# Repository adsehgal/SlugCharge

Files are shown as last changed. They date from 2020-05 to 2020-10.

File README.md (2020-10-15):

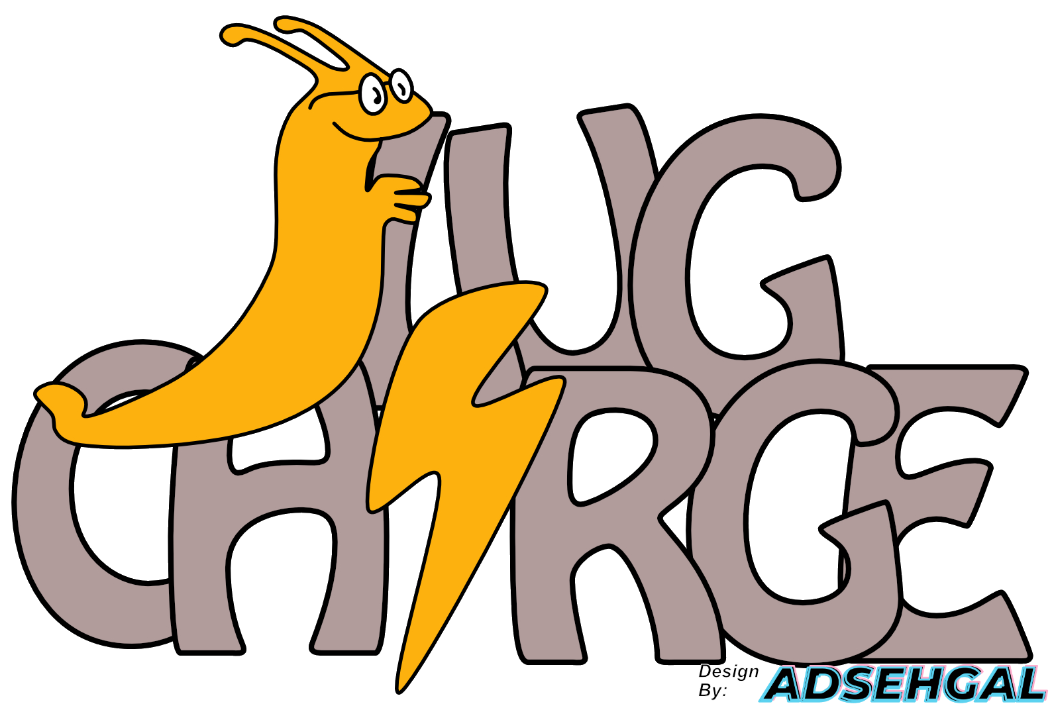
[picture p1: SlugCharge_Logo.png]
SlugCharge Logo

# *SlugCharge*

SlugCharge was a student run project geared towards helping the homeless communit of Santa Cruz, CA. The project was led by four Electrical Engineering students at the University of California, Santa Cruz. The team aimed towards providing solar powered charging stations to the community so they can stay conencted with family and potential employers that may turn their life around! 

### My Roles

* PCB Design
* Mechnical Design
* Graphic Design
* Video Creation

<!-- START OF PCB SECTION -->
### PCB Design

#### PCB #1 - Testbench V1.0
[Project Files](https://github.com/adsehgal/SlugCharge/tree/master/SlugCharge_Testbench_V1.0) - KiCad
* We first started with making a testbench that was able to run our code and interact with the required I/O </br>
    Requirements:</br>
    * Utilize the **ATmega2560** as the main processor
    * Be **easliy programmable** for future code updates
    * Contain **visual annunciators** for easy state tracking 
    * Utilize **breakout pins** for off-board I/O control
    * Should **not require off-board voltage regulation**
    * Should be easily **hand assembled**
    * Restricted to a **2-layer PCB**
* The design was started off with referring to the Arduino Mega Development board and adapted to fit the required I/O:
<p align="center">
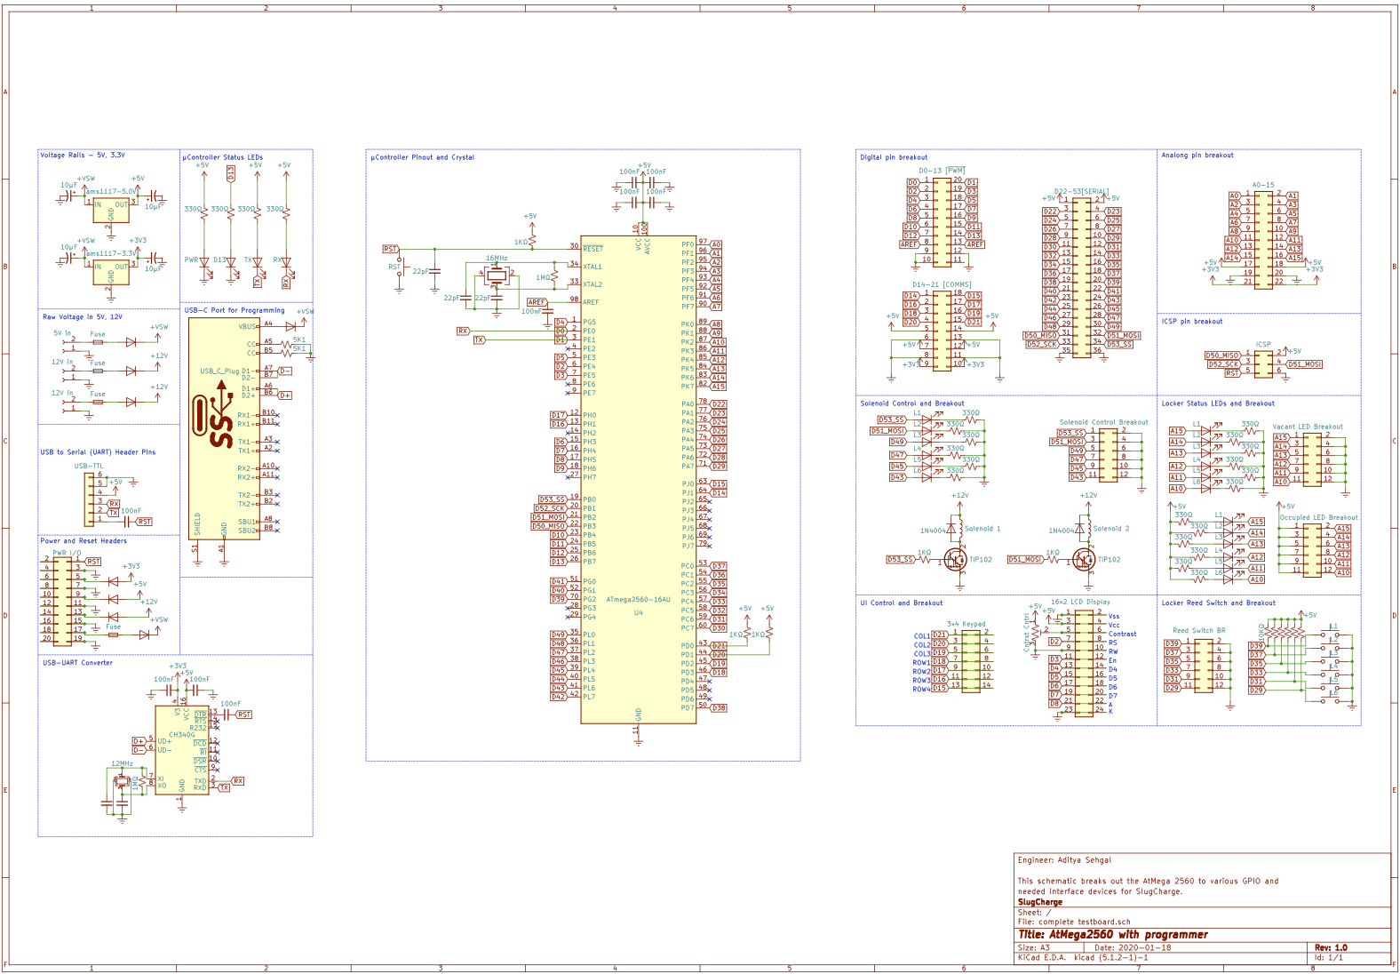
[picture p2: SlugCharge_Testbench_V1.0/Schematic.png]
  
</p>

* Next I moved onto laying out the PCB as per the requirements to get the following design:

</p>
<p align="center">
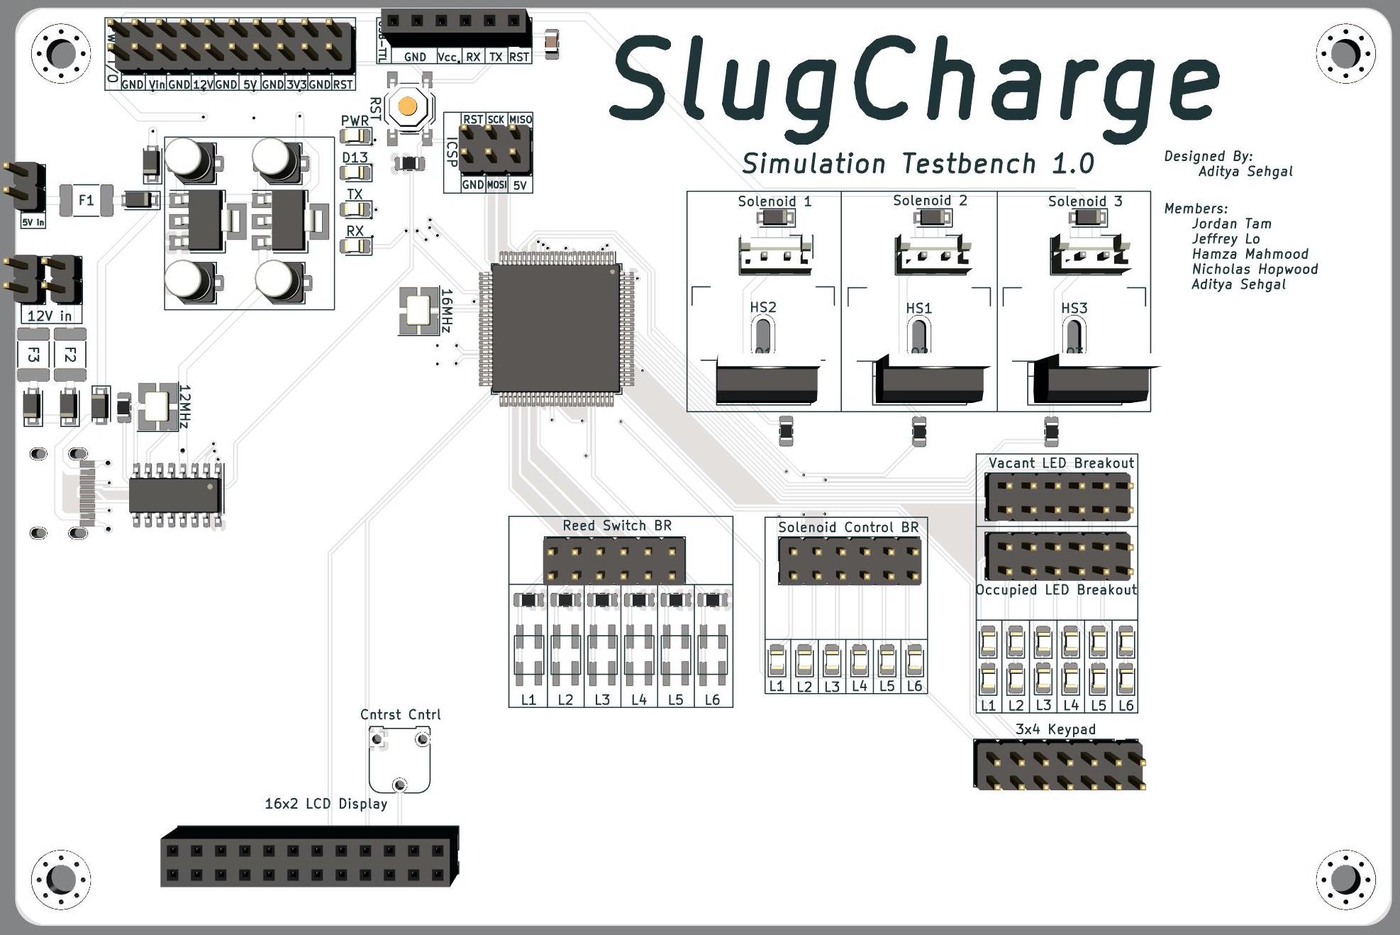
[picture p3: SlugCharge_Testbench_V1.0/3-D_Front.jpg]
  
</p>

#### PCB #2 - Motherboard V2.4
[Project Files](https://github.com/adsehgal/SlugCharge/tree/master/SlugCharge_Motherboard) - KiCad
* We followed the success of the testbench with a custom motherboard </br>
    Requirements:</br>
    * Utilize the **ATmega2560** as the main processor
    * Be **easliy programmable** for future code updates
    * Should **not require off-board voltage regulation**
    * Should **not be directly connected** to the individual lockers
    * Restricted to a **2-layer PCB**

To keep the motherboard physically isolated from the individual lockers, we decided to design a daughterboard for each locker that would connect to the motherboard via IDC cables

<p align="center">
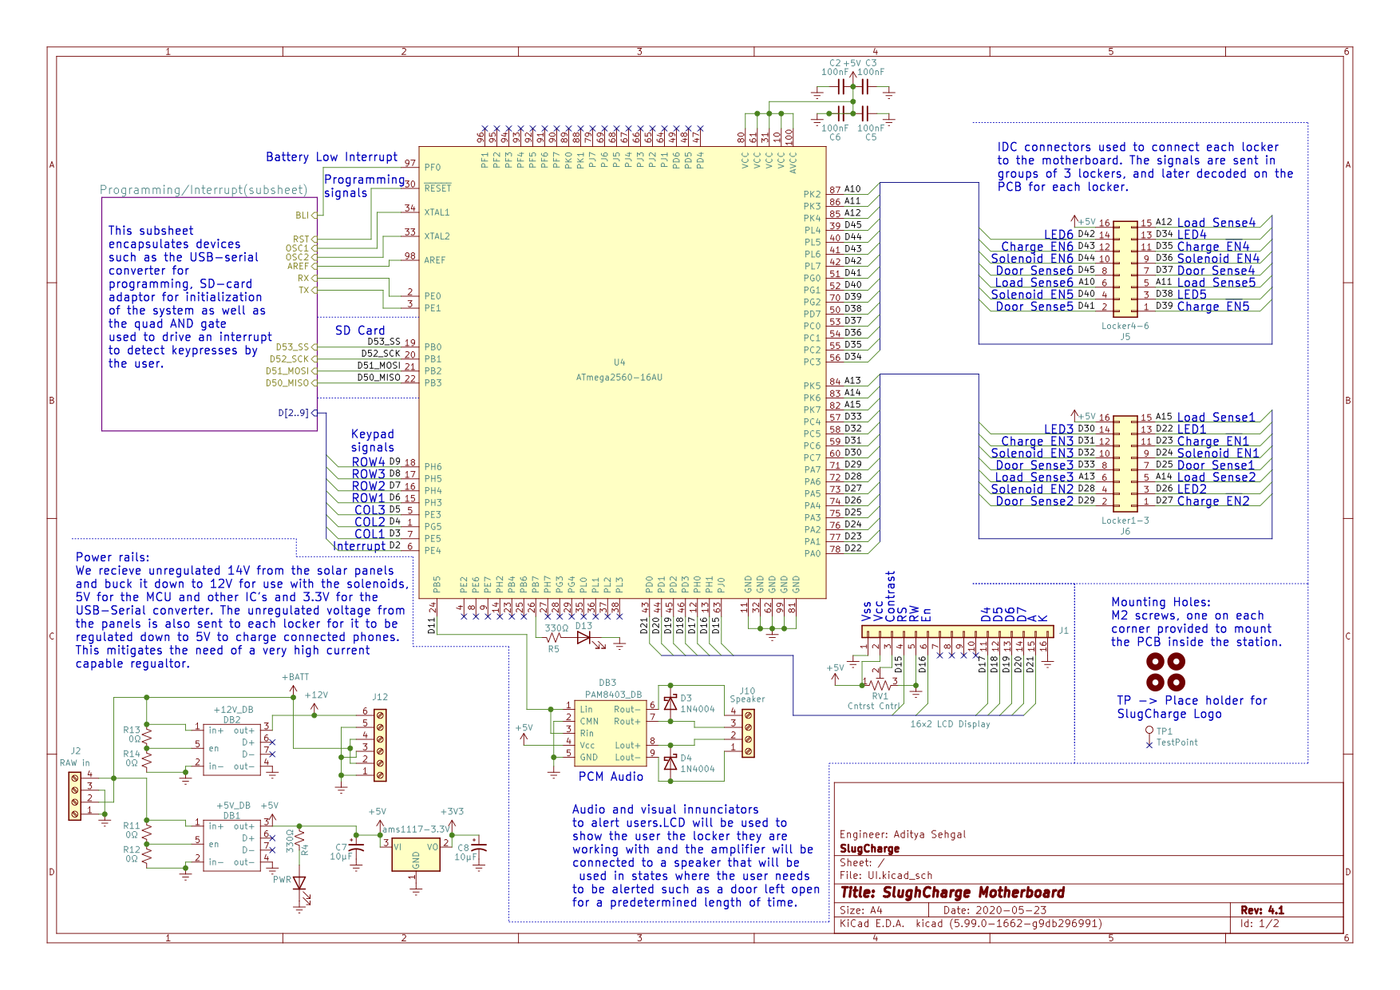
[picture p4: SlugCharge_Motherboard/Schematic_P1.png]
  
</p>
<p align="center">
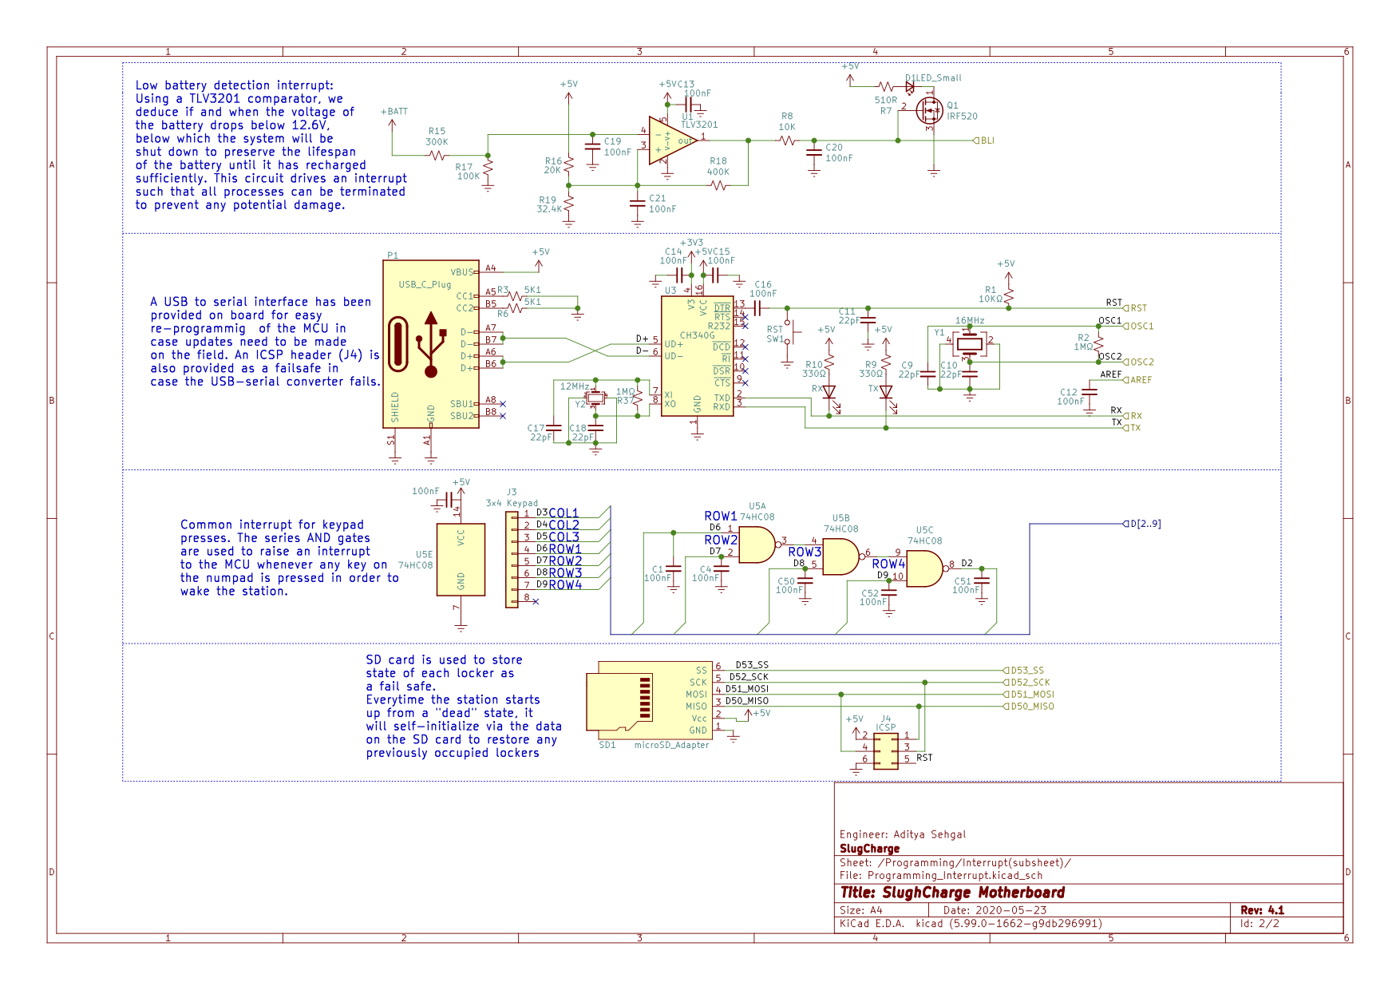
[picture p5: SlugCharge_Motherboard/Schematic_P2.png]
  
</p>

* Next I moved onto laying out the PCB as per the requirements to get the following design:
<p align="center">
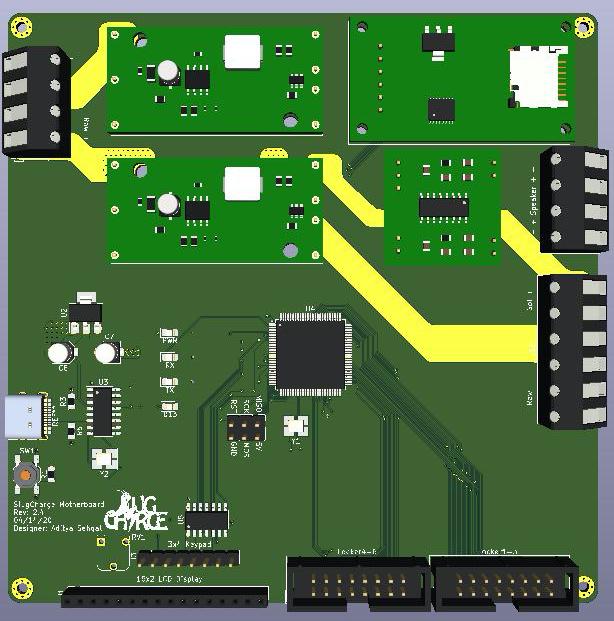
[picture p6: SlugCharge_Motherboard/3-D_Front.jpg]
  
</p>

#### PCB #3 - Daughterboard V4.0
[Project Files](https://github.com/adsehgal/SlugCharge/tree/master/SlugCharge_Daughterboard) - KiCad
* We followed the success of the testbench with a custom daughterboard </br>
    Requirements:</br>
    * Connect with the motherboard **using IDC cables**
    * Provide a **voltage regulator per locker** to charge devices
    * Should be **easily replacable**
    * Should **not contain any complex devices**
    * Restricted to a **2-layer PCB**

To charge the devices in each locker, we decided to give each of these PCBs a second voltage regulator PCB for easy servicability. This regulator was chose to be the [TPS62133](https://github.com/adsehgal/SlugCharge/tree/master/TPS62133)

<p align="center">
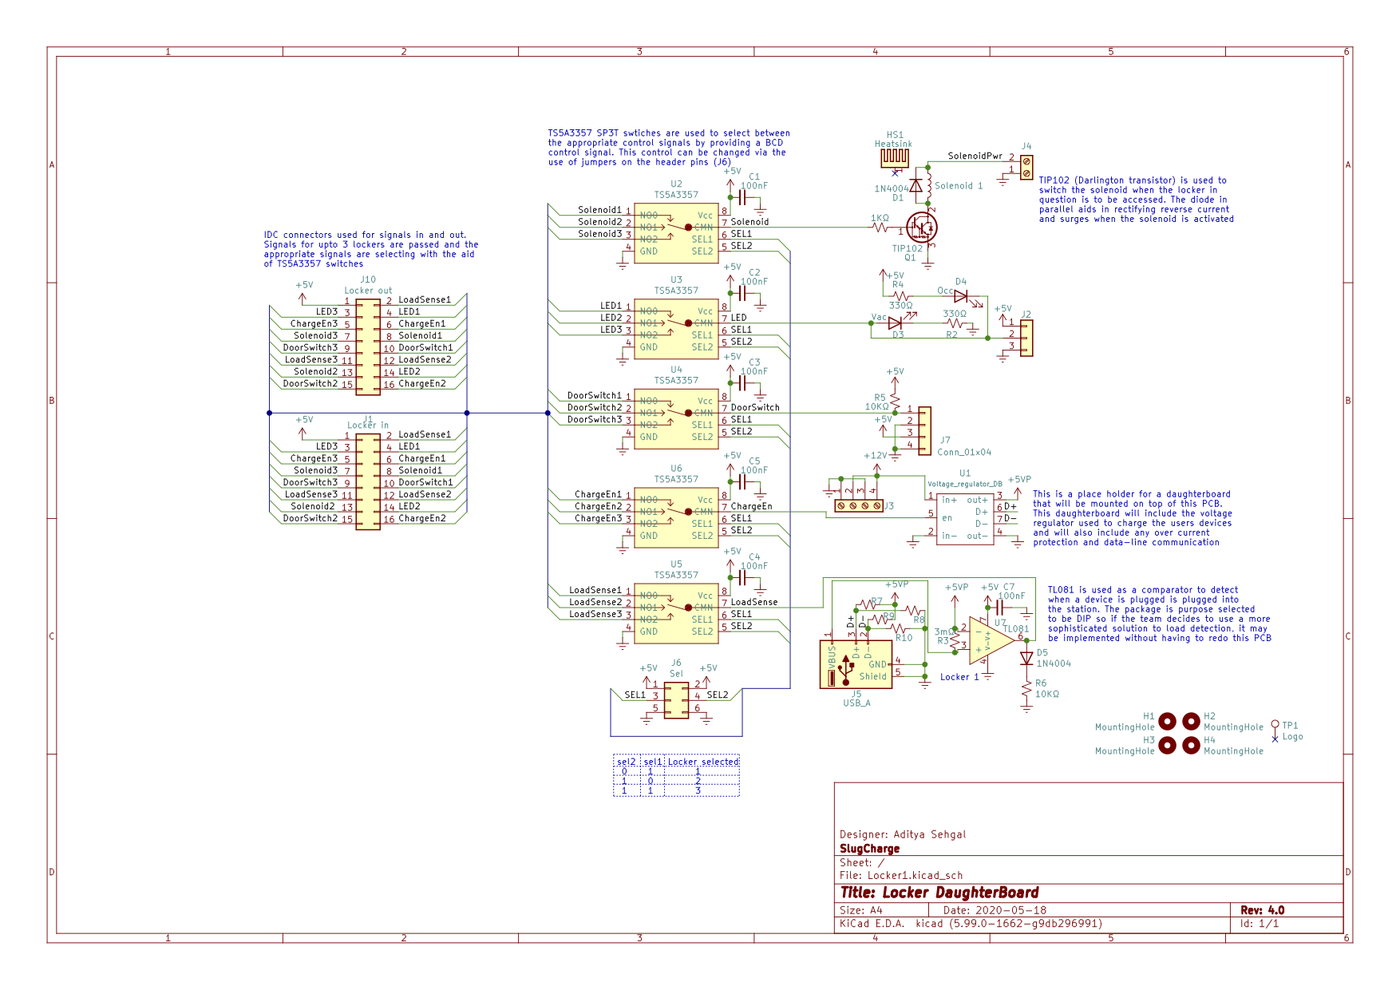
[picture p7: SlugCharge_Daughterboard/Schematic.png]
  
</p>

* Next I moved onto laying out the PCB as per the requirements to get the following design:
<p align="center">
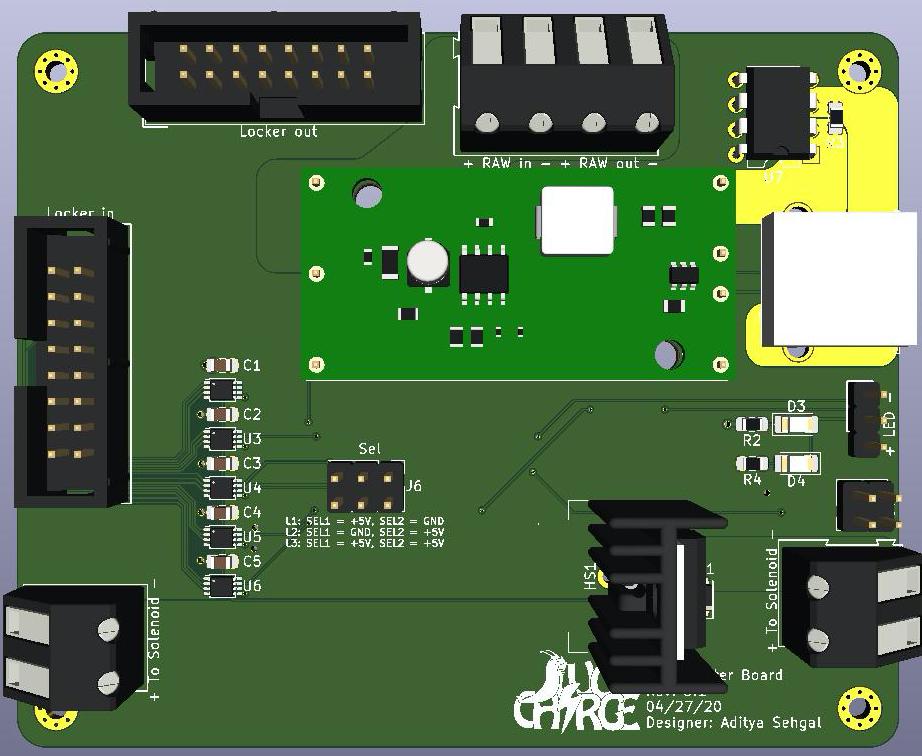
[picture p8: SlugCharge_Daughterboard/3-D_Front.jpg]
  
</p>
<!-- END OF PCB SECTION -->

<!--START OF  VOLTAGE REGULATOR -->
### Voltage Regulator selection

<!-- END OF VOLTAGE REGULATOR -->
[Regulator Comparison Sheet](https://github.com/adsehgal/SlugCharge/blob/master/Regulator_selection.pdf) - PDF</br>
[Regulator Design Files](https://github.com/adsehgal/SlugCharge/tree/master/TPS62133) - KiCad
* I decided to use the TPS62133 constant 5.0V switching regulator to charge connected devices. This regulator was selected for the following reasons:  </br>
  * Relatively low cost
  * Extremely high efficiency
  * Very low output ripple
  * On chip enable pin
  * High current capability
  
<!-- START OF MECH SECTION -->
### Mechanical Design
[Mechanical Drafts](https://github.com/adsehgal/SlugCharge/tree/master/Mechanical) - Fusion360
* Given the restrictions due to COVID-19, the team was unable to build the station, however we rendered a 3-D model for any future teams that may be intereste in taking up this project</br>
    Requirements:</br>
    * Be designed to accomodate the **average person height**
    * Hold at least **6 devices simultaneously**
    * Be resistant to **tampering**
    * **Solar Powered**

We drafted the 3-D model and orthographic drawings using Fusion360. This was done to aid future teams who may be interested in continuing this project

<p align="center">
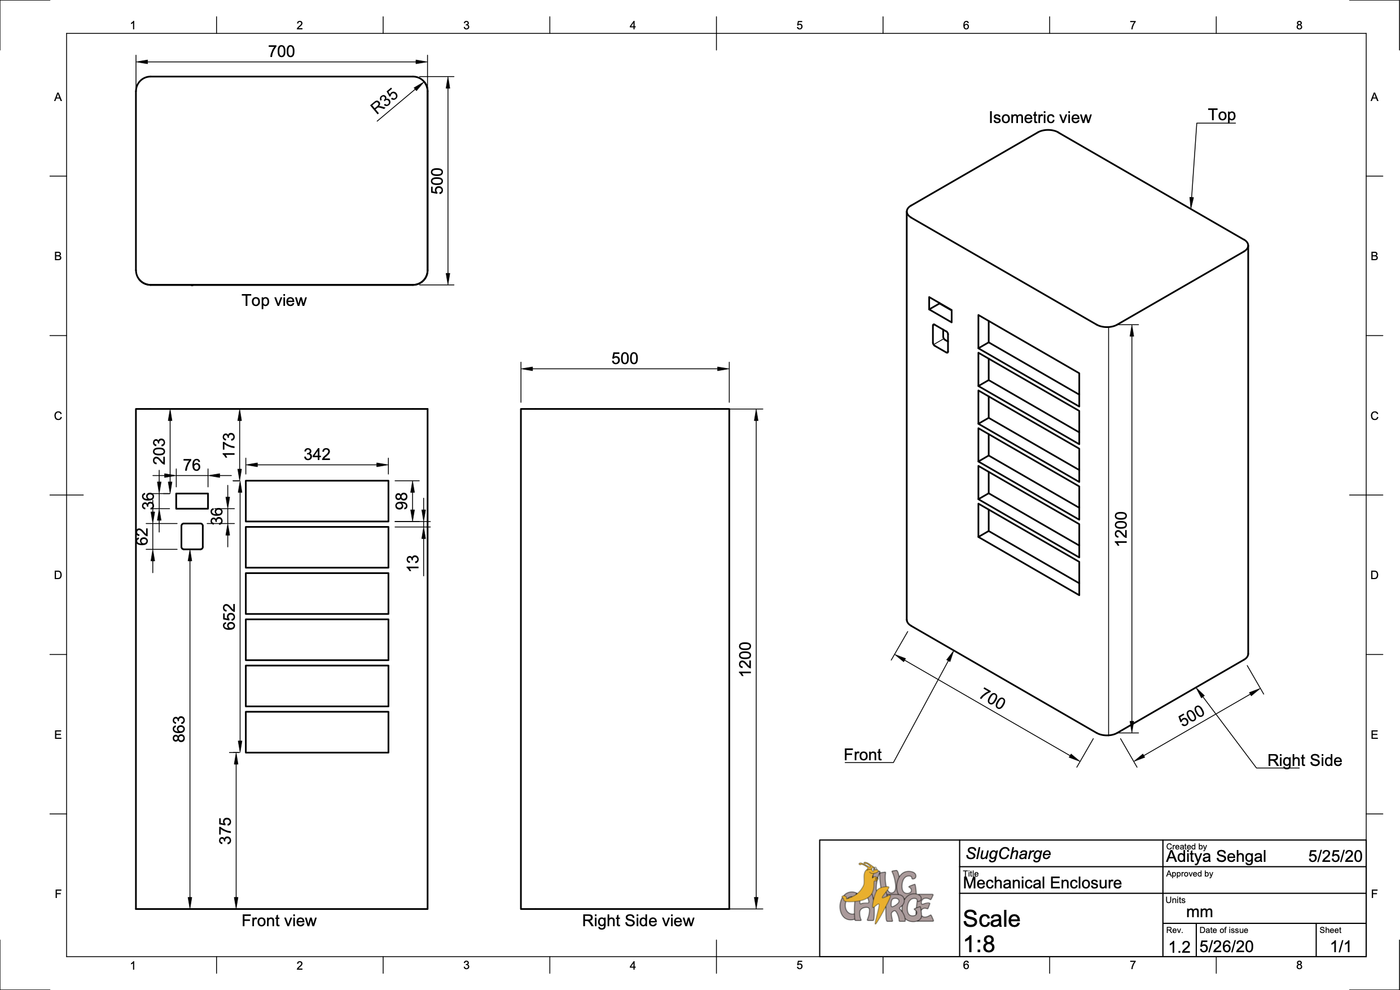
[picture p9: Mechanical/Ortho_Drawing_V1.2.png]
  
</p>
<p align="center">
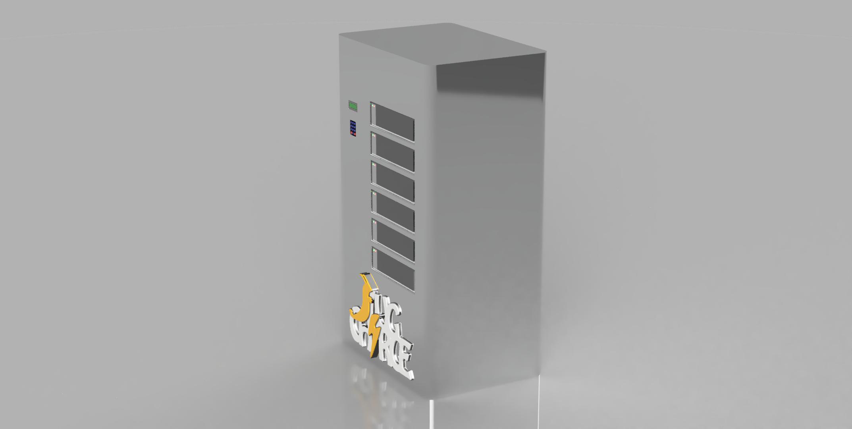
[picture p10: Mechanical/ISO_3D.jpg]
  
</p>

To educate the community how to use the station we developed two short instructional videos showing so. These can be downloaded via the following hyperlinks

* [Selecting a locker](https://github.com/adsehgal/SlugCharge/blob/master/Mechanical/Get_Device_Final.avi)
* [Retrieving your device](https://github.com/adsehgal/SlugCharge/blob/master/Mechanical/Select_Locker_FInal.avi)
<!-- END OF MECH SECTION -->

### Final Report
[The final team report can be found here](https://github.com/adsehgal/SlugCharge/blob/master/Final_report.pdf)

## Built With

* [KiCad](https://kicad-pcb.org/) - Used to design schematics and PCB layouts
* [Fusion 360](https://www.autodesk.com/products/fusion-360/overview) - Used to design mechanical drafts
* [Arduino IDE](https://www.arduino.cc/) - Used to code the charging station functionaility
* [Affinity Designer](http://affinity.serif.com/) - Used to design logos and other 2-D graphics
* [VSDC Video Editor](http://www.videosoftdev.com/) - Used to design education videos of the charging station

## Authors

* **Aditya Sehgal** - *Systems Integration lead, PCB Designer, Mechanical Drafter and Graphic Designer* - [AdSehgal](https://github.com/AdSehgal)

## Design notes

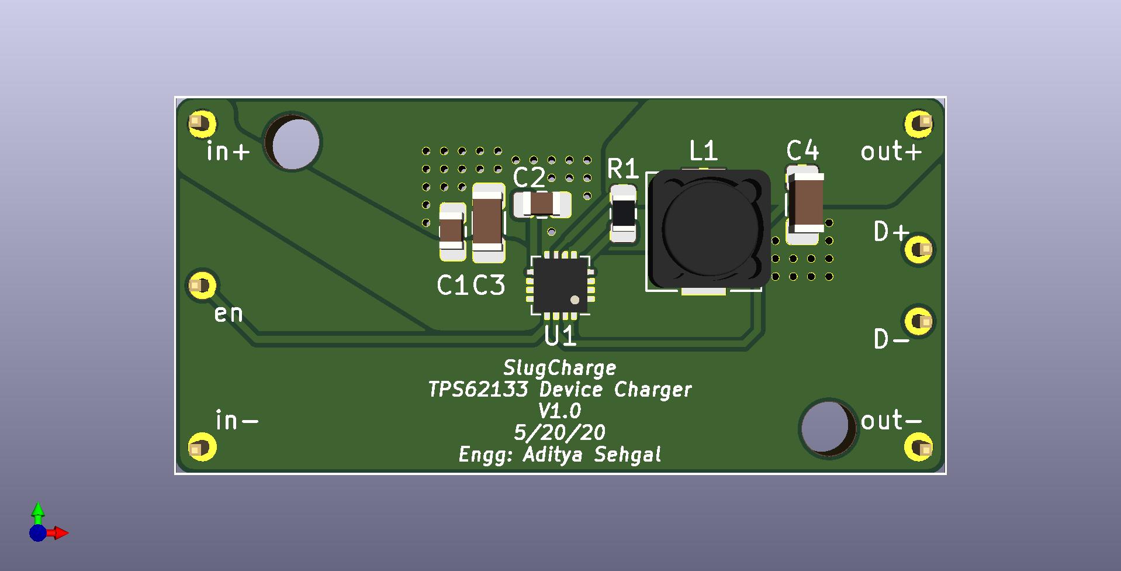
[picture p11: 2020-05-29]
TPS62133/Schematic & Layout PDFs/VReg_3D_Image.jpg

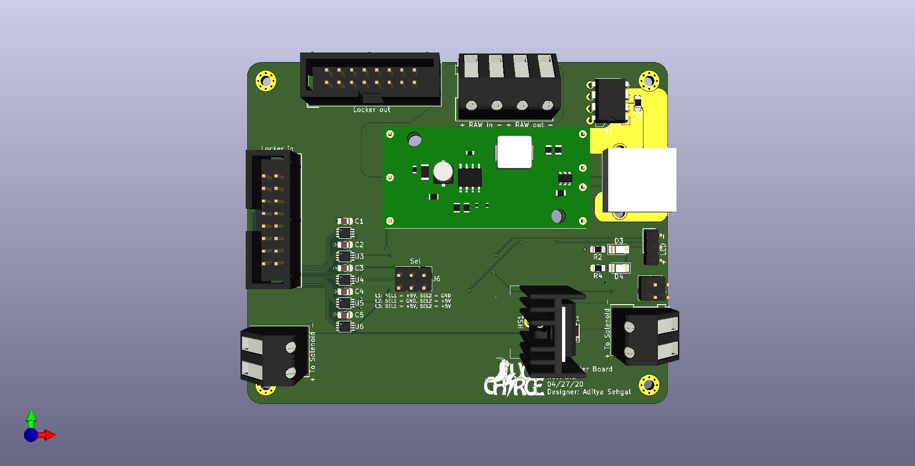
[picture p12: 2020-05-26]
SlugCharge_Daughterboard/Schematic&Layout PDFs/DB_3D_Image.jpg

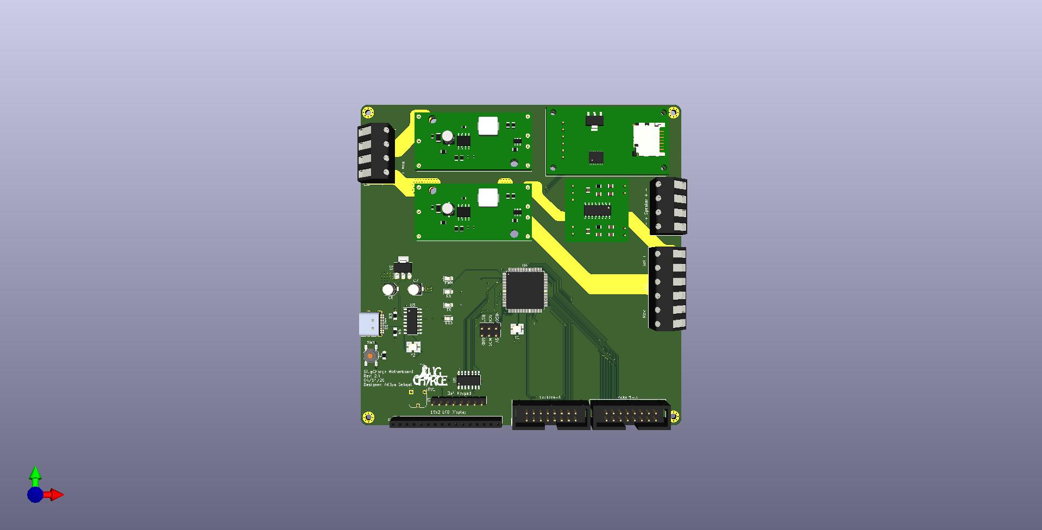
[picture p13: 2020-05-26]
SlugCharge_Motherboard/Schematic&Layout PDFs/MB_3D_Image.jpg

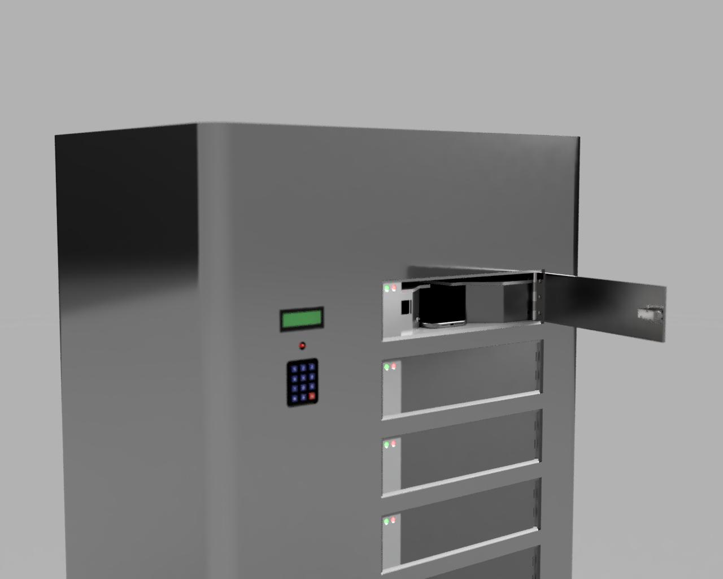
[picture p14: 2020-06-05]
3D Housing Model/3D_Open_W_Phone.jpg

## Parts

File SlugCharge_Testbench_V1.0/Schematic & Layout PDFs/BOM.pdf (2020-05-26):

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
A | B | C | D | E | F | G
Reference | Quantity | Value | KiCad Footprint | Standard Footprint | Datasheet | Purpose
C1 C4 C8 C7 | 4 | 10µF | Capacitor_SMD:C_Elec_4x5.4 | 4x5.4 SMD Cap | https://datasheet.lcsc.com/szlcsc/1810171406_ST-Semtech-CS1A470M-CRC54_C114447.pdf Voltage Regulation
C10 C9 C11 C18 C17 | 5 | 22pF | Capacitor_SMD:C_0805_2012Metric_Pad1.15x1.40mm_HandSolder 0805 | | https://datasheet.lcsc.com/szlcsc/1912111437_CCTC-TCC0805COG220J500BT_C376875.pdf Crystal
C5 C3 C2 C6 C12 C13 C14 C15 C16 9 | | 100nF | Capacitor_SMD:C_0805_2012Metric_Pad1.15x1.40mm_HandSolder 0805 | | https://datasheet.lcsc.com/szlcsc/1811061718_FH-Guangdong-Fenghua-Advanced-Tech-0805B104J500NT_C29926.pdf Voltage Regulation
D12 D22 D10 | 3 | L4 | LED_SMD:LED_0805_2012Metric_Pad1.15x1.40mm_HandSolder 0805 | | https://datasheet.lcsc.com/szlcsc/1811061716_Lite-On-LTST-C170GKT_C125090.pdf Locker Status
D13 | 1 | D13 | LED_SMD:LED_0805_2012Metric_Pad1.15x1.40mm_HandSolder 0805 | | https://datasheet.lcsc.com/szlcsc/1811061716_Lite-On-LTST-C170GKT_C125090.pdf System Status
D15 D23 D11 | 3 | L5 | LED_SMD:LED_0805_2012Metric_Pad1.15x1.40mm_HandSolder 0805 | | https://datasheet.lcsc.com/szlcsc/1811061716_Lite-On-LTST-C170GKT_C125090.pdf Locker Status
D16 D24 D14 | 3 | L6 | LED_SMD:LED_0805_2012Metric_Pad1.15x1.40mm_HandSolder 0805 | | https://datasheet.lcsc.com/szlcsc/1811061716_Lite-On-LTST-C170GKT_C125090.pdf Locker Status
D19 D18 D30 | 3 | 1N4004 | Diode_SMD:D_SOD-123F | SOD-123F | https://datasheet.lcsc.com/szlcsc/1810241423_Shandong-Jingdao-Microelectronics-1N4004W_C162734.pdf Flyback Diode
D2 D1 D26 D25 D28 D27 D3 D29 8 | | D | Diode_SMD:D_SOD-123F | SOD-123F | https://datasheet.lcsc.com/szlcsc/1810241423_Shandong-Jingdao-Microelectronics-1N4004W_C162734.pdf Reverse Voltage Protection
D6 D17 D4 | 3 | L1 | LED_SMD:LED_0805_2012Metric_Pad1.15x1.40mm_HandSolder 0805 | | https://datasheet.lcsc.com/szlcsc/1811061716_Lite-On-LTST-C170GKT_C125090.pdf Locker Status
D8 D20 D5 | 3 | L2 | LED_SMD:LED_0805_2012Metric_Pad1.15x1.40mm_HandSolder 0805 | | https://datasheet.lcsc.com/szlcsc/1811061716_Lite-On-LTST-C170GKT_C125090.pdf Locker Status
D9 D21 D7 | 3 | L3 | LED_SMD:LED_0805_2012Metric_Pad1.15x1.40mm_HandSolder 0805 | | https://datasheet.lcsc.com/szlcsc/1811061716_Lite-On-LTST-C170GKT_C125090.pdf Locker Status
F2 F1 F4 F3 | 4 | Fuse | Fuse:Fuse_1812_4532Metric_Pad1.30x3.40mm_HandSolder 1812 | | https://datasheet.lcsc.com/szlcsc/1912111437_Jinrui-Electronic-Materials-Co-JK-MSMD050_C369167.pdf Over Voltage Protection
H1 H2 H3 H4 | 4 | MountingHoleMountingHole:MountingHole_3.2mm_M3_Pad_Via M3 | | | N/A | Mounting
HS2 HS1 HS3 | 3 | Heatsink | Heatsink:TO-220 Vertical XSD C116600T0-220 HS | | https://datasheet.lcsc.com/szlcsc/1810010332_XSD-C116600_C116600.pdf Thermal Protection
J10 | 1 | USB-TTL | Connector_PinSocket_2.54mm:PinSocket_1x06_P2.54mm_Vertical 1x6 2.54mm | | N/A | Programming
J11 | 1 | Occupied LED Breakout Connector_PinHeader_2.54mm:PinHeader_2x06_P2.54mm_Vertical 2x6 2.54mm | | | N/A | Locker Status
J12 | 1 | PWR I/O | Connector_PinHeader_2.54mm:PinHeader_2x10_P2.54mm_Vertical 2x10 2.54mm | | N/A | Power
J13 | 1 | 16x2 LCD Display Connector_PinSocket_2.54mm:PinSocket_2x12_P2.54mm_Vertical 2x12 2.54mm | | | N/A | LCD
J14 | 1 | 3x4 Keypad | Connector_PinHeader_2.54mm:PinHeader_2x07_P2.54mm_Vertical 2x7 2.54mm | | N/A | Keypad
J15 | 1 | Reed Switch BRConnector_PinHeader_2.54mm:PinHeader_2x06_P2.54mm_Vertical 2x6 2.54mm | | | N/A | Reed Switch
J16 | 1 | ICSP | Connector_PinHeader_2.54mm:PinHeader_2x03_P2.54mm_Vertical 2x3 2.54mm | | N/A | Programming
J4 | 1 | 5V in | Connector_PinHeader_2.54mm:PinHeader_1x02_P2.54mm_Vertical 1x2 2.54mm | | N/A | Power
J6 J7 | 2 | 12V in | Connector_PinHeader_2.54mm:PinHeader_1x02_P2.54mm_Vertical 1x2 2.54mm | | N/A | Power
J8 | 1 | Solenoid Control Breakout Connector_PinHeader_2.54mm:PinHeader_2x06_P2.54mm_Vertical 2x6 2.54mm | | | N/A | Solenoid
J9 | 1 | Vacant LED Breakout Connector_PinHeader_2.54mm:PinHeader_2x06_P2.54mm_Vertical 2x6 2.54mm | | | N/A | Locker Status
L1 | 1 | Solenoid 1 | Connector_JST:JST_EH_B2B-EH-A_1x02_P2.50mm_Vertical 2.5mm JST | | https://datasheet.lcsc.com/szlcsc/1810291311_JST-Sales-America-B2B-XH-AM-LF-SN_C161869.pdf Solenoid
L2 | 1 | Solenoid 2 | Connector_JST:JST_EH_B2B-EH-A_1x02_P2.50mm_Vertical 2.5mm JST | | https://datasheet.lcsc.com/szlcsc/1810291311_JST-Sales-America-B2B-XH-AM-LF-SN_C161869.pdf Solenoid
L3 | 1 | Solenoid 3 | Connector_JST:JST_EH_B2B-EH-A_1x02_P2.50mm_Vertical 2.5mm JST | | https://datasheet.lcsc.com/szlcsc/1810291311_JST-Sales-America-B2B-XH-AM-LF-SN_C161869.pdf Solenoid
P1 | 1 | USB_C_Plug | Connector_USB:USB C C167321 | USB C C167321 | https://datasheet.lcsc.com/szlcsc/1811101520_Jing-Extension-of-the-Electronic-Co-C167321_C167321.pdf Programming

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
A | B | C | D | E | F | G
PWR1 | 1 | PWR | LED_SMD:LED_0805_2012Metric_Pad1.15x1.40mm_HandSolder 0805 | https://datasheet.lcsc.com/szlcsc/1811061716_Lite-On-LTST-C170GKT_C125090.pdf System Status
Q2 Q1 Q3 | 3 | TIP102 | Package_TO_SOT_THT:TO-220-3_Vertical T0-220 | www.irf.com/product-info/datasheets/data/irf540n.pdf Solenoid Control
R2 R37 | 2 | 1MΩ | Resistor_SMD:R_0805_2012Metric_Pad1.15x1.40mm_HandSolder 0805 | https://datasheet.lcsc.com/szlcsc/1811061718_FH-Guangdong-Fenghua-Advanced-Tech-RS-05K512JT_C115337.pdf Crystal Isolator
R3 R6 | 2 | 5.1KΩ | Resistor_SMD:R_0805_2012Metric_Pad1.15x1.40mm_HandSolder 0805 | https://datasheet.lcsc.com/szlcsc/1811061718_FH-Guangdong-Fenghua-Advanced-Tech-RS-05K512JT_C115337.pdf USB CC
R31 R32 R33 R34 R35 R36 6 | | 10KΩ | Resistor_SMD:R_0805_2012Metric_Pad1.15x1.40mm_HandSolder 0805 | https://datasheet.lcsc.com/szlcsc/1811061718_FH-Guangdong-Fenghua-Advanced-Tech-RS-05K512JT_C115337.pdf Current Limiting
R4 R5 R9 R10 R13 R15 R16 R19 R21 R22 R23 R24 R25 R26 R29 R30 R11 R12 R14 R17 R18 R20 22 | | 330Ω | Resistor_SMD:R_0805_2012Metric_Pad1.15x1.40mm_HandSolder 0805 | https://datasheet.lcsc.com/szlcsc/1811061718_FH-Guangdong-Fenghua-Advanced-Tech-RS-05K512JT_C115337.pdf Current Limiting
R8 R7 R1 R28 R27 R38 | 6 | 1KΩ | Resistor_SMD:R_0805_2012Metric_Pad1.15x1.40mm_HandSolder 0805 | https://datasheet.lcsc.com/szlcsc/1811061718_FH-Guangdong-Fenghua-Advanced-Tech-RS-05K512JT_C115337.pdf Current Limiting
RV1 | 1 | 10KΩ | Potentiometer_THT:Potentiometer_Runtron_RM-065_Vertical RM65 | https://www.amazon.com/gp/product/B00SWK15KE/ref=ppx_yo_dt_b_asin_title_o00_s00?ie=UTF8&psc=1 Contrast
RX1 | 1 | RX | LED_SMD:LED_0805_2012Metric_Pad1.15x1.40mm_HandSolder 0805 | https://datasheet.lcsc.com/szlcsc/1811061718_FH-Guangdong-Fenghua-Advanced-Tech-RS-05K512JT_C115337.pdf System Status
SW1 | 1 | RST | Button_Switch_SMD:SW_SPST_TL3342 TL3342 | https://datasheet.lcsc.com/szlcsc/1811082127_Korean-Hroparts-Elec-K2-1187SQ-A4SW-06_C92584.pdf System Reset
SW2 | 1 | L1 | Button_Switch_SMD:PTS810_4.2x3.2PTS810 | https://datasheet.lcsc.com/szlcsc/1811092141_C-K-PTS810SJM250SMTRLFS_C116501.pdf Door Simulation
SW3 | 1 | L2 | Button_Switch_SMD:PTS810_4.2x3.2PTS810 | https://datasheet.lcsc.com/szlcsc/1811092141_C-K-PTS810SJM250SMTRLFS_C116501.pdf Door Simulation
SW4 | 1 | L3 | Button_Switch_SMD:PTS810_4.2x3.2PTS810 | https://datasheet.lcsc.com/szlcsc/1811092141_C-K-PTS810SJM250SMTRLFS_C116501.pdf Door Simulation
SW5 | 1 | L4 | Button_Switch_SMD:PTS810_4.2x3.2PTS810 | https://datasheet.lcsc.com/szlcsc/1811092141_C-K-PTS810SJM250SMTRLFS_C116501.pdf Door Simulation
SW6 | 1 | L5 | Button_Switch_SMD:PTS810_4.2x3.2PTS810 | https://datasheet.lcsc.com/szlcsc/1811092141_C-K-PTS810SJM250SMTRLFS_C116501.pdf Door Simulation
SW7 | 1 | L6 | Button_Switch_SMD:PTS810_4.2x3.2PTS810 | https://datasheet.lcsc.com/szlcsc/1811092141_C-K-PTS810SJM250SMTRLFS_C116501.pdf Door Simulation
TX1 | 1 | TX | LED_SMD:LED_0805_2012Metric_Pad1.15x1.40mm_HandSolder 0805 | https://datasheet.lcsc.com/szlcsc/1811061718_FH-Guangdong-Fenghua-Advanced-Tech-RS-05K512JT_C115337.pdf System Status
U1 | 1 | ams1117-5.0VPackage_TO_SOT_SMD:SOT-223-3_TabPin2 SOT-223 | | https://datasheet.lcsc.com/szlcsc/1912111437_UMW-Youtai-Semiconductor-Co-Ltd-AMS1117-5-0_C347223.pdf Voltage Regulation
U2 | 1 | ams1117-3.3VPackage_TO_SOT_SMD:SOT-223-3_TabPin2 SOT-223 | | https://datasheet.lcsc.com/szlcsc/1912111437_UMW-Youtai-Semiconductor-Co-Ltd-AMS1117-5-0_C347223.pdf Voltage Regulation
U3 | 1 | CH340G | Package_SO:SOIC-16_3.9x9.9mm_P1.27mm SOIC-16 | https://datasheet.lcsc.com/szlcsc/1811130504_WCH-Jiangsu-Qin-Heng-CH340G_C14267.pdf UART
U4 | 1 | ATmega2560-16AU Package_QFP:TQFP-100_14x14mm_P0.5mm TQFP-100 | | www.microchip.com/downloads/en/DeviceDoc/Atmel-2549-8-bit-AVR-Microcontroller-ATmega640-1280-1281-2560-2561_datasheet.pdf µcontroller
Y1 | 1 | 16MHz | Crystal:Crystal_SMD_3225-4Pin_3.2x2.5mm_HandSoldering 3225-4pin | https://datasheet.lcsc.com/szlcsc/1912111437_JGHC-S3216000201060_C426974.pdf Clock
Y2 | 1 | 12MHz | Crystal:Crystal_SMD_3225-4Pin_3.2x2.5mm_HandSoldering 3225-4pin | https://datasheet.lcsc.com/szlcsc/1912111437_JGHC-S3216000201060_C426974.pdf Clock

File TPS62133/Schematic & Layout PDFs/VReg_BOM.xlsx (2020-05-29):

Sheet: Sheet1
Id | Designator | Part | Package | Quantity | Designation
1 | C4 | 22uF 1206 Capacitor | C_1206_3216Metric_Pad1.42x1.75mm_HandSolder | 1 | 22µF
2 | L1 | 2.2uh Inductor | L_6.3x6.3_H3 | 1 | 2.2µH
3 | U1 | TPS62133 | VQFN-16-1EP_3x3mm_P0.5mm_EP1.68x1.68mm_ThermalVias | 1 | TPS62133
4 | R1 | 100K 0805 Resistor | R_0805_2012Metric_Pad1.15x1.40mm_HandSolder | 1 | 100K
5 | C3 | 10uF 1206 Cap | C_1206_3216Metric_Pad1.42x1.75mm_HandSolder | 1 | 10µF
6 | C2 | 620pF 0805 Capacitor | C_0805_2012Metric_Pad1.15x1.40mm_HandSolder | 1 | 620pF
7 | C1 | 100nF 0805 Capacitor | C_0805_2012Metric_Pad1.15x1.40mm_HandSolder | 1 | 100nF

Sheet: VReg_BOM
Id;"Designator";"Package";"Quantity";"Designation";"Supplier and ref";
1;"DB1";"DB_43x21";1;"DB_42x21";;;
2;"C4";"C_1206_3216Metric_Pad1.42x1.75mm_HandSolder";1;"22ÂµF";;;
3;"L1";"L_6.3x6.3_H3";1;"2.2ÂµH";;;
4;"U1";"VQFN-16-1EP_3x3mm_P0.5mm_EP1.68x1.68mm_ThermalVias";1;"TPS62133";;;
5;"R1";"R_0805_2012Metric_Pad1.15x1.40mm_HandSolder";1;"100K";;;
6;"C3";"C_1206_3216Metric_Pad1.42x1.75mm_HandSolder";1;"10ÂµF";;;
7;"C2";"C_0805_2012Metric_Pad1.15x1.40mm_HandSolder";1;"620pF";;;
8;"C1";"C_0805_2012Metric_Pad1.15x1.40mm_HandSolder";1;"100nF";;;

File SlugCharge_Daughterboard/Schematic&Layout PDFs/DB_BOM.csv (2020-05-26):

Id | Designator | Package | Quantity | Designation | Supplier and ref
1 | J6 | PinHeader_2x03_P2.54mm_Vertical | 1 | Sel
2 | U7 | DIP-8_W7.62mm | 1 | TL081
3 | U1 | LM2576_DB | 1 | LM2576_DB
4 | U2,U6,U5,U4,U3 | VSSOP-8_2.4x2.1mm_P0.5mm | 5 | TS5A3357
5 | C5,C4,C3,C2,C1,C7 | C_0805_2012Metric_Pad1.15x1.40mm_HandSolder | 6 | 100nF
6 | HS1 | TO-220_Heatsink | 1 | Heatsink
7 | J5 | USB_A_Stewart_SS-52100-001_Horizontal | 1 | USB_A
8 | J3 | TerminalBlock_Altech_AK300-4_P5.00mm | 1 | Unreg 12V - charge
9 | J1 | IDC-Header_2x08_P2.54mm_Vertical | 1 | Locker in
10 | J2 | PinHeader_1x03_P2.54mm_Vertical | 1 | Conn_01x04
11 | J10 | IDC-Header_2x08_P2.54mm_Vertical | 1 | Locker out
12 | L1 | TerminalBlock_Altech_AK300-2_P5.00mm | 1 | Solenoid 1
13 | J4 | TerminalBlock_Altech_AK300-2_P5.00mm | 1 | Solenoid Power
14 | R1 | R_0805_2012Metric_Pad1.15x1.40mm_HandSolder | 1 | 1KΩ
15 | R10,R9,R8,R7,R6,R5 | R_0805_2012Metric_Pad1.15x1.40mm_HandSolder | 6 | 10KΩ
16 | TP1 | logoinv | 1 | TestPoint
17 | J7 | PinHeader_2x02_P2.54mm_Vertical | 1 | Conn_01x04
18 | D5,D1 | D_SOD-123F | 2 | 1N4004
19 | H4,H3,H2,H1 | MountingHole_2.2mm_M2_Pad_Via | 4 | MountingHole
20 | R4,R2 | R_0805_2012Metric_Pad1.15x1.40mm_HandSolder | 2 | 330Ω
21 | R3 | R_0805_2012Metric_Pad1.15x1.40mm_HandSolder | 1 | 3mΩ
22 | Q1 | TO-220-3_Vertical | 1 | TIP102
23 | D4 | LED_1206_3216Metric_Pad1.42x1.75mm_HandSolder | 1 | Occ
24 | D3 | LED_1206_3216Metric_Pad1.42x1.75mm_HandSolder | 1 | Vac

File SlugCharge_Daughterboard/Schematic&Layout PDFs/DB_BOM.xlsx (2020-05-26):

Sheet: Sheet1
Id | Designator | Part | Package | Quantity | Designation
1 | J6 | 2x3 2.54mm Header - Locker Select | PinHeader_2x03_P2.54mm_Vertical | 1 | Sel
2 | U7 | TL081 | DIP-8_W7.62mm | 1 | TL081
3 | U1 | Voltage Regulator Board | Voltage Regulator Board (Custom) | 1 | LM2576_DB
4 | U2,U6,U5,U4,U3 | TS5A3357 | VSSOP-8_2.4x2.1mm_P0.5mm | 5 | TS5A3357
5 | C5,C4,C3,C2,C1,C7 | 100nF 0805 Capacitor | C_0805_2012Metric_Pad1.15x1.40mm_HandSolder | 6 | 100nF
6 | HS1 | TO-220 Heatsink | TO-220_Heatsink | 1 | Heatsink
7 | J5 | USB A Port | USB_A_Stewart_SS-52100-001_Horizontal | 1 | USB_A
8 | J3 | 1x4 Terminal Block P=5.0mm | TerminalBlock_Altech_AK300-4_P5.00mm | 1 | Unreg 12V - charge
9 | J1 | 2x8 IDC Connector P=2.54mm | IDC-Header_2x08_P2.54mm_Vertical | 1 | Locker in
10 | J2 | 1x3 2.54mm Header | PinHeader_1x03_P2.54mm_Vertical | 1 | Conn_01x04
11 | J10 | 2x8 IDC Connector P=2.54mm | IDC-Header_2x08_P2.54mm_Vertical | 1 | Locker out
12 | L1 | 1x2 Terminal Block P=2.54mm | TerminalBlock_Altech_AK300-2_P5.00mm | 1 | Solenoid 1
13 | J4 | 1x2 Terminal Block P=2.54mm | TerminalBlock_Altech_AK300-2_P5.00mm | 1 | Solenoid Power
14 | R1 | 1K 0805 Resistor | R_0805_2012Metric_Pad1.15x1.40mm_HandSolder | 1 | 1K
15 | R10,R9,R8,R7,R6,R5 | 10K 0805 Resistor | R_0805_2012Metric_Pad1.15x1.40mm_HandSolder | 6 | 10K
17 | J7 | 1x4 2.54mm Header | PinHeader_2x02_P2.54mm_Vertical | 1 | Conn_01x04
18 | D5,D1 | 1N4004 | D_SOD-123F | 2 | 1N4004
19 | H4,H3,H2,H1 | Mounting Hole | MountingHole_2.2mm_M2_Pad_Via | 4 | MountingHole
20 | R4,R2 | 330R 0805 Resistor | R_0805_2012Metric_Pad1.15x1.40mm_HandSolder | 2 | 330R
21 | R3 | 3mR 0805 Resistor | R_0805_2012Metric_Pad1.15x1.40mm_HandSolder | 1 | 3mR
22 | Q1 | TIP102 | TO-220-3_Vertical | 1 | TIP102
23 | D4 | 1206 LED | LED_1206_3216Metric_Pad1.42x1.75mm_HandSolder | 1 | Occ
24 | D3 | 1206 LED | LED_1206_3216Metric_Pad1.42x1.75mm_HandSolder | 1 | Vac

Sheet: DB_BOM
Id;"Designator";"Package";"Quantity";"Designation";"Supplier and ref";
1;"J6";"PinHeader_2x03_P2.54mm_Vertical";1;"Sel";;;
2;"U7";"DIP-8_W7.62mm";1;"TL081";;;
3;"U1";"LM2576_DB";1;"LM2576_DB";;;
4;"U2 | U6 | U5 | U4 | U3";"VSSOP-8_2.4x2.1mm_P0.5mm";5;"TS5A3357";;;
5;"C5 | C4 | C3 | C2 | C1 | C7";"C_0805_2012Metric_Pad1.15x1.40mm_HandSolder";6;"100nF";;;
6;"HS1";"TO-220_Heatsink";1;"Heatsink";;;
7;"J5";"USB_A_Stewart_SS-52100-001_Horizontal";1;"USB_A";;;
8;"J3";"TerminalBlock_Altech_AK300-4_P5.00mm";1;"Unreg 12V - charge";;;
9;"J1";"IDC-Header_2x08_P2.54mm_Vertical";1;"Locker in";;;
10;"J2";"PinHeader_1x03_P2.54mm_Vertical";1;"Conn_01x04";;;
11;"J10";"IDC-Header_2x08_P2.54mm_Vertical";1;"Locker out";;;
12;"L1";"TerminalBlock_Altech_AK300-2_P5.00mm";1;"Solenoid 1";;;
13;"J4";"TerminalBlock_Altech_AK300-2_P5.00mm";1;"Solenoid Power";;;
14;"R1";"R_0805_2012Metric_Pad1.15x1.40mm_HandSolder";1;"1KÎ©";;;
15;"R10 | R9 | R8 | R7 | R6 | R5";"R_0805_2012Metric_Pad1.15x1.40mm_HandSolder";6;"10KÎ©";;;
16;"TP1";"logoinv";1;"TestPoint";;;
17;"J7";"PinHeader_2x02_P2.54mm_Vertical";1;"Conn_01x04";;;
18;"D5 | D1";"D_SOD-123F";2;"1N4004";;;
19;"H4 | H3 | H2 | H1";"MountingHole_2.2mm_M2_Pad_Via";4;"MountingHole";;;
20;"R4 | R2";"R_0805_2012Metric_Pad1.15x1.40mm_HandSolder";2;"330Î©";;;
21;"R3";"R_0805_2012Metric_Pad1.15x1.40mm_HandSolder";1;"3mÎ©";;;
22;"Q1";"TO-220-3_Vertical";1;"TIP102";;;
23;"D4";"LED_1206_3216Metric_Pad1.42x1.75mm_HandSolder";1;"Occ";;;
24;"D3";"LED_1206_3216Metric_Pad1.42x1.75mm_HandSolder";1;"Vac";;;

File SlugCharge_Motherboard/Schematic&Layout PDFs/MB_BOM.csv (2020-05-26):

Id | Designator | Package | Quantity | Designation | Supplier and ref
1 | RV1 | Potentiometer_Runtron_RM-065_Vertical | 1 | Cntrst Cntrl
2 | U5 | SOIC-14_3.9x8.7mm_P1.27mm | 1 | 74HC08
3 | J5 | IDC-Header_2x08_P2.54mm_Vertical | 1 | Locker4-6
4 | J6 | IDC-Header_2x08_P2.54mm_Vertical | 1 | Locker1-3
5 | J12 | TerminalBlock_RND_205-00060_1x06_P5.00mm_45Degree | 1
6 | J10 | TerminalBlock_Altech_AK300-4_P5.00mm | 1 | Speaker
7 | J2 | TerminalBlock_Altech_AK300-4_P5.00mm | 1 | RAW in
8 | P1 | USB_C_SMD | 1 | USB_C_Plug
9 | DB3 | PAM8403_DB | 1 | PAM8403_DB
10 | SD1 | Micro_SD_Module | 1 | microSD_Adapter
11 | DB2 | LM2576_DB | 1 | +12V_DB
12 | DB1 | LM2576_DB | 1 | +5V_DB
13 | U4 | TQFP-100_14x14mm_P0.5mm | 1 | ATmega2560-16AU
14 | R14,R13,R12,R11 | R_0805_2012Metric_Pad1.15x1.40mm_HandSolder | 4 | 0Ω
15 | U2 | SOT-223 | 1 | ams1117-3.3V
16 | Y2 | Crystal_SMD_3225-4Pin_3.2x2.5mm_HandSoldering | 1 | 12MHz
17 | Y1 | Crystal_SMD_3225-4Pin_3.2x2.5mm_HandSoldering | 1 | 16MHz
18 | U3 | SOIC-16_3.9x9.9mm_P1.27mm | 1 | CH340G
19 | TX1 | LED_0805_2012Metric_Pad1.15x1.40mm_HandSolder | 1 | TX
20 | SW1 | SW_SPST_TL3342 | 1 | RST
21 | RX1 | LED_0805_2012Metric_Pad1.15x1.40mm_HandSolder | 1 | RX
22 | R37,R2 | R_0805_2012Metric_Pad1.15x1.40mm_HandSolder | 2 | 1MΩ
23 | R10,R9,R5,R4 | R_0805_2012Metric_Pad1.15x1.40mm_HandSolder | 4 | 330Ω
24 | R6,R3 | R_0805_2012Metric_Pad1.15x1.40mm_HandSolder | 2 | 5K1
25 | R1 | R_0805_2012Metric_Pad1.15x1.40mm_HandSolder | 1 | 1KΩ
26 | PWR1 | LED_0805_2012Metric_Pad1.15x1.40mm_HandSolder | 1 | PWR
27 | J4 | PinHeader_2x03_P2.54mm_Vertical | 1 | Conn_02x03_Odd_Even
28 | J3 | PinHeader_1x08_P2.54mm_Vertical | 1 | 3x4 Keypad
29 | J1 | PinSocket_1x16_P2.54mm_Vertical | 1 | 16x2 LCD Display
30 | H4,H3,H2,H1 | MountingHole_2.2mm_M2_Pad_Via | 4 | MountingHole
31 | D13 | LED_0805_2012Metric_Pad1.15x1.40mm_HandSolder | 1 | D13
32 | D4,D3 | D_SOD-123F | 2 | D_Schottky
33 | C52,C51,C50,C37,C16,C15,C14,C12,C6,C5,C4,C3,C2,C1 | C_0805_2012Metric_Pad1.15x1.40mm_HandSolder | 14 | 100nF
34 | C18,C17,C11,C10,C9 | C_0805_2012Metric_Pad1.15x1.40mm_HandSolder | 5 | 22pF
35 | C8,C7 | C_Elec_4x5.4 | 2 | 10µF
36 | TP1 | logoinv | 1 | TestPoint

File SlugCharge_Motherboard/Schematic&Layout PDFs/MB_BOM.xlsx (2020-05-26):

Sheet: Sheet2
Id | Designator | Package | Quantity | Designation | Supplier and ref | Column1 | _1
1 | RV1 | Potentiometer_Runtron_RM-065_Vertical | 1 | Cntrst Cntrl
2 | U5 | SOIC-14_3.9x8.7mm_P1.27mm | 1 | 74HC08
3 | J5 | IDC-Header_2x08_P2.54mm_Vertical | 1 | Locker4-6
4 | J6 | IDC-Header_2x08_P2.54mm_Vertical | 1 | Locker1-3
5 | J12 | TerminalBlock_RND_205-00060_1x06_P5.00mm_45Degree | 1
6 | J10 | TerminalBlock_Altech_AK300-4_P5.00mm | 1 | Speaker
7 | J2 | TerminalBlock_Altech_AK300-4_P5.00mm | 1 | RAW in
8 | P1 | USB_C_SMD | 1 | USB_C_Plug
9 | DB3 | PAM8403_DB | 1 | PAM8403_DB
10 | SD1 | Micro_SD_Module | 1 | microSD_Adapter
11 | DB2 | LM2576_DB | 1 | +12V_DB
12 | DB1 | LM2576_DB | 1 | +5V_DB
13 | U4 | TQFP-100_14x14mm_P0.5mm | 1 | ATmega2560-16AU
14 | R14,R13,R12,R11 | R_0805_2012Metric_Pad1.15x1.40mm_HandSolder | 4 | 0Î©
15 | U2 | SOT-223 | 1 | ams1117-3.3V
16 | Y2 | Crystal_SMD_3225-4Pin_3.2x2.5mm_HandSoldering | 1 | 12MHz
17 | Y1 | Crystal_SMD_3225-4Pin_3.2x2.5mm_HandSoldering | 1 | 16MHz
18 | U3 | SOIC-16_3.9x9.9mm_P1.27mm | 1 | CH340G
19 | TX1 | LED_0805_2012Metric_Pad1.15x1.40mm_HandSolder | 1 | TX
20 | SW1 | SW_SPST_TL3342 | 1 | RST
21 | RX1 | LED_0805_2012Metric_Pad1.15x1.40mm_HandSolder | 1 | RX
22 | R37,R2 | R_0805_2012Metric_Pad1.15x1.40mm_HandSolder | 2 | 1MÎ©
23 | R10,R9,R5,R4 | R_0805_2012Metric_Pad1.15x1.40mm_HandSolder | 4 | 330Î©
24 | R6,R3 | R_0805_2012Metric_Pad1.15x1.40mm_HandSolder | 2 | 5K1
25 | R1 | R_0805_2012Metric_Pad1.15x1.40mm_HandSolder | 1 | 1KÎ©
26 | PWR1 | LED_0805_2012Metric_Pad1.15x1.40mm_HandSolder | 1 | PWR
27 | J4 | PinHeader_2x03_P2.54mm_Vertical | 1 | Conn_02x03_Odd_Even
28 | J3 | PinHeader_1x08_P2.54mm_Vertical | 1 | 3x4 Keypad
29 | J1 | PinSocket_1x16_P2.54mm_Vertical | 1 | 16x2 LCD Display
30 | H4,H3,H2,H1 | MountingHole_2.2mm_M2_Pad_Via | 4 | MountingHole
31 | D13 | LED_0805_2012Metric_Pad1.15x1.40mm_HandSolder | 1 | D13
32 | D4,D3 | D_SOD-123F | 2 | D_Schottky
33 | C52,C51,C50,C37,C16,C15,C14,C12,C6,C5,C4,C3,C2,C1 | C_0805_2012Metric_Pad1.15x1.40mm_HandSolder | 14 | 100nF
34 | C18,C17,C11,C10,C9 | C_0805_2012Metric_Pad1.15x1.40mm_HandSolder | 5 | 22pF
35 | C8,C7 | C_Elec_4x5.4 | 2 | 10ÂµF
36 | TP1 | logoinv | 1 | TestPoint

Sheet: Sheet1
Id | Designator | Part | Package | Quantity | Designation
1 | RV1 | 10K Pot | Potentiometer_Runtron_RM-065_Vertical | 1 | Cntrst Cntrl
2 | U5 | 74HC08-Quad NAND Gate | SOIC-14_3.9x8.7mm_P1.27mm | 1 | 74HC08
3 | J5 | 2x8 IDC Connect P=2.54mm | IDC-Header_2x08_P2.54mm_Vertical | 1 | Locker4-6
4 | J6 | 2x8 IDC Connect P=2.54mm | IDC-Header_2x08_P2.54mm_Vertical | 1 | Locker1-3
5 | J12 | 1x6 Terminal Block P=5.0mm | TerminalBlock_RND_205-00060_1x06_P5.00mm_45Degree | 1 | Power
6 | J10 | 1x4 Terminal Block P=5.0mm | TerminalBlock_Altech_AK300-4_P5.00mm | 1 | Speaker
7 | J2 | 1x4 Terminal Block P=5.0mm | TerminalBlock_Altech_AK300-4_P5.00mm | 1 | RAW in
8 | P1 | SMD USB C Port | USB_C_SMD | 1 | USB_C_Plug
9 | DB3 | PAM8403 Audio Amplifier Module | PAM8403_DB | 1 | PAM8403_DB
10 | SD1 | SPI Micro-SD Card Module | Micro_SD_Module | 1 | microSD_Adapter
11 | DB2 | 12V Voltage Regulator Board | Votlage_Regulator_DB (Custom) | 1 | +12V_DB
12 | DB1 | 5V Voltage Regulator Board | Votlage_Regulator_DB (Custom) | 1 | +5V_DB
13 | U4 | AtMega2560 | TQFP-100_14x14mm_P0.5mm | 1 | ATmega2560-16AU
14 | R14,R13,R12,R11 | 0R 0805 Resistor | R_0805_2012Metric_Pad1.15x1.40mm_HandSolder | 4 | 0R
15 | U2 | ams1117-3.3V | SOT-223 | 1 | ams1117-3.3V
16 | Y2 | 12MHz 3225 SMD Crystal | Crystal_SMD_3225-4Pin_3.2x2.5mm_HandSoldering | 1 | 12MHz
17 | Y1 | 16MHz 3225 SMD Crystal | Crystal_SMD_3225-4Pin_3.2x2.5mm_HandSoldering | 1 | 16MHz
18 | U3 | CH340G | SOIC-16_3.9x9.9mm_P1.27mm | 1 | CH340G
19 | TX1 | TX 0805 LED | LED_0805_2012Metric_Pad1.15x1.40mm_HandSolder | 1 | TX
20 | SW1 | SMD SPST Button | SW_SPST_TL3342 | 1 | RST
21 | RX1 | RX 0805 LED | LED_0805_2012Metric_Pad1.15x1.40mm_HandSolder | 1 | RX
22 | R37,R2 | 1M 0805 Resistor | R_0805_2012Metric_Pad1.15x1.40mm_HandSolder | 2 | 1M
23 | R10,R9,R5,R4 | 330R 0805 Resistor | R_0805_2012Metric_Pad1.15x1.40mm_HandSolder | 4 | 330R
24 | R6,R3 | 5K1 0805 R | R_0805_2012Metric_Pad1.15x1.40mm_HandSolder | 2 | 5K1
25 | R1 | 1K 0805 Resistor | R_0805_2012Metric_Pad1.15x1.40mm_HandSolder | 1 | 1K
26 | PWR1 | PWR 0805 LED | LED_0805_2012Metric_Pad1.15x1.40mm_HandSolder | 1 | PWR
27 | J4 | 2x3 2.54mm Header - ICSP | PinHeader_2x03_P2.54mm_Vertical | 1 | Conn_02x03_Odd_Even
28 | J3 | 1x8 2.54mm Header - Keypad | PinHeader_1x08_P2.54mm_Vertical | 1 | 3x4 Keypad
29 | J1 | 1x16 2.54mm Header - LCD | PinSocket_1x16_P2.54mm_Vertical | 1 | 16x2 LCD Display
30 | H4,H3,H2,H1 | Mounting Hole | MountingHole_2.2mm_M2_Pad_Via | 4 | MountingHole
31 | D13 | D13 0805 LED | LED_0805_2012Metric_Pad1.15x1.40mm_HandSolder | 1 | D13
32 | D4,D3 | 1N4004 Flyback Diode | D_SOD-123F | 2 | D_Schottky
33 | C52,C51,C50,C37,C16,C15,C14,C12,C6,C5,C4,C3,C2,C1 | 100nF 0805 Capacitor | C_0805_2012Metric_Pad1.15x1.40mm_HandSolder | 14 | 100nF
34 | C18,C17,C11,C10,C9 | 22pF 0805 Capacitor | C_0805_2012Metric_Pad1.15x1.40mm_HandSolder | 5 | 22pF
35 | C8,C7 | 10µF 4x5.4mm Capacitor | C_Elec_4x5.4 | 2 | 10µF

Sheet: MB_BOM
Id;"Designator";"Package";"Quantity";"Designation";"Supplier and ref";
1;"RV1";"Potentiometer_Runtron_RM-065_Vertical";1;"Cntrst Cntrl";;;
2;"U5";"SOIC-14_3.9x8.7mm_P1.27mm";1;"74HC08";;;
3;"J5";"IDC-Header_2x08_P2.54mm_Vertical";1;"Locker4-6";;;
4;"J6";"IDC-Header_2x08_P2.54mm_Vertical";1;"Locker1-3";;;
5;"J12";"TerminalBlock_RND_205-00060_1x06_P5.00mm_45Degree";1;" ";;;
6;"J10";"TerminalBlock_Altech_AK300-4_P5.00mm";1;"Speaker";;;
7;"J2";"TerminalBlock_Altech_AK300-4_P5.00mm";1;"RAW in";;;
8;"P1";"USB_C_SMD";1;"USB_C_Plug";;;
9;"DB3";"PAM8403_DB";1;"PAM8403_DB";;;
10;"SD1";"Micro_SD_Module";1;"microSD_Adapter";;;
11;"DB2";"LM2576_DB";1;"+12V_DB";;;
12;"DB1";"LM2576_DB";1;"+5V_DB";;;
13;"U4";"TQFP-100_14x14mm_P0.5mm";1;"ATmega2560-16AU";;;
14;"R14 | R13 | R12 | R11";"R_0805_2012Metric_Pad1.15x1.40mm_HandSolder";4;"0Î©";;;
15;"U2";"SOT-223";1;"ams1117-3.3V";;;
16;"Y2";"Crystal_SMD_3225-4Pin_3.2x2.5mm_HandSoldering";1;"12MHz";;;
17;"Y1";"Crystal_SMD_3225-4Pin_3.2x2.5mm_HandSoldering";1;"16MHz";;;
18;"U3";"SOIC-16_3.9x9.9mm_P1.27mm";1;"CH340G";;;
19;"TX1";"LED_0805_2012Metric_Pad1.15x1.40mm_HandSolder";1;"TX";;;
20;"SW1";"SW_SPST_TL3342";1;"RST";;;
21;"RX1";"LED_0805_2012Metric_Pad1.15x1.40mm_HandSolder";1;"RX";;;
22;"R37 | R2";"R_0805_2012Metric_Pad1.15x1.40mm_HandSolder";2;"1MÎ©";;;
23;"R10 | R9 | R5 | R4";"R_0805_2012Metric_Pad1.15x1.40mm_HandSolder";4;"330Î©";;;
24;"R6 | R3";"R_0805_2012Metric_Pad1.15x1.40mm_HandSolder";2;"5K1";;;
25;"R1";"R_0805_2012Metric_Pad1.15x1.40mm_HandSolder";1;"1KÎ©";;;
26;"PWR1";"LED_0805_2012Metric_Pad1.15x1.40mm_HandSolder";1;"PWR";;;
27;"J4";"PinHeader_2x03_P2.54mm_Vertical";1;"Conn_02x03_Odd_Even";;;
28;"J3";"PinHeader_1x08_P2.54mm_Vertical";1;"3x4 Keypad";;;
29;"J1";"PinSocket_1x16_P2.54mm_Vertical";1;"16x2 LCD Display";;;
30;"H4 | H3 | H2 | H1";"MountingHole_2.2mm_M2_Pad_Via";4;"MountingHole";;;
31;"D13";"LED_0805_2012Metric_Pad1.15x1.40mm_HandSolder";1;"D13";;;
32;"D4 | D3";"D_SOD-123F";2;"D_Schottky";;;
33;"C52 | C51 | C50 | C37 | C16 | C15 | C14 | C12 | C6 | C5 | C4 | C3 | C2 | C1";"C_0805_2012Metric_Pad1.15x1.40mm_HandSolder";14;"100nF";;;
34;"C18 | C17 | C11 | C10 | C9";"C_0805_2012Metric_Pad1.15x1.40mm_HandSolder";5;"22pF";;;
35;"C8 | C7";"C_Elec_4x5.4";2;"10ÂµF";;;
36;"TP1";"logoinv";1;"TestPoint";;;

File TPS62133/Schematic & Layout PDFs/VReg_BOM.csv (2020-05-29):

Id | Designator | Package | Quantity | Designation | Supplier and ref
1 | DB1 | DB_43x21 | 1 | DB_42x21
2 | C4 | C_1206_3216Metric_Pad1.42x1.75mm_HandSolder | 1 | 22µF
3 | L1 | L_6.3x6.3_H3 | 1 | 2.2µH
4 | U1 | VQFN-16-1EP_3x3mm_P0.5mm_EP1.68x1.68mm_ThermalVias | 1 | TPS62133
5 | R1 | R_0805_2012Metric_Pad1.15x1.40mm_HandSolder | 1 | 100K
6 | C3 | C_1206_3216Metric_Pad1.42x1.75mm_HandSolder | 1 | 10µF
7 | C2 | C_0805_2012Metric_Pad1.15x1.40mm_HandSolder | 1 | 620pF
8 | C1 | C_0805_2012Metric_Pad1.15x1.40mm_HandSolder | 1 | 100nF

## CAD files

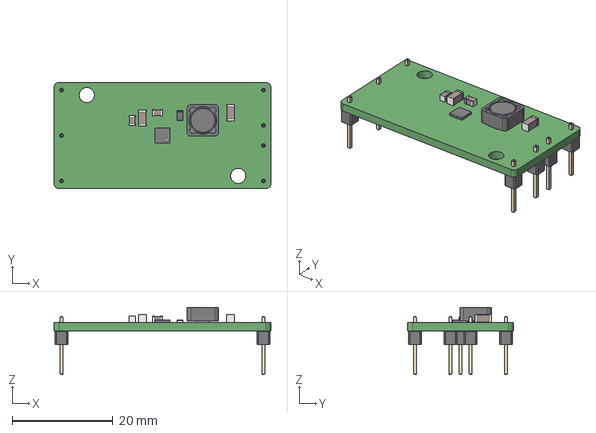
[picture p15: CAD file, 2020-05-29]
TPS62133/Schematic & Layout PDFs/VReg_3D.step
43.0 x 21.0 x 13.3 mm

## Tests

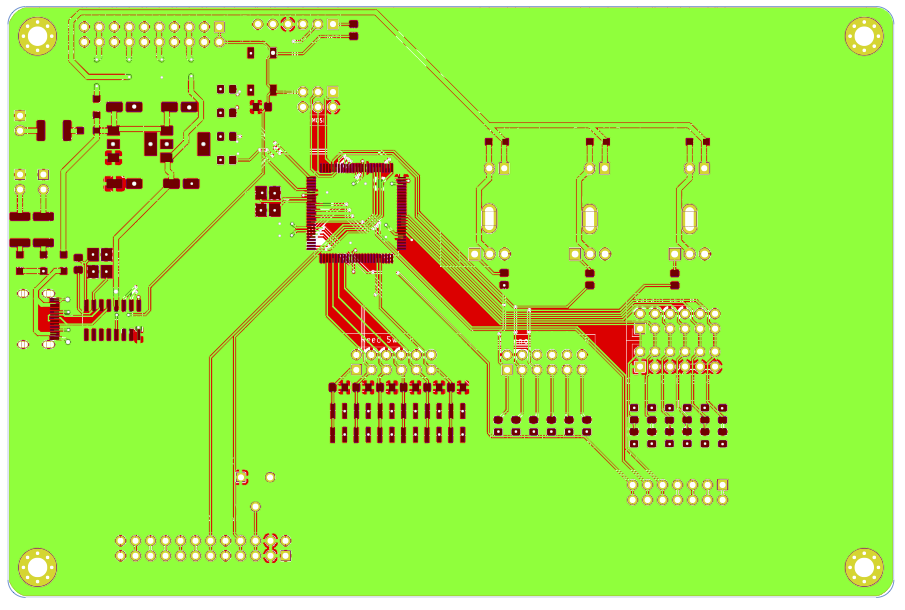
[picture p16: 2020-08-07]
SlugCharge_Testbench_V1.0/Layout.png

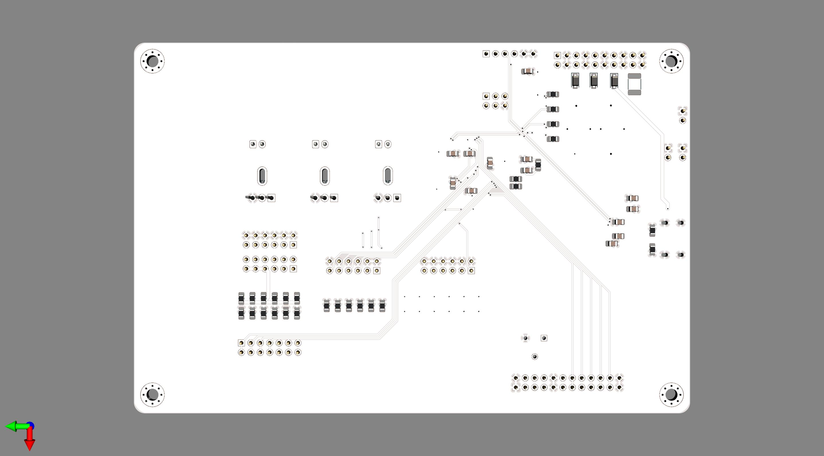
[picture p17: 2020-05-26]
SlugCharge_Testbench_V1.0/3-D BACK.jpg

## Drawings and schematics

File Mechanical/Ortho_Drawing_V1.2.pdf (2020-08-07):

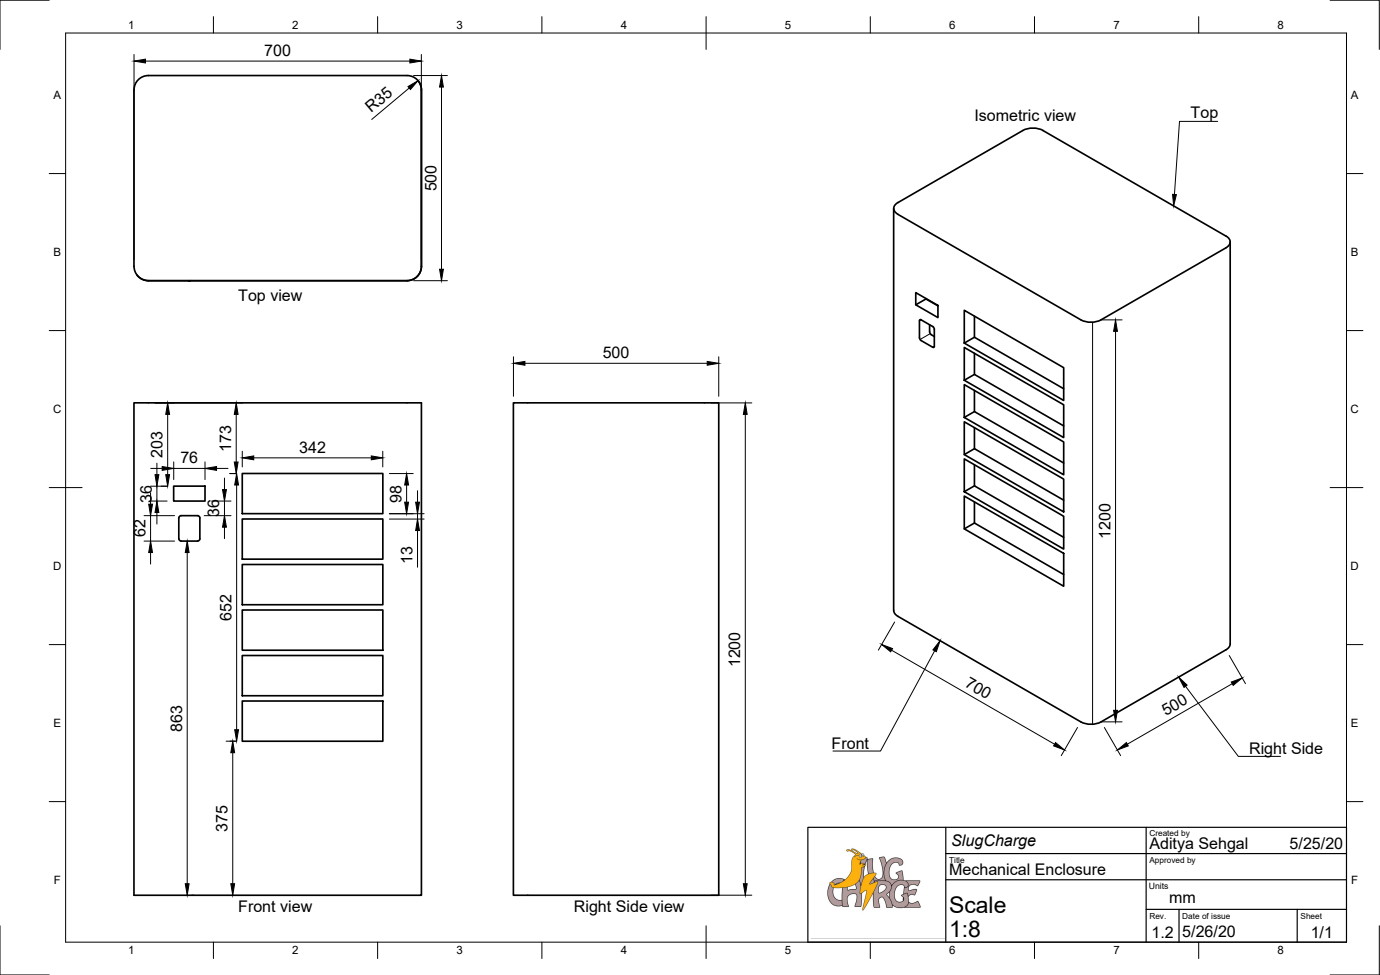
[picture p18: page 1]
Created by; SlugCharge; Aditya Sehgal; Front view; Top view; Isometric view; Front; Right Side; Top

Title Mechanical Enclosure | Approved by

Scale 1:8 | Units mm

Right Side view

Rev. 1.2 | Date of issue 5/26/20 | Sheet 1/1

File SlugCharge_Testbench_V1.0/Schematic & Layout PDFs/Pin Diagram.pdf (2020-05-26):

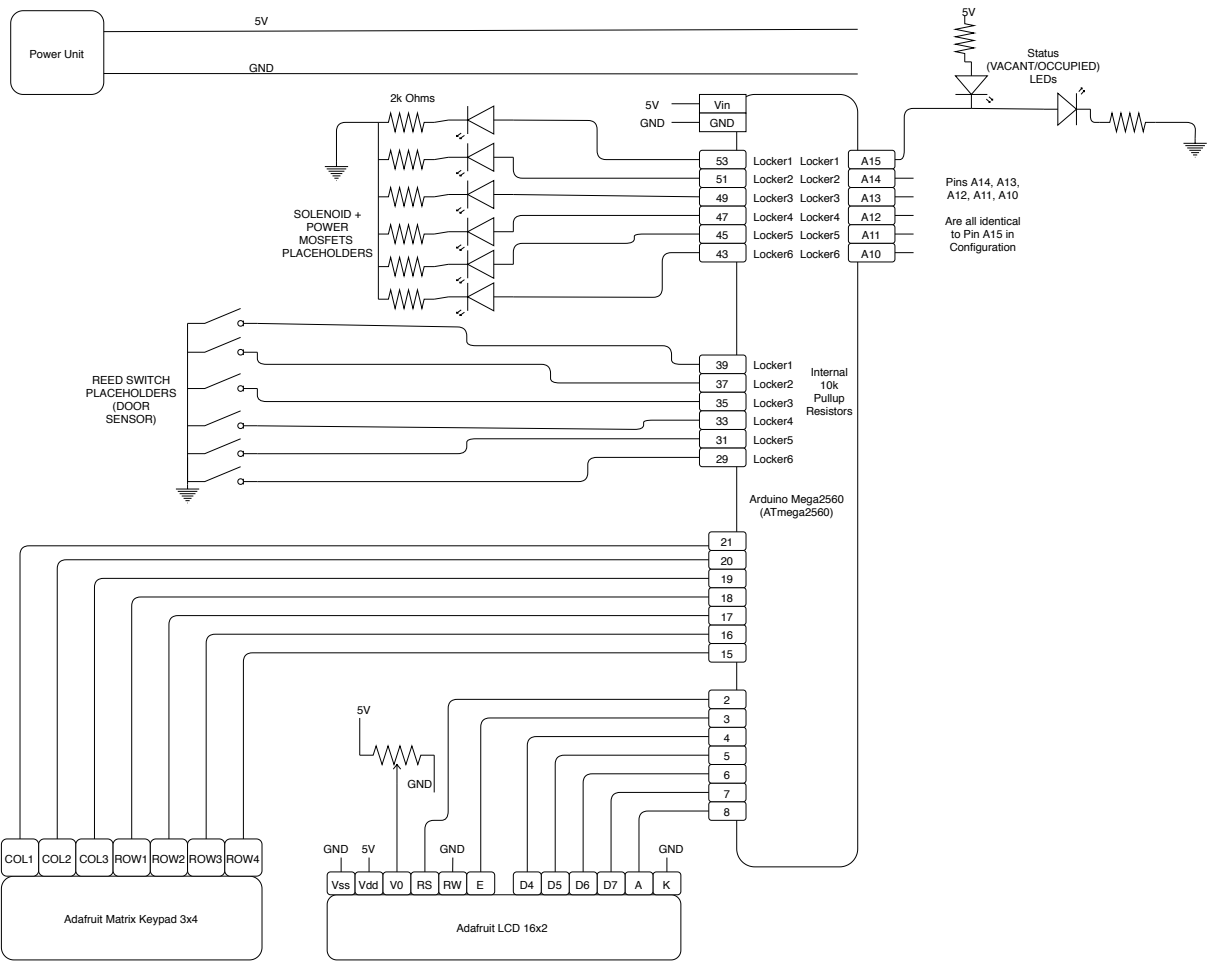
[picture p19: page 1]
Power Unit; Arduino Mega2560 (ATmega2560); Vin; GND; Adafruit LCD 16x2; Vss Vdd V0 RS RW; GND 5V; COL1 COL2 COL3 ROW1 ROW2 ROW3 ROW4; SOLENOID + POWER MOSFETS PLACEHOLDERS; Internal 10k Pullup Resistors; REED SWITCH PLACEHOLDERS (DOOR SENSOR); Locker1; Locker2; Locker3; Locker4; Locker5; Locker6; 2k Ohms; Pins A14, A13, A12, A11, A10; Status (VACANT/OCCUPIED) LEDs

Are all identical
to Pin A15 in
Configuration

Adafruit Matrix Keypad 3x4

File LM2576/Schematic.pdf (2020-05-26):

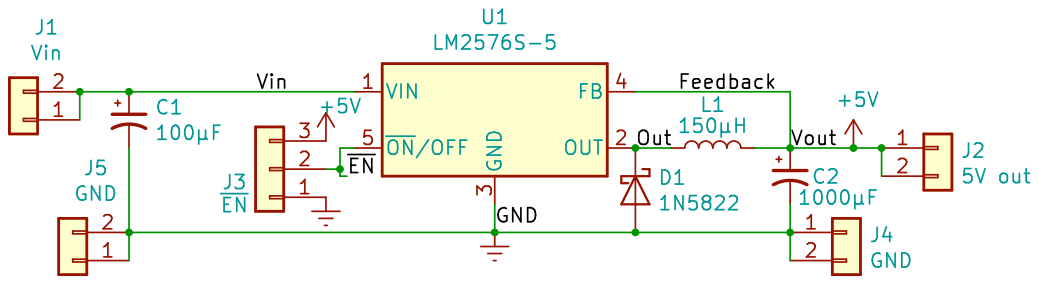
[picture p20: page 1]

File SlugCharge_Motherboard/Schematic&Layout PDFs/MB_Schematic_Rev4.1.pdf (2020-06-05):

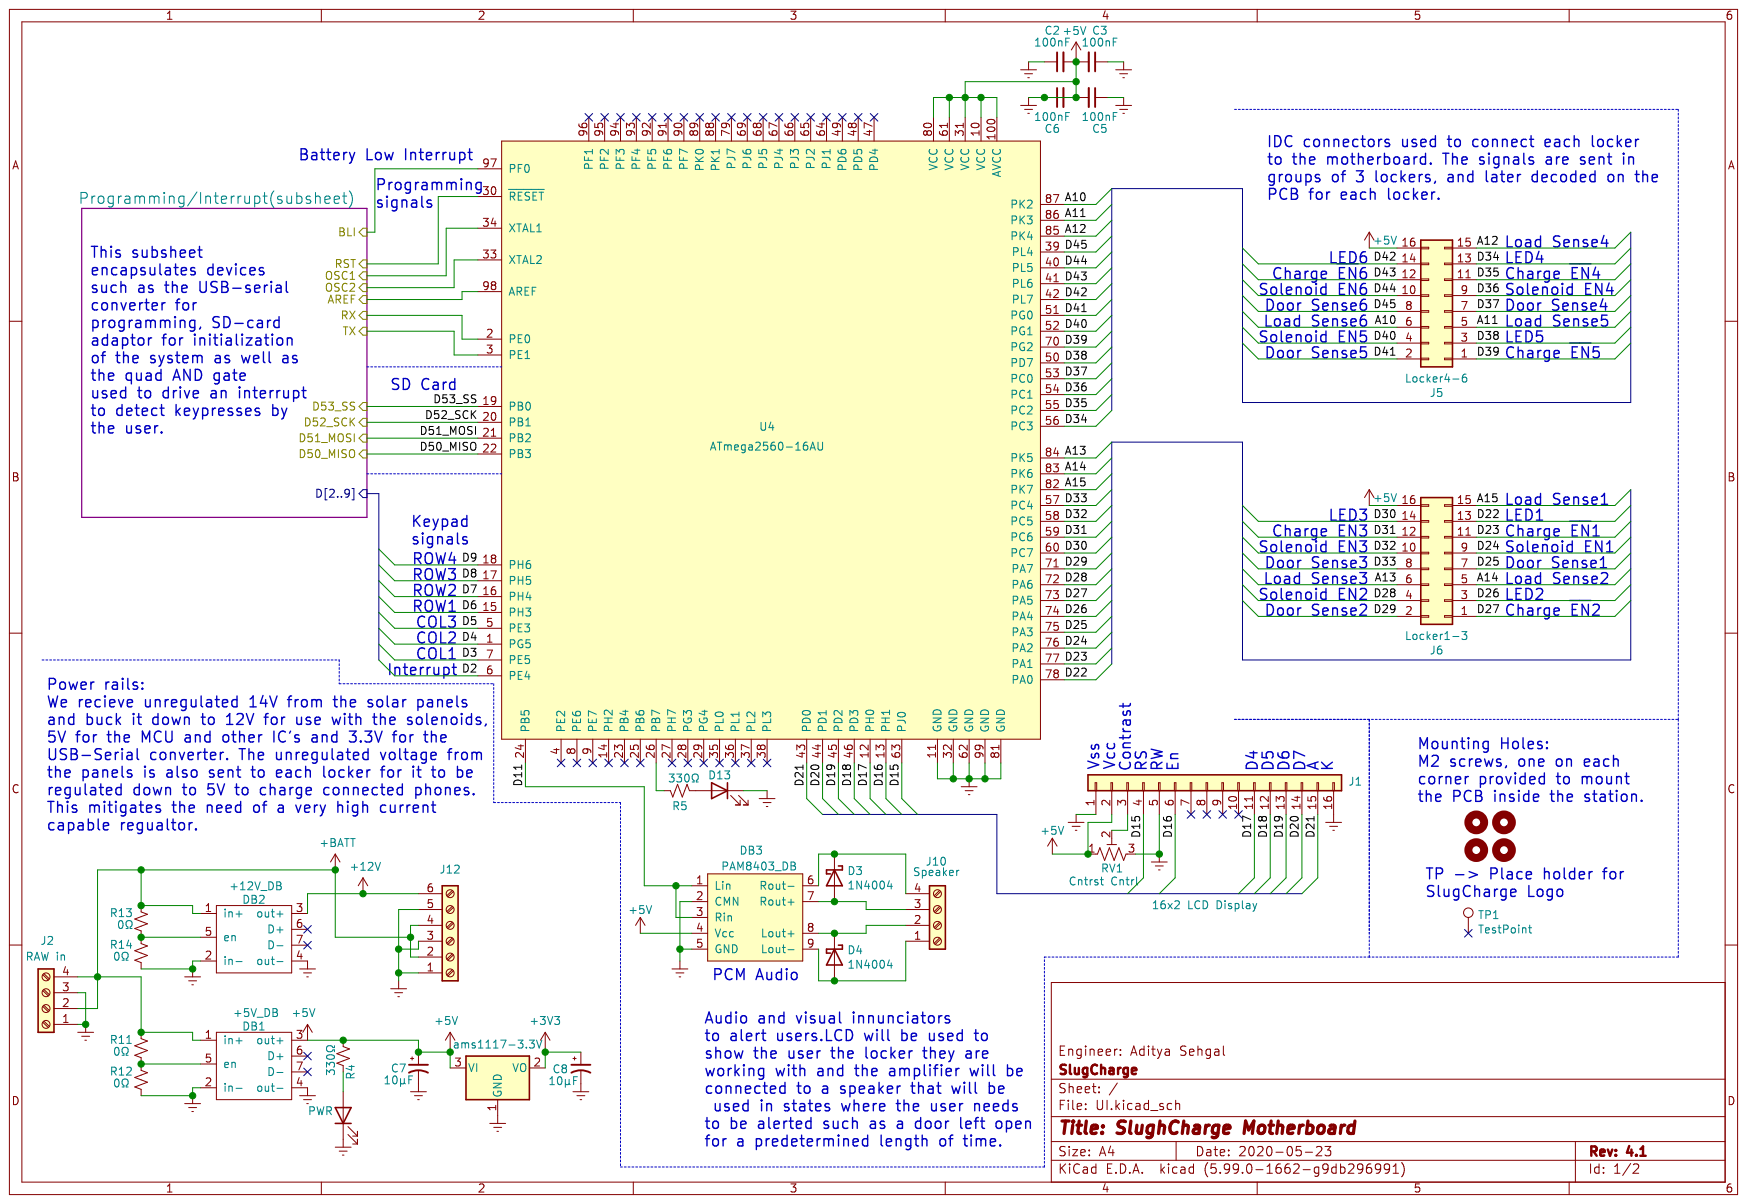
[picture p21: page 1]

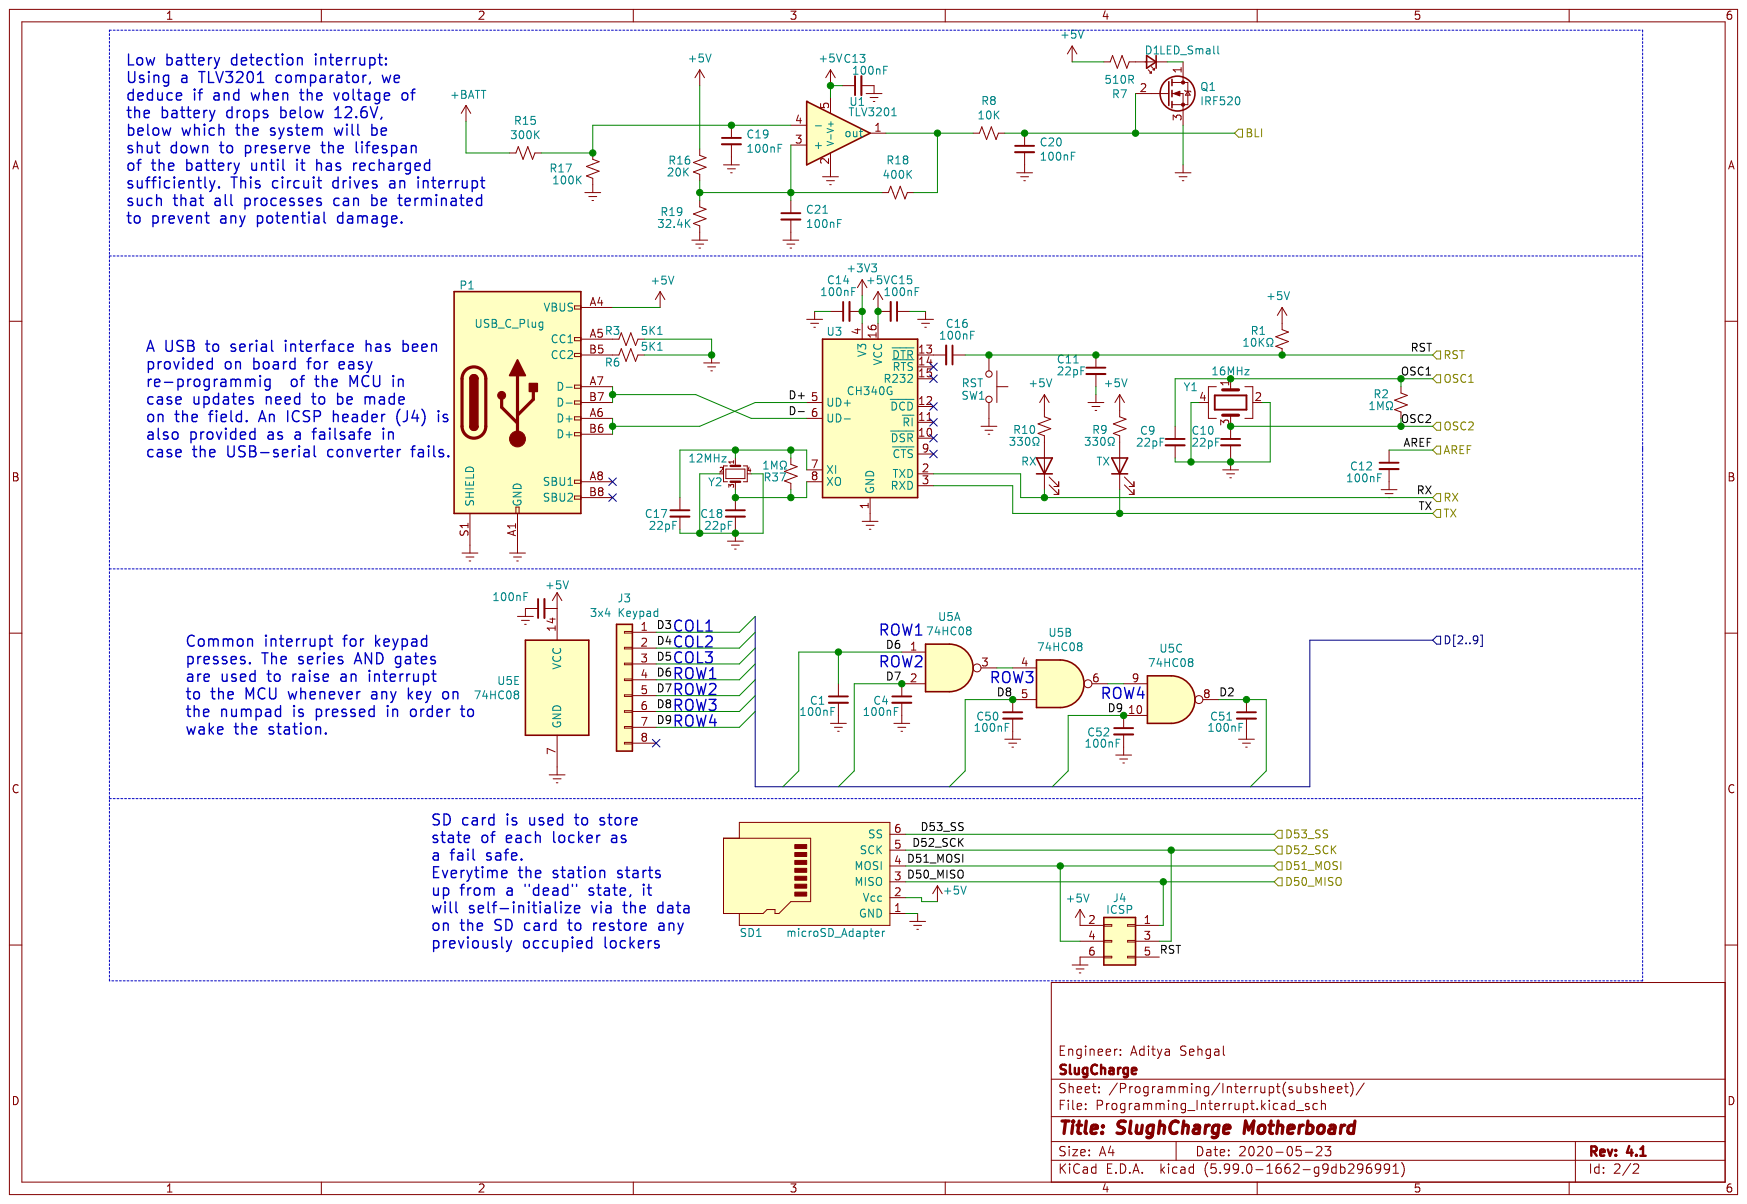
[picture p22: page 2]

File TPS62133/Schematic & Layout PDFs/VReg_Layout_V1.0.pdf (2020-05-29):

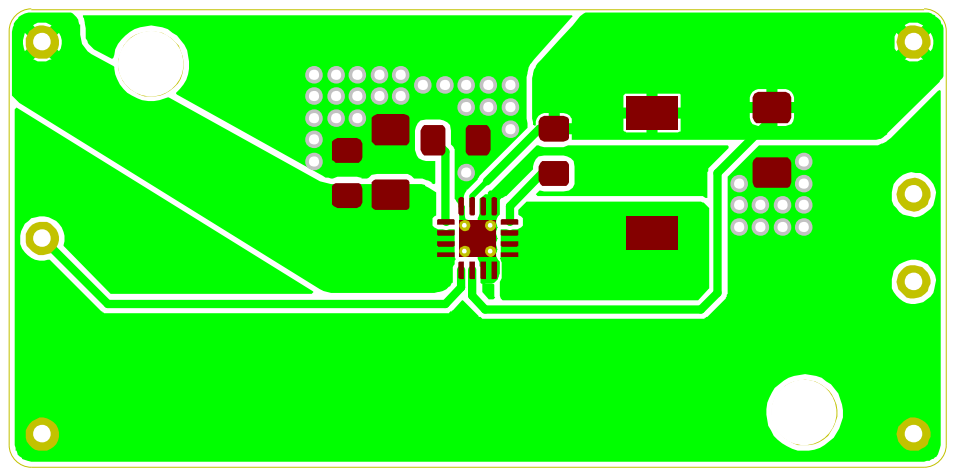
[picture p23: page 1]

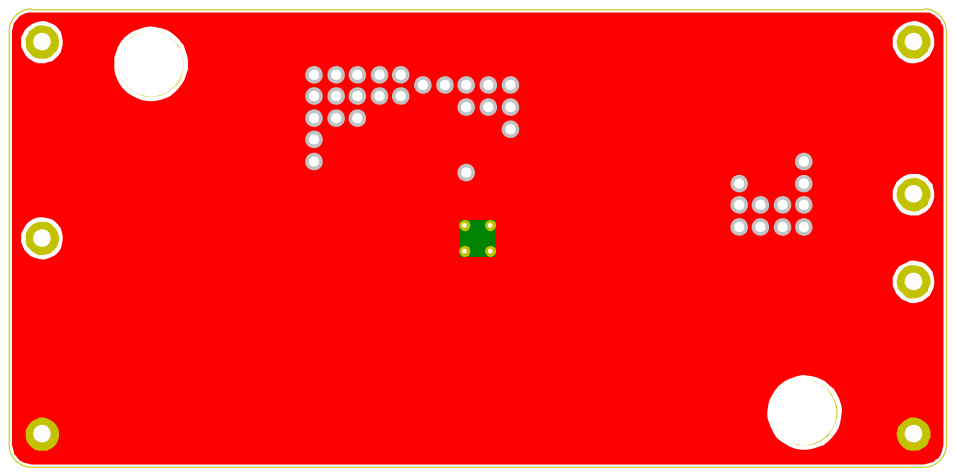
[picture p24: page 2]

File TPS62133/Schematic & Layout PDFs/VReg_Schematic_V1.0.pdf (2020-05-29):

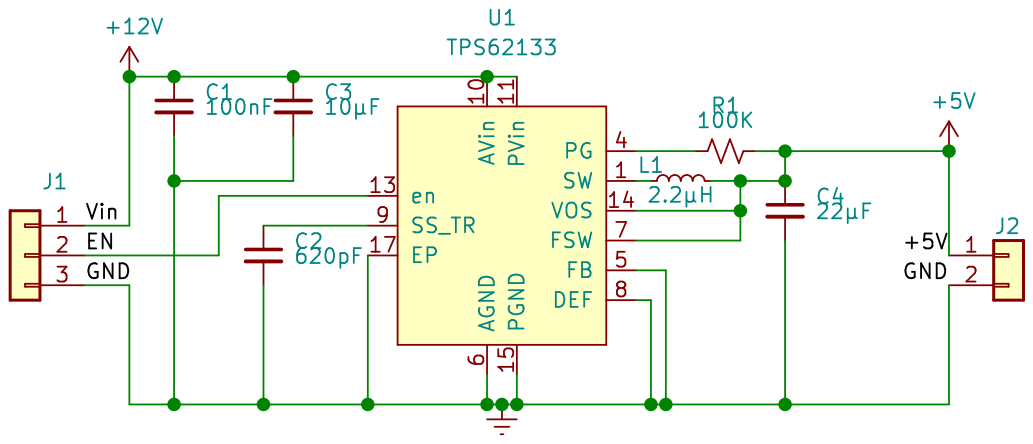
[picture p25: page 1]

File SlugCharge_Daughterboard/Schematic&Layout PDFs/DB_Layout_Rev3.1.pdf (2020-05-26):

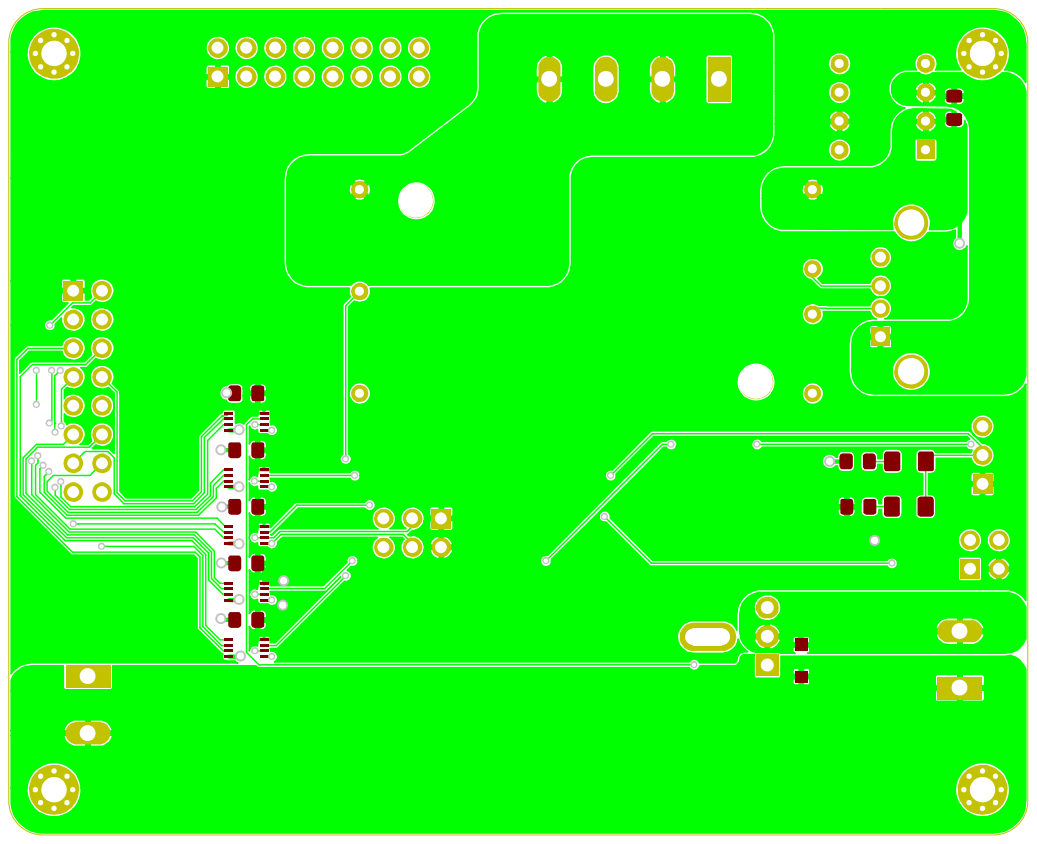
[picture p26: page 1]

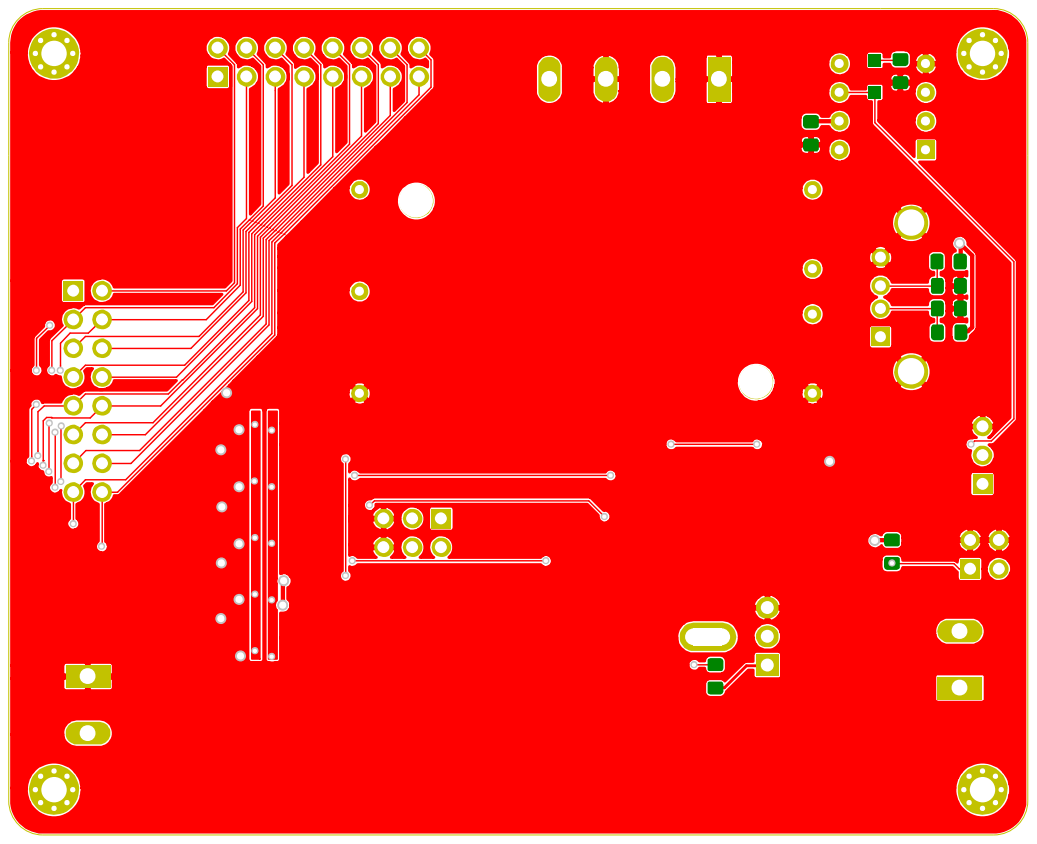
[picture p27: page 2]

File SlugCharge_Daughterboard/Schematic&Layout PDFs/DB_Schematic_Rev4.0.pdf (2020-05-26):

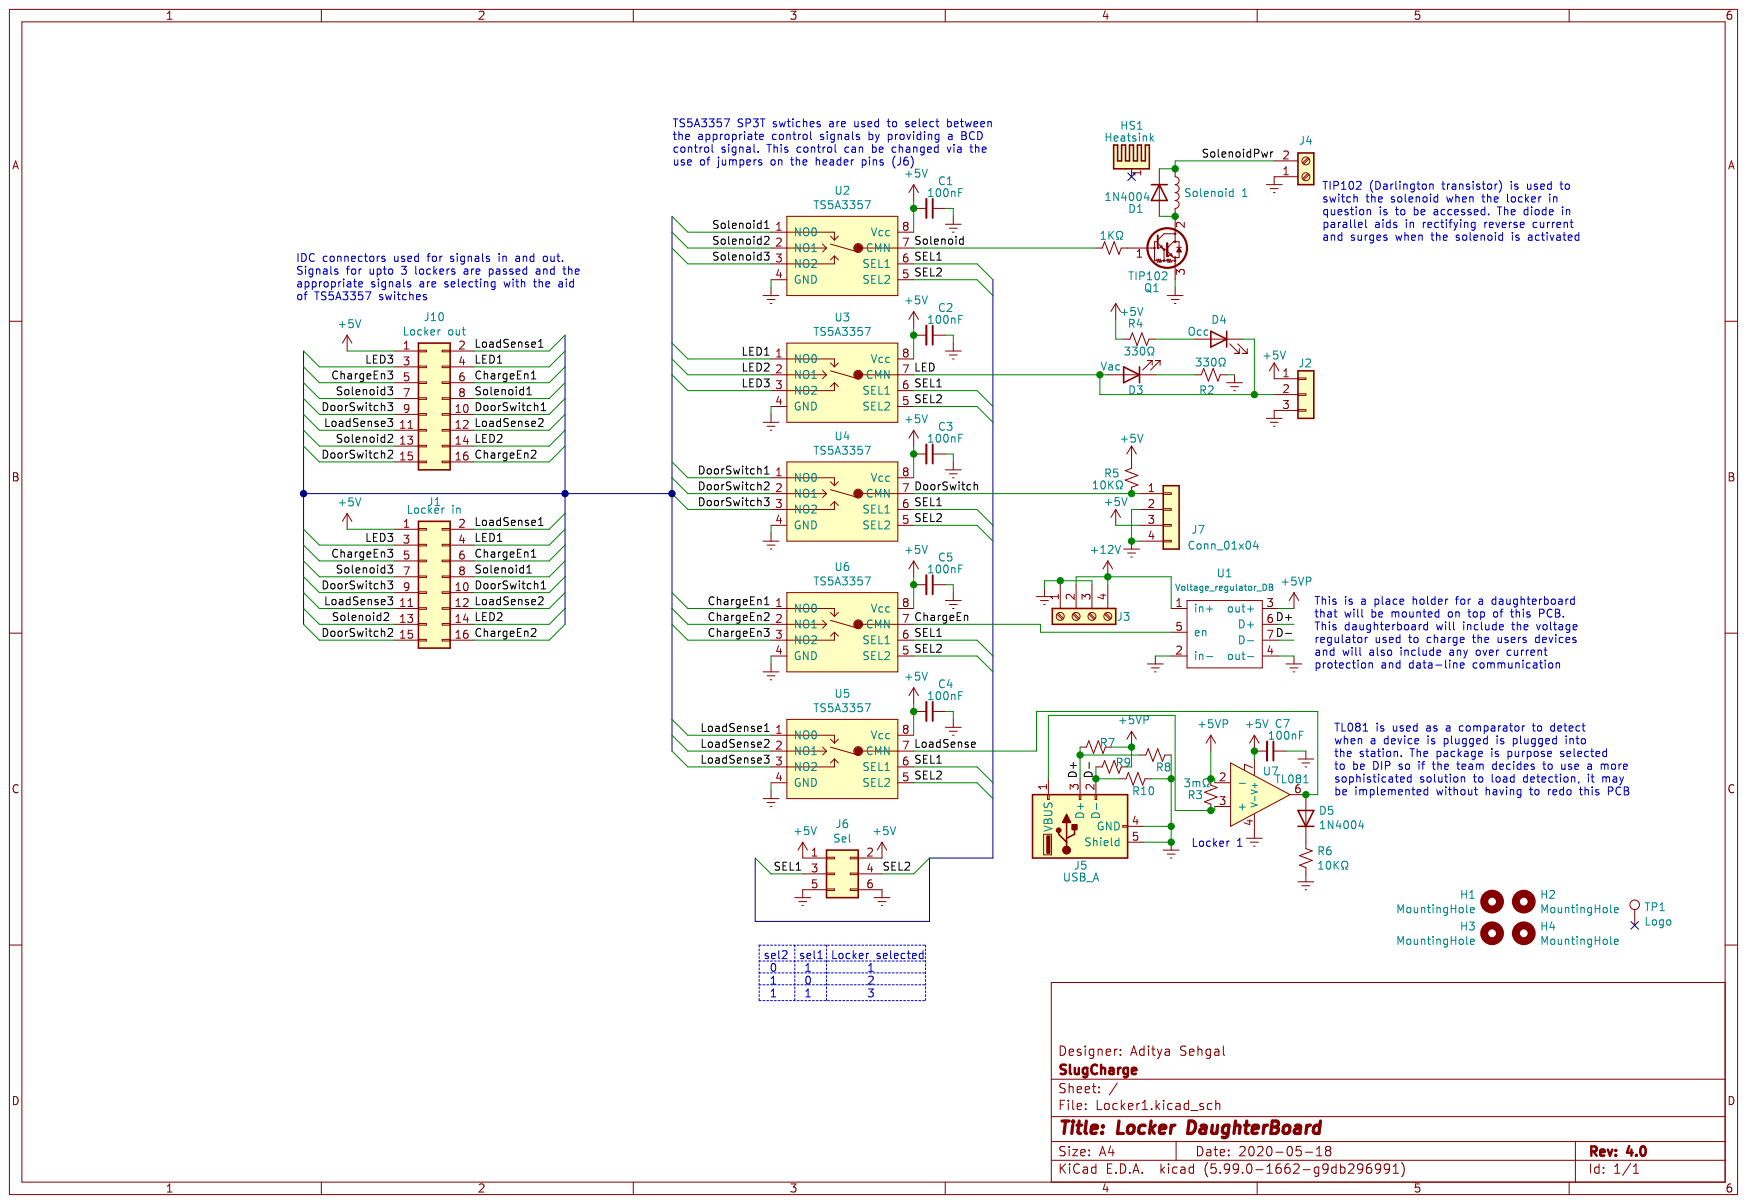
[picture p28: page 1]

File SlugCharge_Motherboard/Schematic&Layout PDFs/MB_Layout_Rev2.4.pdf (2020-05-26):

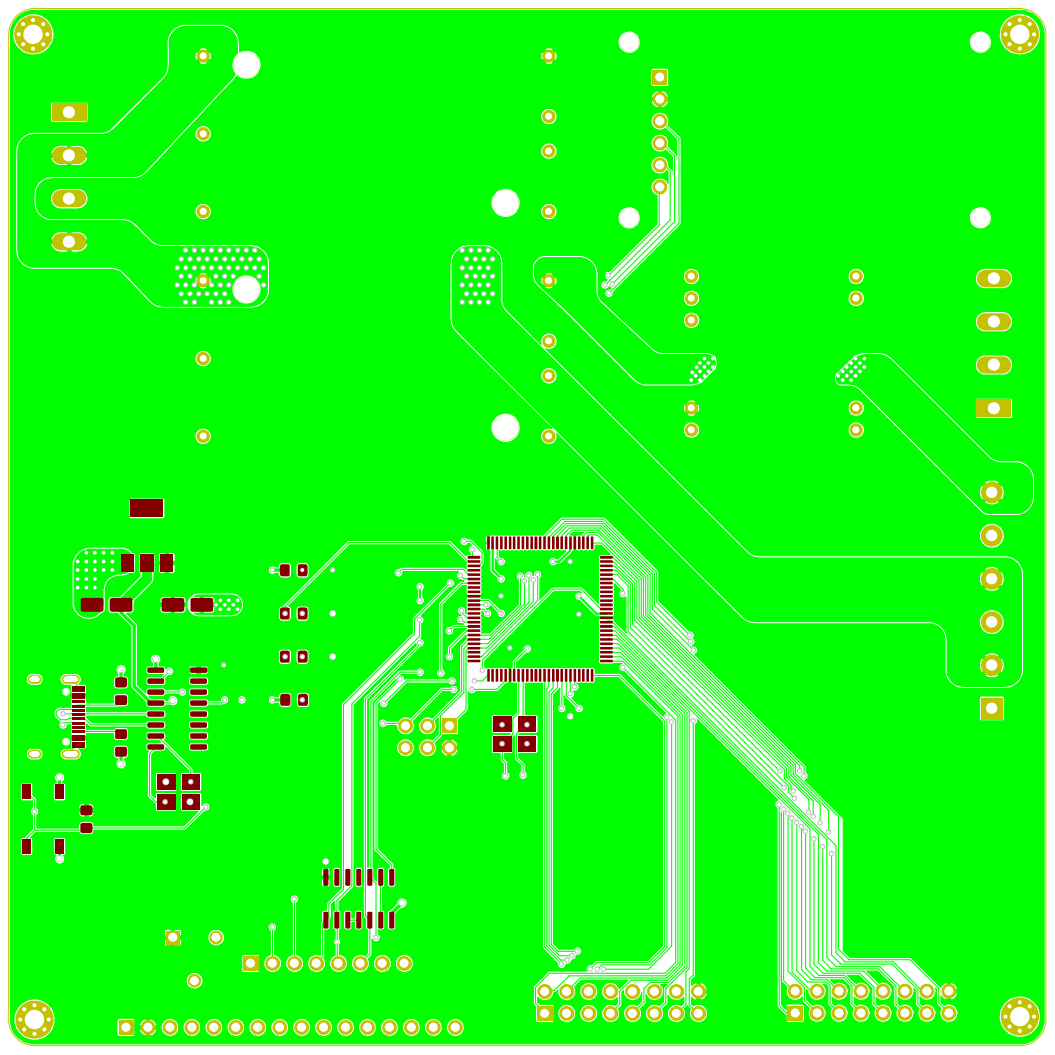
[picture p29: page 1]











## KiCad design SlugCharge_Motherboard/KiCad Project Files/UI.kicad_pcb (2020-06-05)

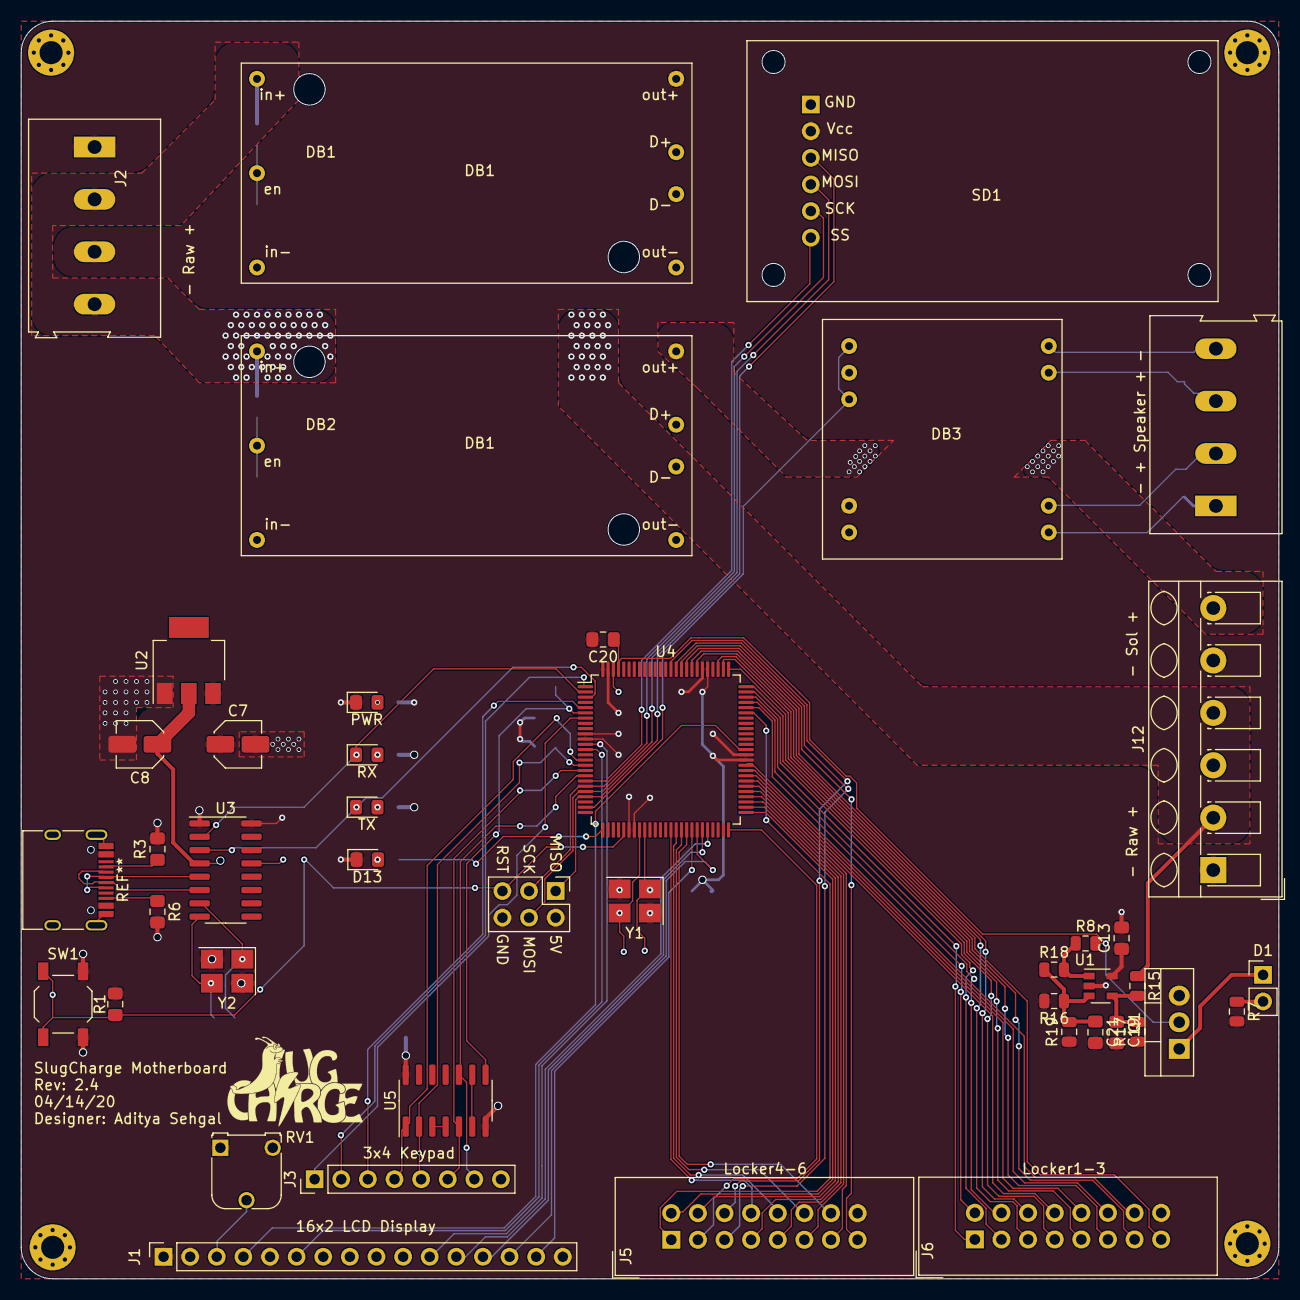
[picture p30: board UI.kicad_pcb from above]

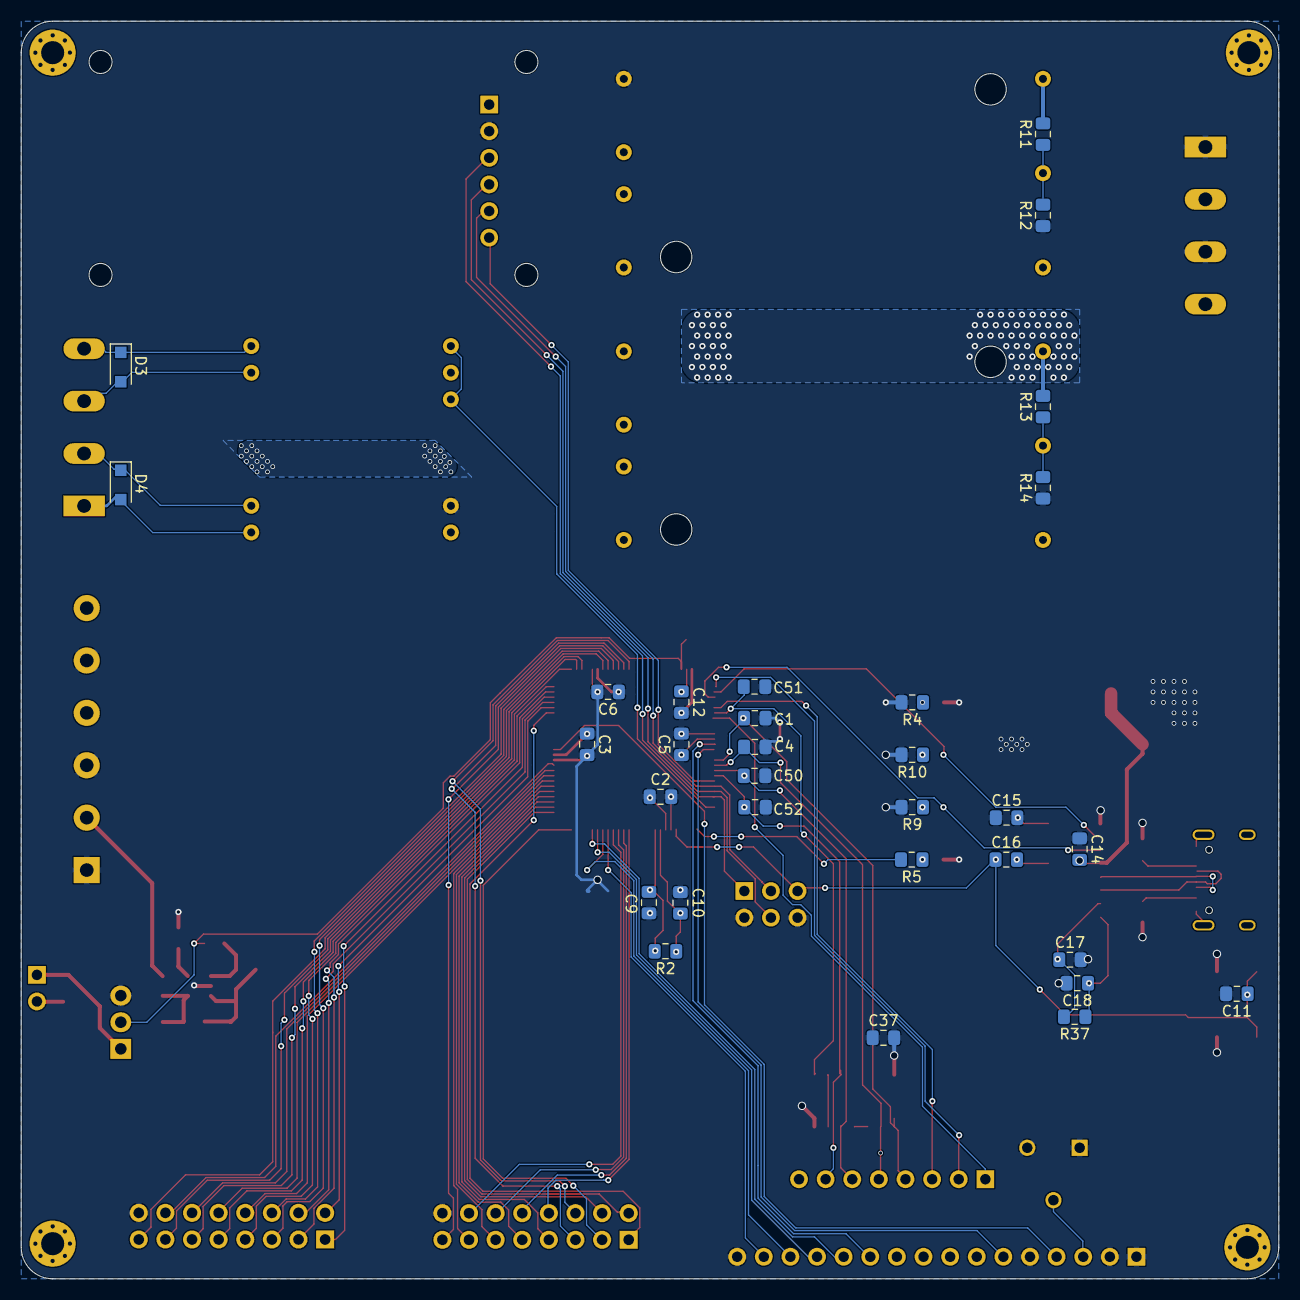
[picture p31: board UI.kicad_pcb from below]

Board: 2 copper layers, 120.0 x 120.0 mm, 80 parts (31 on the bottom side), 89 nets.

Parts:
C1, C2, C3, C4, C5, C6, C12, C13, C14, C15, C16, C19, C20, C21, C37, C50, C51, C52: 100nF; C_0805_2012Metric_Pad1.15x1.40mm_HandSolder
C7, C8: 10µF; C_Elec_4x5.4
C9, C10, C11, C17, C18: 22pF; C_0805_2012Metric_Pad1.15x1.40mm_HandSolder
D1: LED_Small; PinHeader_1x02_P2.54mm_Vertical
D3, D4: 1N4004; D_SOD-123F
D13: D13; LED_0805_2012Metric_Pad1.15x1.40mm_HandSolder
DB1: +5V_DB; LM2576_DB
DB2: +12V_DB; LM2576_DB
DB3: PAM8403_DB
H1, H2, H3, H4: MountingHole; MountingHole_2.2mm_M2_Pad_Via
J1: 16x2 LCD Display; PinSocket_1x16_P2.54mm_Vertical
J2: RAW in; TerminalBlock_Altech_AK300-4_P5.00mm
J3: 3x4 Keypad; PinHeader_1x08_P2.54mm_Vertical
J4: ICSP; PinHeader_2x03_P2.54mm_Vertical
J5: Locker4-6; IDC-Header_2x08_P2.54mm_Vertical
J6: Locker1-3; IDC-Header_2x08_P2.54mm_Vertical
J10: Speaker; TerminalBlock_Altech_AK300-4_P5.00mm
J12: Power; TerminalBlock_RND_205-00060_1x06_P5.00mm_45Degree
P1: USB_C_Plug; USB_C_SMD
PWR1: PWR; LED_0805_2012Metric_Pad1.15x1.40mm_HandSolder
Q1: IRF520; TO-220-3_Vertical
R1: 10KΩ; R_0805_2012Metric_Pad1.15x1.40mm_HandSolder
R2, R37: 1MΩ; R_0805_2012Metric_Pad1.15x1.40mm_HandSolder
R3, R6: 5K1; R_0805_2012Metric_Pad1.15x1.40mm_HandSolder
R4, R5, R9, R10: 330Ω; R_0805_2012Metric_Pad1.15x1.40mm_HandSolder
R7: 510R; R_0805_2012Metric
R8: 10K; R_0805_2012Metric
R11, R12, R13, R14: 0Ω; R_0805_2012Metric_Pad1.15x1.40mm_HandSolder
R15: 300K; R_0805_2012Metric
R16: 20K; R_0805_2012Metric
R17: 100K; R_0805_2012Metric
R18: 400K; R_0805_2012Metric
R19: 32.4K; R_0805_2012Metric
RV1: Cntrst Cntrl; Potentiometer_Runtron_RM-065_Vertical
RX1: RX; LED_0805_2012Metric_Pad1.15x1.40mm_HandSolder
SD1: microSD_Adapter; Micro_SD_Module
SW1: RST; SW_SPST_TL3342
TP1: TestPoint; logoinv
TX1: TX; LED_0805_2012Metric_Pad1.15x1.40mm_HandSolder
U1: TLV3201; SOT-23-5
U2: ams1117-3.3V; SOT-223
U3: CH340G; SOIC-16_3.9x9.9mm_P1.27mm
U4: ATmega2560-16AU; TQFP-100_14x14mm_P0.5mm
U5: 74HC08; SOIC-14_3.9x8.7mm_P1.27mm
Y1: 16MHz; Crystal_SMD_3225-4Pin_3.2x2.5mm_HandSoldering
Y2: 12MHz; Crystal_SMD_3225-4Pin_3.2x2.5mm_HandSoldering

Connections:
+3V3: C8.1, C14.2, U2.2 (VO), U3.4 (V3)
+5V: C1.2, C2.1, C2.2, C3.1, C3.2, C4.2, C5.1, C5.2, C6.1, C6.2, C7.1, C7.2, C8.2, C9.2, C10.2, C11.2, C12.2, C13.1, C13.2, C14.1, C15.1, C15.2, C17.2, C18.2, C19.2, C20.2, C21.2, C37.1, C37.2, C50.2, C51.2, C52.2, D13.1 (K), DB1.3 (out+), DB3.4 (Vcc), J1.1, J1.2, J1.5, J1.16, J2.1, J2.3, J4.2, J4.6, J5.16, J6.16, J12.1, J12.3, J12.5, P1.A4 (VBUS), P1.A9 (VBUS), P1.B4 (VBUS), P1.B9 (VBUS), PWR1.1 (K), Q1.3 (S), R1.2, R3.2, R4.2, R6.2, R7.2, R9.2, R10.2, R12.1, R14.1, R16.2, R17.1, R19.1, RV1.1, RV1.3, SD1.2 (Vcc), SW1.2, U1.2 (V-), U1.5 (V+), U2.1 (GND), U2.3 (VI), U3.1 (GND), U3.16 (VCC), U4.10 (VCC), U4.11 (GND), U4.31 (VCC), U4.32 (GND), U4.61 (VCC), U4.62 (GND), U4.80 (VCC), U4.81 (GND), U4.99 (GND), U4.100 (AVCC), U5.7 (GND), U5.14 (VCC), Y1.2, Y1.4, Y2.2, Y2.4
+12V: DB2.3 (out+), J12.6
+BATT: J2.2, J2.4, J12.2, J12.4, R11.2, R13.2, R15.1
+VSW: DB1.1 (in+), DB2.1 (in+)
/A10: J5.6, U4.87 (PK2)
/A11: J5.5, U4.86 (PK3)
/A12: J5.15, U4.85 (PK4)
/A13: J6.6, U4.84 (PK5)
/A14: J6.5, U4.83 (PK6)
/A15: J6.15, U4.82 (PK7)
/AREF: C12.1, U4.98 (AREF)
/BLI: C20.1, Q1.2 (G), R8.2, U4.97 (PF0)
/D2: C51.1, U4.6 (PE4), U5.8
/D3: J3.1, U4.7 (PE5)
/D4: J3.2, U4.1 (PG5)
/D5: J3.3, U4.5 (PE3)
/D6: C1.1, J3.4, U4.15 (PH3), U5.1
/D7: C4.1, J3.5, U4.16 (PH4), U5.2
/D8: C50.1, J3.6, U4.17 (PH5), U5.5
/D9: C52.1, J3.7, U4.18 (PH6), U5.10
/D11: DB3.1 (Lin), DB3.3 (Rin), U4.24 (PB5)
/D15: J1.4, U4.63 (PJ0)
/D16: J1.6, U4.13 (PH1)
/D17: J1.11, U4.12 (PH0)
/D18: J1.12, U4.46 (PD3)
/D19: J1.13, U4.45 (PD2)
/D20: J1.14, U4.44 (PD1)
/D21: J1.15, U4.43 (PD0)
/D22: J6.13, U4.78 (PA0)
/D23: J6.11, U4.77 (PA1)
/D24: J6.9, U4.76 (PA2)
/D25: J6.7, U4.75 (PA3)
/D26: J6.3, U4.74 (PA4)
/D27: J6.1, U4.73 (PA5)
/D28: J6.4, U4.72 (PA6)
/D29: J6.2, U4.71 (PA7)
/D30: J6.14, U4.60 (PC7)
/D31: J6.12, U4.59 (PC6)
/D32: J6.10, U4.58 (PC5)
/D33: J6.8, U4.57 (PC4)
/D34: J5.13, U4.56 (PC3)
/D35: J5.11, U4.55 (PC2)
/D36: J5.9, U4.54 (PC1)
/D37: J5.7, U4.53 (PC0)
/D38: J5.3, U4.50 (PD7)
/D39: J5.1, U4.70 (PG2)
/D40: J5.4, U4.52 (PG1)
/D41: J5.2, U4.51 (PG0)
/D42: J5.14, U4.42 (PL7)
/D43: J5.12, U4.41 (PL6)
/D44: J5.10, U4.40 (PL5)
/D45: J5.8, U4.39 (PL4)
/D50_MISO: J4.1, SD1.3 (MISO), U4.22 (PB3)
/D51_MOSI: J4.4, SD1.4 (MOSI), U4.21 (PB2)
/D52_SCK: J4.3, SD1.5 (SCK), U4.20 (PB1)
/D53_SS: SD1.6 (SS), U4.19 (PB0)
/D+: P1.A6 (D+), P1.B6 (D+)
/D-: P1.A7 (D-), P1.B7 (D-)
/OSC1: C9.1, R2.2, U4.34 (XTAL1), Y1.1
/OSC2: C10.1, R2.1, U4.33 (XTAL2), Y1.3
/RST: C11.1, C16.1, J4.5, R1.1, SW1.1, U4.30 (~RESET)
/RX: RX1.1 (K), U3.2 (TXD), U4.2 (PE0)
/TX: TX1.1 (K), U3.3 (RXD), U4.3 (PE1)
GNDREF: DB1.2 (in-), DB1.4 (out-), DB2.2 (in-), DB2.4 (out-), DB3.2 (CMN), DB3.5 (GND), P1.A1 (GND), P1.A12 (GND), P1.B1 (GND), P1.B12 (GND), P1.S1 (SHIELD), SD1.1 (GND)
unnamed: C16.2, U3.13 (~DTR)
unnamed: C17.1, R37.2, U3.7 (XI), Y2.1
unnamed: C18.1, R37.1, U3.8 (XO), Y2.3
unnamed: C19.1, R15.2, R17.2, U1.4 (-)
unnamed: C21.1, R16.1, R18.1, R19.2, U1.3 (+)
unnamed: D1.1 (K), Q1.1 (D)
unnamed: D1.2 (A), R7.1
unnamed: D3.1 (K), DB3.6 (Rout-), J10.4
unnamed: D3.2 (A), DB3.7 (Rout+), J10.3
unnamed: D4.1 (K), DB3.8 (Lout+), J10.2
unnamed: D4.2 (A), DB3.9 (Lout-), J10.1
unnamed: D13.2 (A), R5.1
unnamed: DB1.5 (en), R11.1, R12.2
unnamed: DB2.5 (en), R13.1, R14.2
unnamed: J1.3, RV1.2
unnamed: P1.A5 (CC1), R3.1
unnamed: P1.B5 (CC2), R6.1
unnamed: PWR1.2 (A), R4.1
unnamed: R5.2, U4.26 (PB7)
unnamed: R9.1, TX1.2 (A)
unnamed: R10.1, RX1.2 (A)
unnamed: R8.1, R18.2, U1.1 (out)
unnamed: U5.3, U5.4
unnamed: U5.6, U5.9

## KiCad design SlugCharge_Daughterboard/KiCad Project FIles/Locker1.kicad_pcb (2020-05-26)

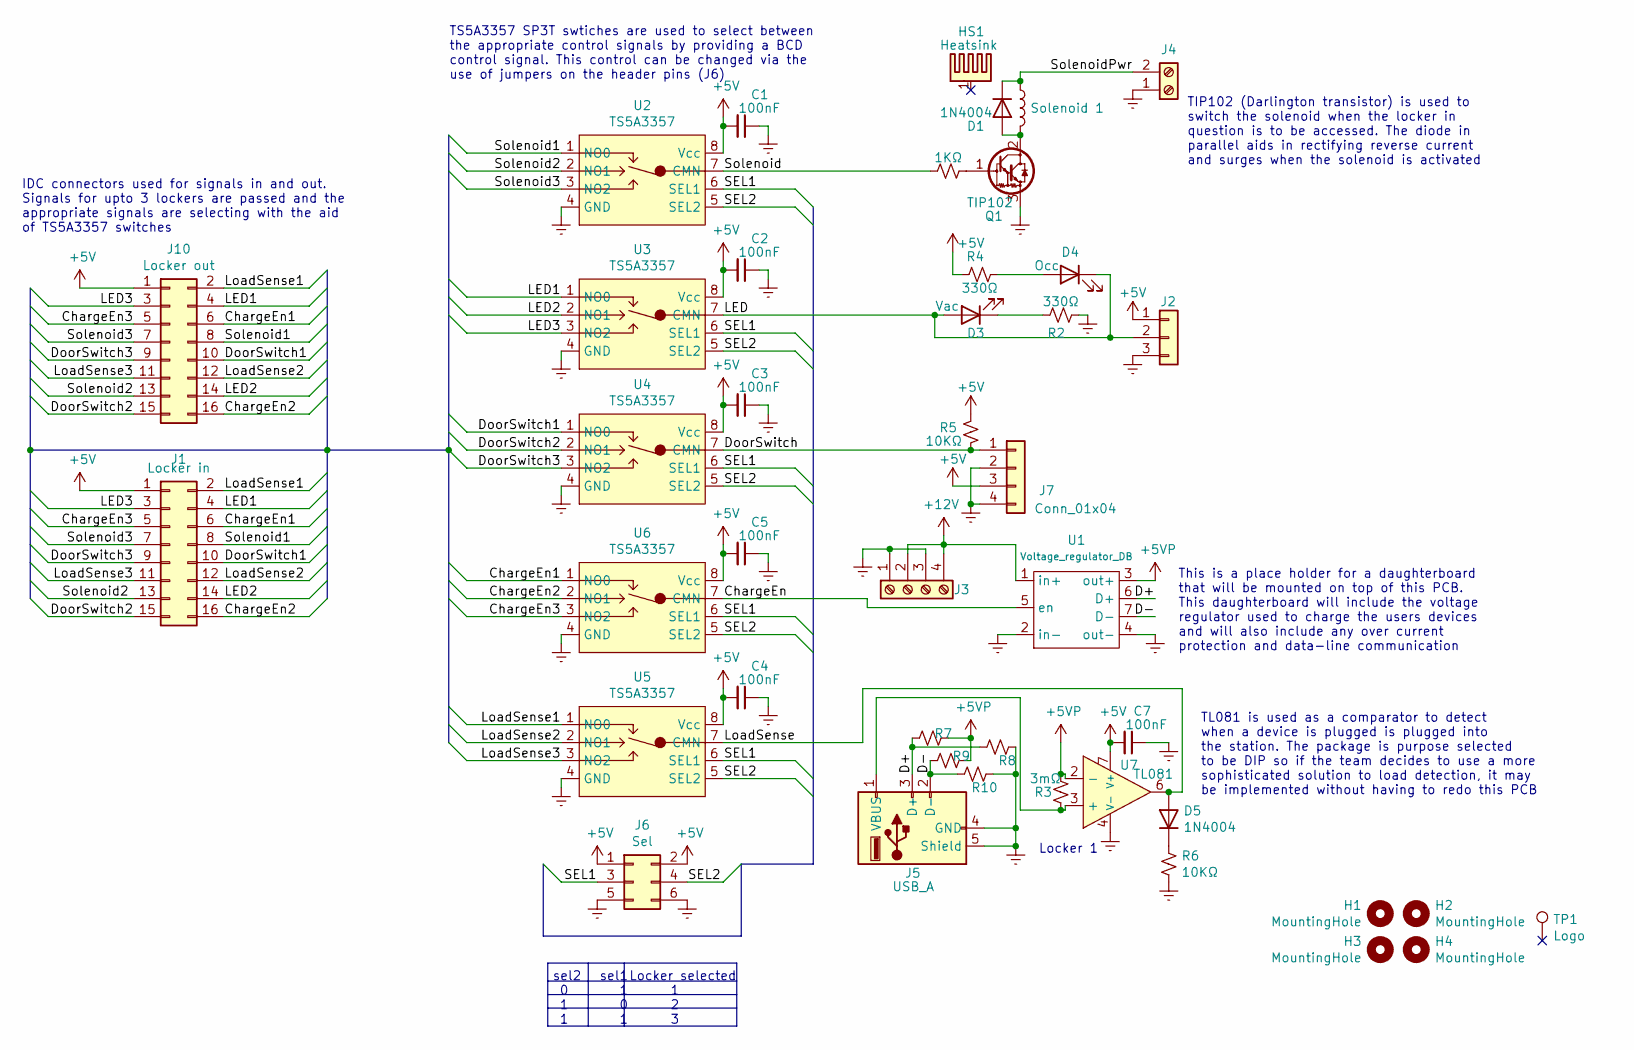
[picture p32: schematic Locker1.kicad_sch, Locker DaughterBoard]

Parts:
C1, C2, C3, C4, C5, C7: 100nF; C_0805_2012Metric_Pad1.15x1.40mm_HandSolder
D1, D5: 1N4004; D_SOD-123F
D3: Vac; LED_1206_3216Metric_Pad1.42x1.75mm_HandSolder
D4: Occ; LED_1206_3216Metric_Pad1.42x1.75mm_HandSolder
H1, H2, H3, H4: MountingHole; MountingHole_2.2mm_M2_Pad_Via
HS1: Heatsink; TO-220_Vertical_XSD_C116600
J1: Locker in; IDC-Header_2x08_P2.54mm_Vertical
J2: Conn_01x04; PinHeader_1x03_P2.54mm_Vertical
J3: Unreg 12V - charge; TerminalBlock_Altech_AK300-4_P5.00mm
J4: Solenoid Power; TerminalBlock_Altech_AK300-2_P5.00mm
J5: USB_A; USB_A_Stewart_SS-52100-001_Horizontal
J6: Sel; PinHeader_2x03_P2.54mm_Vertical
J7: Conn_01x04; PinHeader_2x02_P2.54mm_Vertical
J10: Locker out; IDC-Header_2x08_P2.54mm_Vertical
L1: Solenoid 1; TerminalBlock_Altech_AK300-2_P5.00mm
Q1: TIP102; TO-220-3_Vertical
R1: 1KΩ; R_0805_2012Metric_Pad1.15x1.40mm_HandSolder
R2, R4: 330Ω; R_0805_2012Metric_Pad1.15x1.40mm_HandSolder
R3: 3mΩ; R_0805_2012Metric_Pad1.15x1.40mm_HandSolder
R5, R6, R7, R8, R9, R10: 10KΩ; R_0805_2012Metric_Pad1.15x1.40mm_HandSolder
TP1: Logo; logoinv
U1: Voltage_regulator_DB; LM2576_DB
U2, U3, U4, U5, U6: TS5A3357; VSSOP-8_2.4x2.1mm_P0.5mm
U7: TL081; DIP-8_W7.62mm

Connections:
+5V: C1.2, C2.2, C3.2, C4.2, C5.2, C7.2, J1.1, J2.1, J6.1, J6.2, J7.3, J10.1, R4.2, R5.2, U2.8 (Vcc), U3.8 (Vcc), U4.8 (Vcc), U5.8 (Vcc), U6.8 (Vcc), U7.7 (V+)
+5VP: R3.1, R7.2, R9.2, U1.3 (out+), U7.2 (-)
+12V: J3.2, J3.4, U1.1 (in+)
/ChargeEn: U1.5 (en), U6.7 (CMN)
/ChargeEn1: J1.6, J10.6, U6.1 (NO0)
/ChargeEn2: J1.16, J10.16, U6.2 (NO1)
/ChargeEn3: J1.5, J10.5, U6.3 (NO2)
/D+: J5.3 (D+), R7.1, R8.2, U1.6 (D+)
/D-: J5.2 (D-), R9.1, R10.2, U1.7 (D-)
/DoorSwitch: J7.1, R5.1, U4.7 (CMN)
/DoorSwitch1: J1.10, J10.10, U4.1 (NO0)
/DoorSwitch2: J1.15, J10.15, U4.2 (NO1)
/DoorSwitch3: J1.9, J10.9, U4.3 (NO2)
/LED: D3.2 (A), D4.1 (K), J2.2, U3.7 (CMN)
/LED1: J1.4, J10.4, U3.1 (NO0)
/LED2: J1.14, J10.14, U3.2 (NO1)
/LED3: J1.3, J10.3, U3.3 (NO2)
/LoadSense: D5.2 (A), U5.7 (CMN), U7.6
/LoadSense1: J1.2, J10.2, U5.1 (NO0)
/LoadSense2: J1.12, J10.12, U5.2 (NO1)
/LoadSense3: J1.11, J10.11, U5.3 (NO2)
/SEL1: J6.3, U2.6 (SEL1), U3.6 (SEL1), U4.6 (SEL1), U5.6 (SEL1), U6.6 (SEL1)
/SEL2: J6.4, U2.5 (SEL2), U3.5 (SEL2), U4.5 (SEL2), U5.5 (SEL2), U6.5 (SEL2)
/Solenoid: R1.1, U2.7 (CMN)
/Solenoid1: J1.8, J10.8, U2.1 (NO0)
/Solenoid2: J1.13, J10.13, U2.2 (NO1)
/Solenoid3: J1.7, J10.7, U2.3 (NO2)
/SolenoidPwr: D1.1 (K), J4.2, L1.1
GNDREF: C1.1, C2.1, C3.1, C4.1, C5.1, C7.1, J2.3, J3.1, J3.3, J4.1, J5.4 (GND), J5.5 (Shield), J6.5, J6.6, J7.2, J7.4, Q1.3 (E), R2.2, R6.2, R8.1, R10.1, U1.2 (in-), U1.4 (out-), U2.4 (GND), U3.4 (GND), U4.4 (GND), U5.4 (GND), U6.4 (GND), U7.4 (V-)
unnamed: D1.2 (A), L1.2, Q1.2 (C)
unnamed: D3.1 (K), R2.1
unnamed: D4.2 (A), R4.1
unnamed: D5.1 (K), R6.1
unnamed: J5.1 (VBUS), R3.2, U7.3 (+)
unnamed: Q1.1 (B), R1.2

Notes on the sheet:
IDC connectors used for signals in and out. Signals for upto 3 lockers are passed and the appropriate signals are selecting with the aid of TS5A3357 switches
TS5A3357 SP3T swtiches are used to select between the appropriate control signals by providing a BCD control signal. This control can be changed via the use of jumpers on the header pins (J6)
sel2 0 1 1
Locker selected 1 2 3
sel1 1 0 1
Locker 1
This is a place holder for a daughterboard that will be mounted on top of this PCB. This daughterboard will include the voltage regulator used to charge the users devices and will also include any over current protection and data-line communication
TIP102 (Darlington transistor) is used to switch the solenoid when the locker in question is to be accessed. The diode in parallel aids in rectifying reverse current and surges when the solenoid is activated
TL081 is used as a comparator to detect when a device is plugged is plugged into the station. The package is purpose selected to be DIP so if the team decides to use a more sophisticated solution to load detection, it may be implemented without having to redo this PCB

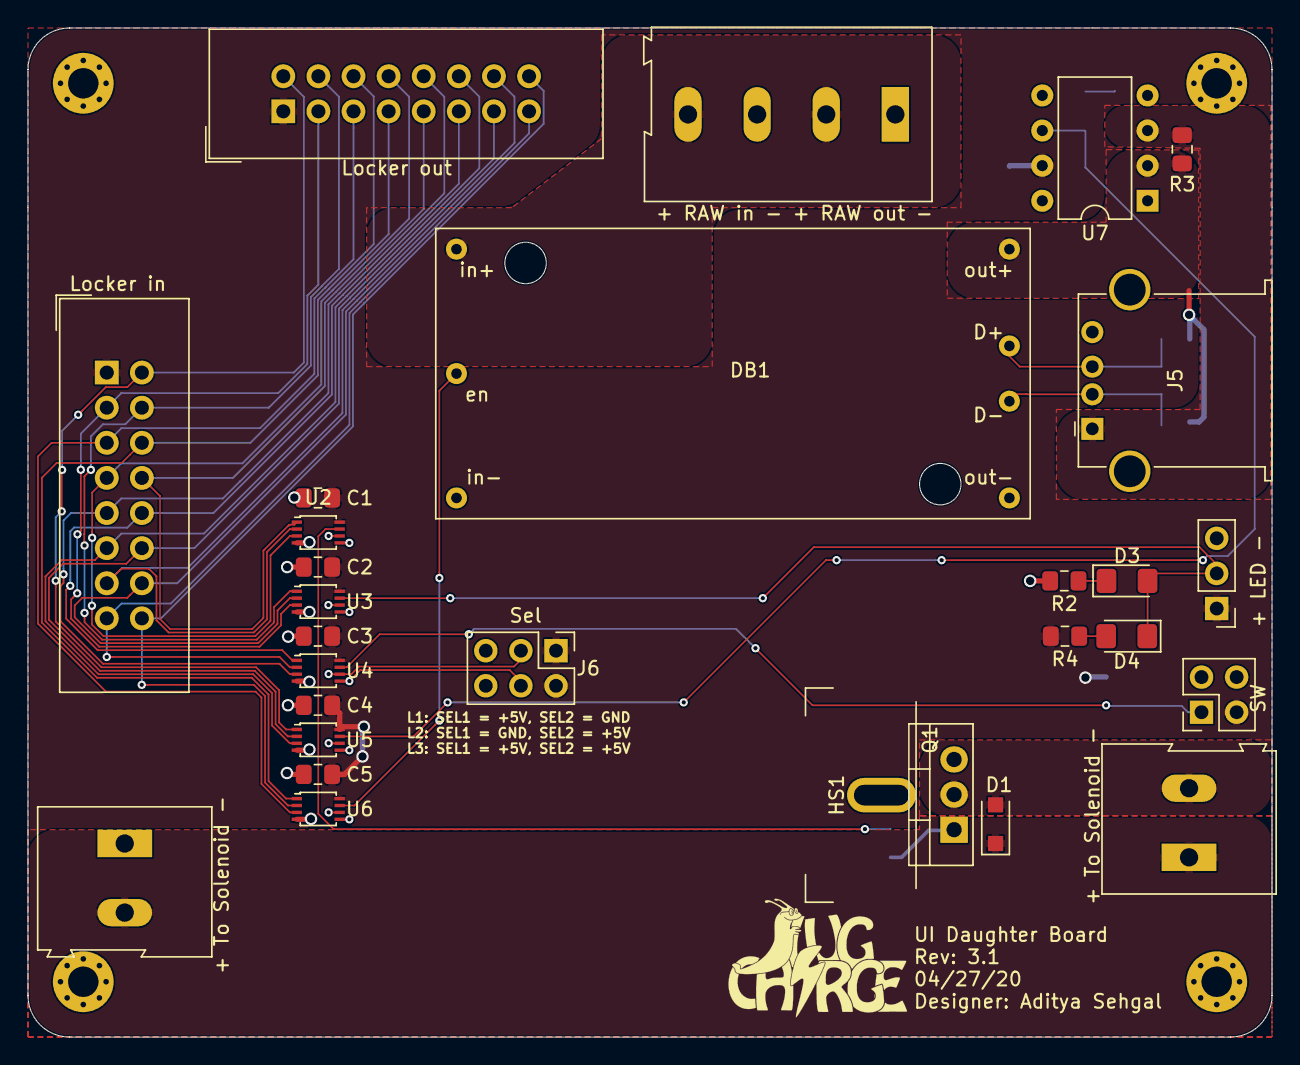
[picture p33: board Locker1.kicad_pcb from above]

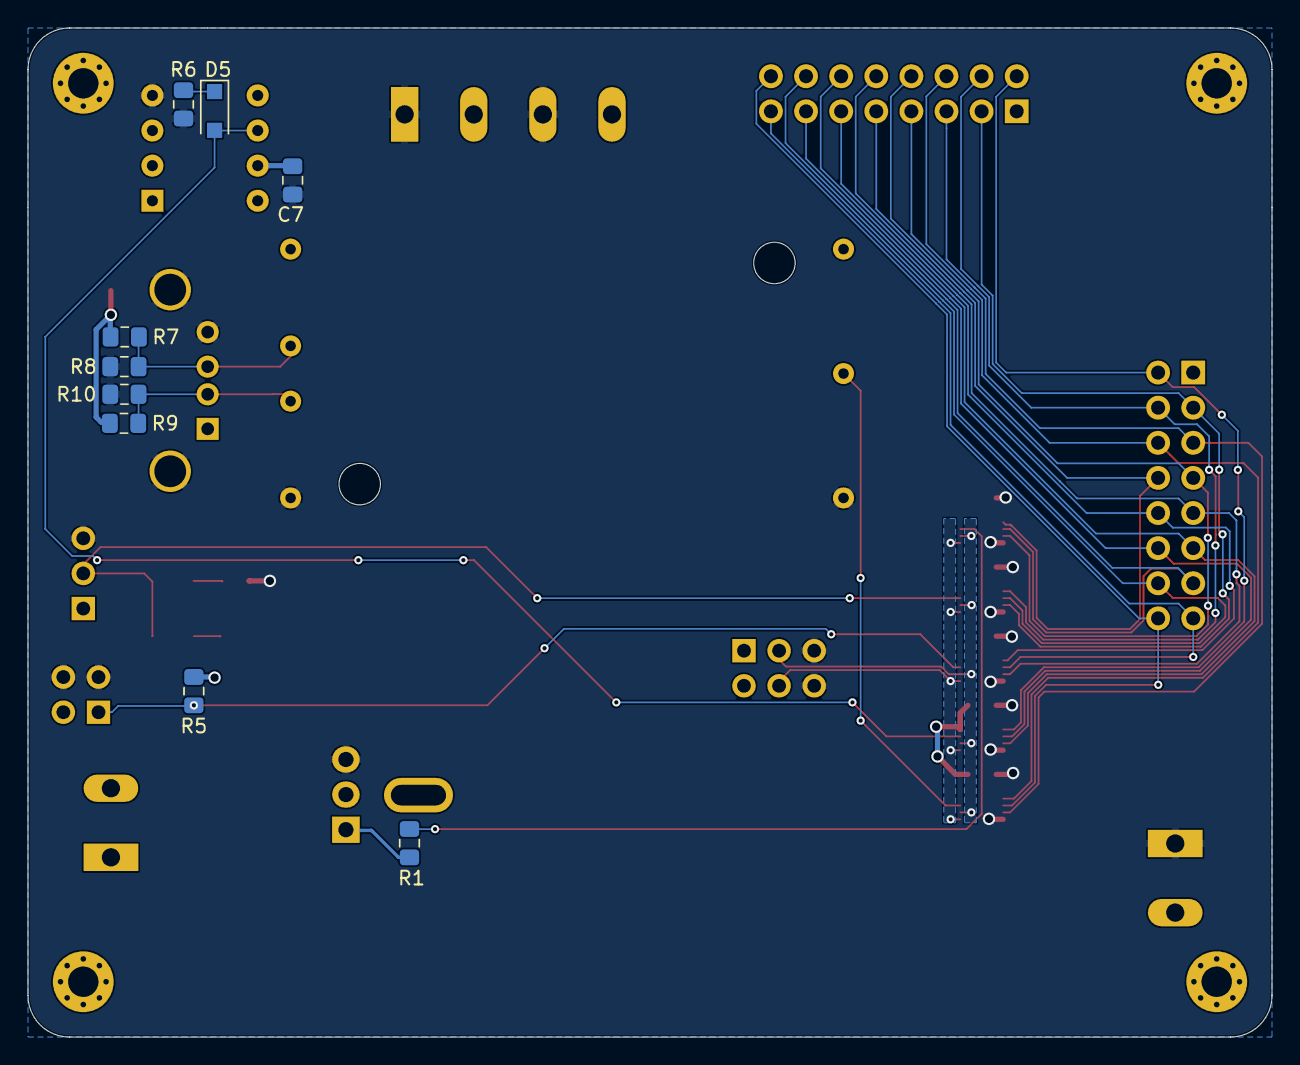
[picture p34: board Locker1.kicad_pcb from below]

Board: 2 copper layers, 90.0 x 73.0 mm, 43 parts (9 on the bottom side), 35 nets.

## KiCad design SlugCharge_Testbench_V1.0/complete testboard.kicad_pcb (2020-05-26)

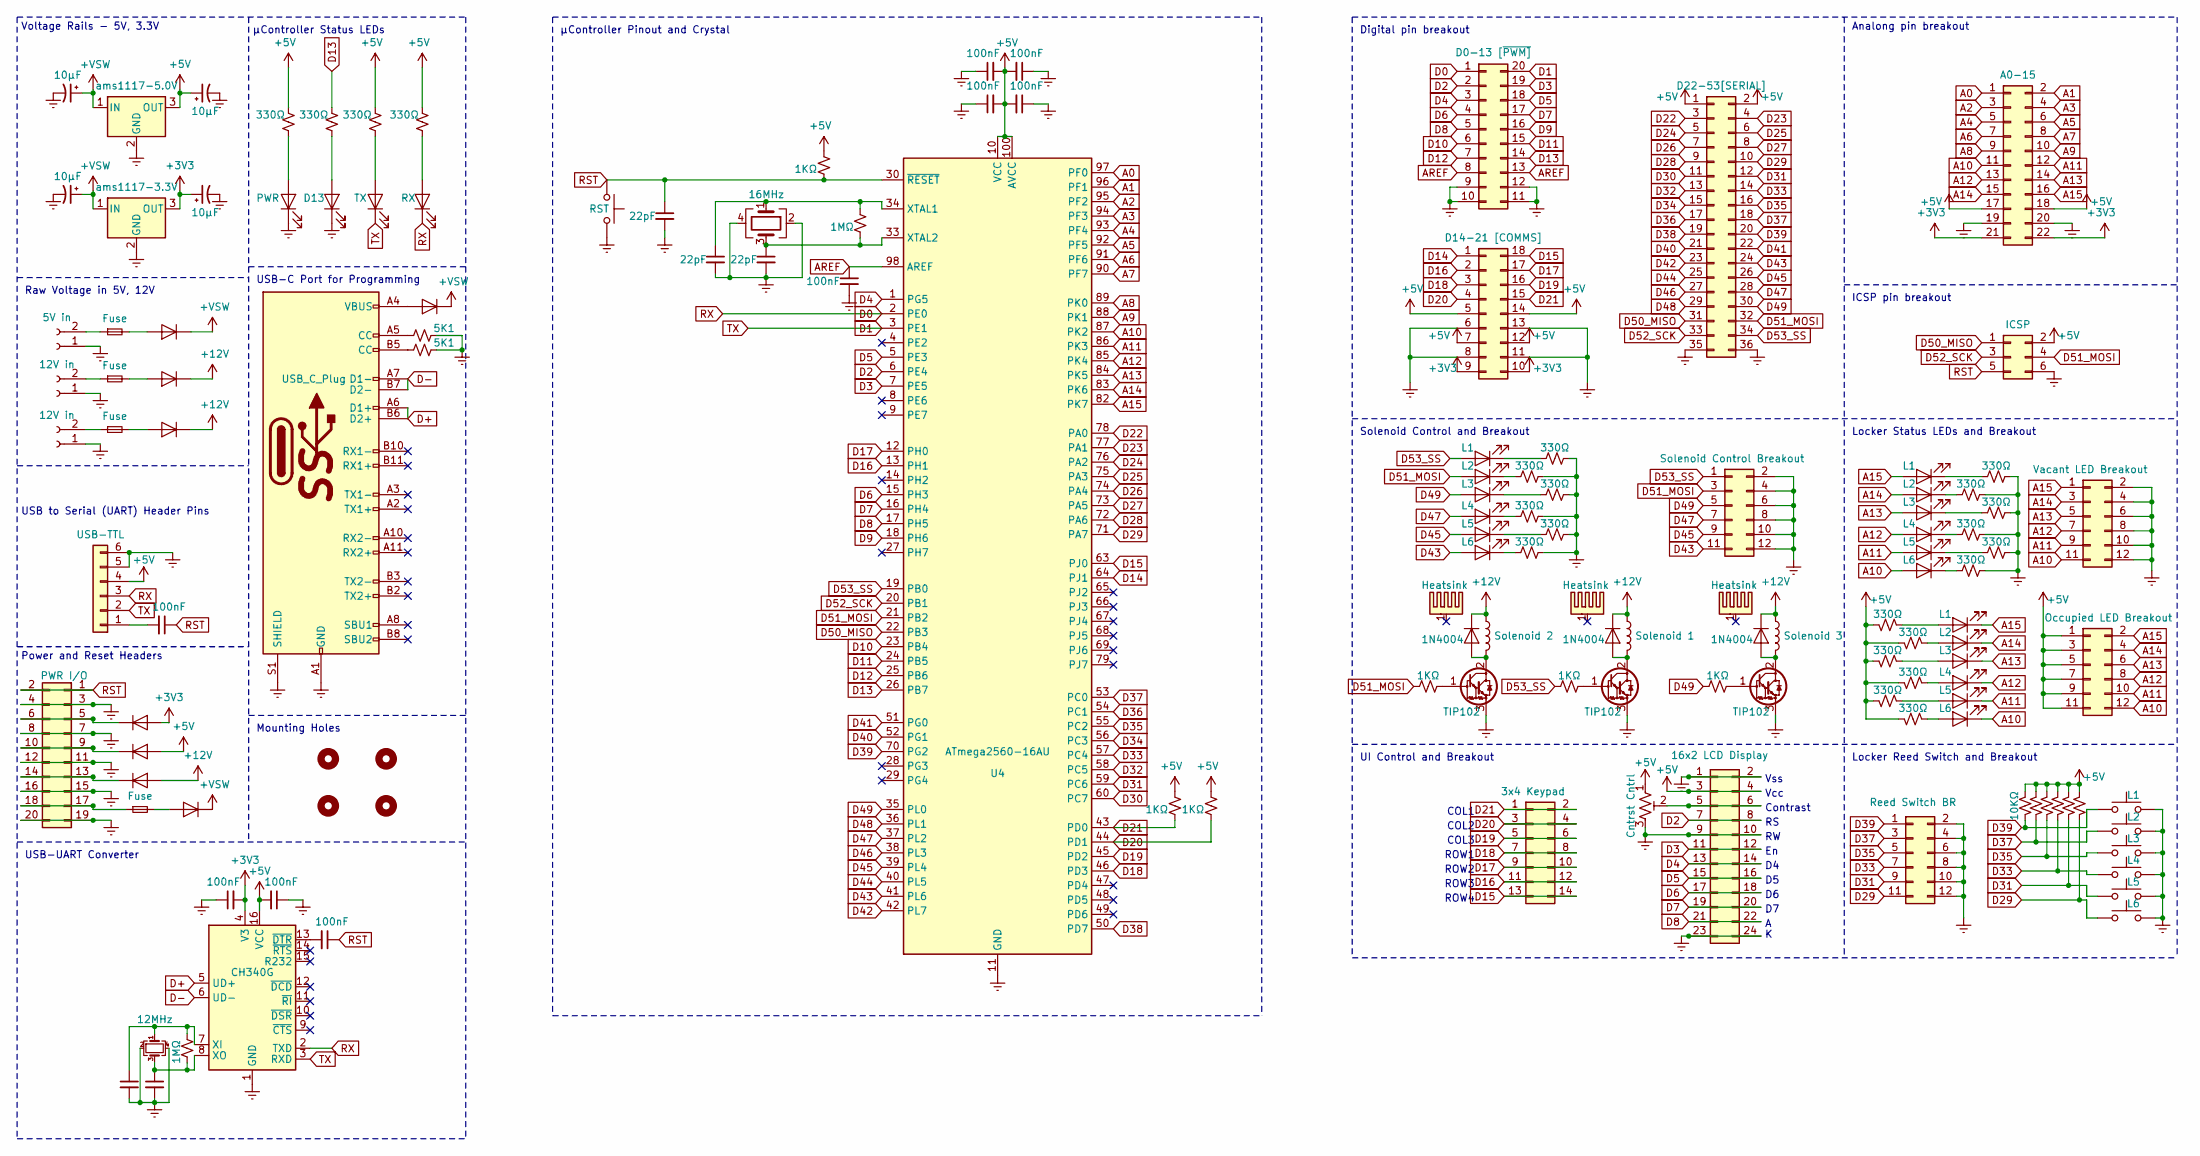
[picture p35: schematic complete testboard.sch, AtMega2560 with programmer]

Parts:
C1, C4, C7, C8: 10µF; C_Elec_4x5.4
C2, C3, C5, C6, C12, C13, C14, C15, C16: 100nF; C_0805_2012Metric_Pad1.15x1.40mm_HandSolder
C9, C10, C11, C17, C18: 22pF; C_0805_2012Metric_Pad1.15x1.40mm_HandSolder
D1, D2, D3, D25, D26, D27, D28, D29: D; D_SOD-123F
D4, D6, D17: L1; LED_0805_2012Metric_Pad1.15x1.40mm_HandSolder
D5, D8, D20: L2; LED_0805_2012Metric_Pad1.15x1.40mm_HandSolder
D7, D9, D21: L3; LED_0805_2012Metric_Pad1.15x1.40mm_HandSolder
D10, D12, D22: L4; LED_0805_2012Metric_Pad1.15x1.40mm_HandSolder
D11, D15, D23: L5; LED_0805_2012Metric_Pad1.15x1.40mm_HandSolder
D13: D13; LED_0805_2012Metric_Pad1.15x1.40mm_HandSolder
D14, D16, D24: L6; LED_0805_2012Metric_Pad1.15x1.40mm_HandSolder
D18, D19, D30: 1N4004; D_SOD-123F
F1, F2, F3, F4: Fuse; Fuse_1812_4532Metric_Pad1.30x3.40mm_HandSolder
H1, H2, H3, H4: MountingHole; MountingHole_3.2mm_M3_Pad_Via
HS1, HS2, HS3: Heatsink; TO-220 Vertical XSD C116600
J1: D14-21 [COMMS]; PinHeader_2x09_P2.54mm_Vertical
J2: D22-53[SERIAL]; PinHeader_2x18_P2.54mm_Vertical
J3: D0-13 [~PWM]; PinHeader_2x10_P2.54mm_Vertical
J4: 5V in; PinHeader_1x02_P2.54mm_Vertical
J5: A0-15; PinHeader_2x11_P2.54mm_Vertical
J6, J7: 12V in; PinHeader_1x02_P2.54mm_Vertical
J8: Solenoid Control Breakout; PinHeader_2x06_P2.54mm_Vertical
J9: Vacant LED Breakout; PinHeader_2x06_P2.54mm_Vertical
J10: USB-TTL; PinSocket_1x06_P2.54mm_Vertical
J11: Occupied LED Breakout; PinHeader_2x06_P2.54mm_Vertical
J12: PWR I/O; PinHeader_2x10_P2.54mm_Vertical
J13: 16x2 LCD Display; PinSocket_2x12_P2.54mm_Vertical
J14: 3x4 Keypad; PinHeader_2x07_P2.54mm_Vertical
J15: Reed Switch BR; PinHeader_2x06_P2.54mm_Vertical
J16: ICSP; PinHeader_2x03_P2.54mm_Vertical
L1: Solenoid 1; JST_EH_B2B-EH-A_1x02_P2.50mm_Vertical
L2: Solenoid 2; JST_EH_B2B-EH-A_1x02_P2.50mm_Vertical
L3: Solenoid 3; JST_EH_B2B-EH-A_1x02_P2.50mm_Vertical
P1: USB_C_Plug; USB C C167321
PWR1: PWR; LED_0805_2012Metric_Pad1.15x1.40mm_HandSolder
Q1, Q2, Q3: TIP102; TO-220-3_Vertical
R1, R7, R8, R27, R28, R38: 1KΩ; R_0805_2012Metric_Pad1.15x1.40mm_HandSolder
R2, R37: 1MΩ; R_0805_2012Metric_Pad1.15x1.40mm_HandSolder
R3, R6: 5K1; R_0805_2012Metric_Pad1.15x1.40mm_HandSolder
R4, R5, R9, R10, R11, R12, R13, R14, R15, R16, R17, R18, R19, R20, R21, R22, R23, R24, R25, R26, R29, R30: 330Ω; R_0805_2012Metric_Pad1.15x1.40mm_HandSolder
R31, R32, R33, R34, R35, R36: 10KΩ; R_0805_2012Metric_Pad1.15x1.40mm_HandSolder
RV1: Cntrst Cntrl; Potentiometer_Runtron_RM-065_Vertical
RX1: RX; LED_0805_2012Metric_Pad1.15x1.40mm_HandSolder
SW1: RST; SW_SPST_TL3342
SW2: L1; PTS810_4.2x3.2
SW3: L2; PTS810_4.2x3.2
SW4: L3; PTS810_4.2x3.2
SW5: L4; PTS810_4.2x3.2
SW6: L5; PTS810_4.2x3.2
SW7: L6; PTS810_4.2x3.2
TX1: TX; LED_0805_2012Metric_Pad1.15x1.40mm_HandSolder
U1: ams1117-5.0V; SOT-223-3_TabPin2
U2: ams1117-3.3V; SOT-223-3_TabPin2
U3: CH340G; SOIC-16_3.9x9.9mm_P1.27mm
U4: ATmega2560-16AU; TQFP-100_14x14mm_P0.5mm
Y1: 16MHz; Crystal_SMD_3225-4Pin_3.2x2.5mm_HandSoldering
Y2: 12MHz; Crystal_SMD_3225-4Pin_3.2x2.5mm_HandSoldering

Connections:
+3V3: C8.1, C14.2, D25.2 (A), J1.9, J1.10, J5.21, J5.22, U2.3 (OUT), U3.4 (V3)
+5V: C2.2, C3.2, C4.1, C5.2, C6.2, C15.2, D26.2 (A), J1.5, J1.7, J1.12, J1.14, J2.1, J2.2, J5.17, J5.18, J10.4, J11.1, J11.3, J11.5, J11.7, J11.9, J11.11, J13.3, J13.4, J16.2, R1.2, R4.2, R7.2, R8.2, R9.2, R10.2, R23.2, R24.2, R25.2, R26.2, R29.2, R30.2, R31.2, R32.2, R33.2, R34.2, R35.2, R36.2, RV1.1, U1.3 (OUT), U3.16 (VCC), U4.10 (VCC), U4.31 (VCC), U4.61 (VCC), U4.80 (VCC), U4.100 (AVCC)
+12V: D2.1 (K), D3.1 (K), D18.1 (K), D19.1 (K), D27.2 (A), D30.1 (K), L1.1, L2.1, L3.1
+VSW: C1.1, C7.1, D1.1 (K), D28.1 (K), D29.1 (K), U1.1 (IN), U2.1 (IN)
A0: J5.1, U4.97 (PF0)
A1: J5.2, U4.96 (PF1)
A2: J5.3, U4.95 (PF2)
A3: J5.4, U4.94 (PF3)
A4: J5.5, U4.93 (PF4)
A5: J5.6, U4.92 (PF5)
A6: J5.7, U4.91 (PF6)
A7: J5.8, U4.90 (PF7)
A8: J5.9, U4.89 (PK0)
A9: J5.10, U4.88 (PK1)
A10: D16.2 (A), D24.1 (K), J5.11, J9.11, J11.12, U4.87 (PK2)
A11: D15.2 (A), D23.1 (K), J5.12, J9.9, J11.10, U4.86 (PK3)
A12: D12.2 (A), D22.1 (K), J5.13, J9.7, J11.8, U4.85 (PK4)
A13: D9.2 (A), D21.1 (K), J5.14, J9.5, J11.6, U4.84 (PK5)
A14: D8.2 (A), D20.1 (K), J5.15, J9.3, J11.4, U4.83 (PK6)
A15: D6.2 (A), D17.1 (K), J5.16, J9.1, J11.2, U4.82 (PK7)
AREF: C12.1, J3.8, J3.13, U4.98 (AREF)
D0: J3.1, J10.3, RX1.1 (K), U3.2 (TXD), U4.2 (PE0)
D1: J3.20, J10.2, TX1.1 (K), U3.3 (RXD), U4.3 (PE1)
D2: J3.2, J13.7, J13.8, U4.6 (PE4)
D3: J3.19, J13.11, J13.12, U4.7 (PE5)
D4: J3.3, J13.13, J13.14, U4.1 (PG5)
D5: J3.18, J13.15, J13.16, U4.5 (PE3)
D6: J3.4, J13.17, J13.18, U4.15 (PH3)
D7: J3.17, J13.19, J13.20, U4.16 (PH4)
D8: J3.5, J13.21, J13.22, U4.17 (PH5)
D9: J3.16, U4.18 (PH6)
D10: J3.6, U4.23 (PB4)
D11: J3.15, U4.24 (PB5)
D12: J3.7, U4.25 (PB6)
D13: J3.14, R5.2, U4.26 (PB7)
D14: J1.1, U4.64 (PJ1)
D15: J1.18, J14.13, J14.14, U4.63 (PJ0)
D16: J1.2, J14.11, J14.12, U4.13 (PH1)
D17: J1.17, J14.9, J14.10, U4.12 (PH0)
D18: J1.3, J14.7, J14.8, U4.46 (PD3)
D19: J1.16, J14.5, J14.6, U4.45 (PD2)
D20: J1.4, J14.3, J14.4, R8.1, U4.44 (PD1)
D21: J1.15, J14.1, J14.2, R7.1, U4.43 (PD0)
D22: J2.3, U4.78 (PA0)
D23: J2.4, U4.77 (PA1)
D24: J2.5, U4.76 (PA2)
D25: J2.6, U4.75 (PA3)
D26: J2.7, U4.74 (PA4)
D27: J2.8, U4.73 (PA5)
D28: J2.9, U4.72 (PA6)
D29: J2.10, J15.11, R36.1, SW7.1, U4.71 (PA7)
D30: J2.11, U4.60 (PC7)
D31: J2.12, J15.9, R35.1, SW6.1, U4.59 (PC6)
D32: J2.13, U4.58 (PC5)
D33: J2.14, J15.7, R34.1, SW5.1, U4.57 (PC4)
D34: J2.15, U4.56 (PC3)
D35: J2.16, J15.5, R33.1, SW4.1, U4.55 (PC2)
D36: J2.17, U4.54 (PC1)
D37: J2.18, J15.3, R32.1, SW3.1, U4.53 (PC0)
D38: J2.19, U4.50 (PD7)
D39: J2.20, J15.1, R31.1, SW2.1, U4.70 (PG2)
D40: J2.21, U4.52 (PG1)
D41: J2.22, U4.51 (PG0)
D42: J2.23, U4.42 (PL7)
D43: D14.2 (A), J2.24, J8.11, U4.41 (PL6)
D44: J2.25, U4.40 (PL5)
D45: D11.2 (A), J2.26, J8.9, U4.39 (PL4)
D46: J2.27, U4.38 (PL3)
D47: D10.2 (A), J2.28, J8.7, U4.37 (PL2)
D48: J2.29, U4.36 (PL1)
D49: D7.2 (A), J2.30, J8.5, R38.1, U4.35 (PL0)
D50_MISO: J2.31, J16.1, U4.22 (PB3)
D51_MOSI: D5.2 (A), J2.32, J8.3, J16.4, R28.1, U4.21 (PB2)
D52_SCK: J2.33, J16.3, U4.20 (PB1)
D53_SS: D4.2 (A), J2.34, J8.1, R27.1, U4.19 (PB0)
D+: P1.A6 (D1+), P1.B6 (D2+), U3.5 (UD+)
D-: P1.A7 (D1-), P1.B7 (D2-), U3.6 (UD-)
GNDREF: C1.2, C2.1, C3.1, C4.2, C5.1, C6.1, C7.2, C8.2, C9.2, C10.2, C11.2, C12.2, C14.1, C15.1, C17.2, C18.2, D13.1 (K), J1.6, J1.8, J1.11, J1.13, J2.35, J2.36, J3.9, J3.10, J3.11, J3.12, J4.1, J5.19, J5.20, J6.1, J7.1, J8.2, J8.4, J8.6, J8.8, J8.10, J8.12, J9.2, J9.4, J9.6, J9.8, J9.10, J9.12, J10.5, J10.6, J12.3, J12.4, J12.7, J12.8, J12.11, J12.12, J12.15, J12.16, J12.19, J12.20, J13.1, J13.2, J13.9, J13.10, J13.23, J13.24, J15.2, J15.4, J15.6, J15.8, J15.10, J15.12, J16.6, P1.A1 (GND), P1.A12 (GND), P1.B1 (GND), P1.B12 (GND), P1.S1 (SHIELD), PWR1.1 (K), Q1.3 (E), Q2.3 (E), Q3.3 (E), R3.2, R6.2, R11.2, R12.2, R13.2, R14.2, R15.2, R16.2, R17.2, R18.2, R19.2, R20.2, R21.2, R22.2, RV1.3, SW1.2, SW2.2, SW3.2, SW4.2, SW5.2, SW6.2, SW7.2, U1.2 (GND), U2.2 (GND), U3.1 (GND), U4.11 (GND), U4.32 (GND), U4.62 (GND), U4.81 (GND), U4.99 (GND), Y1.2, Y1.4, Y2.2, Y2.4
unnamed: C9.1, R2.2, U4.34 (XTAL1), Y1.1
unnamed: C10.1, R2.1, U4.33 (XTAL2), Y1.3
unnamed: C13.2, J10.1
unnamed: C16.2, U3.13 (~DTR)
unnamed: C17.1, R37.2, U3.7 (XI), Y2.1
unnamed: C18.1, R37.1, U3.8 (XO), Y2.3
unnamed: D1.2 (A), F1.2
unnamed: D2.2 (A), F2.2
unnamed: D3.2 (A), F3.2
unnamed: D4.1 (K), R11.1
unnamed: D5.1 (K), R12.1
unnamed: D6.1 (K), R13.1
unnamed: D7.1 (K), R14.1
unnamed: D8.1 (K), R15.1
unnamed: D9.1 (K), R16.1
unnamed: D10.1 (K), R17.1
unnamed: D11.1 (K), R18.1
unnamed: D12.1 (K), R19.1
unnamed: D13.2 (A), R5.1
unnamed: D14.1 (K), R20.1
unnamed: D15.1 (K), R21.1
unnamed: D16.1 (K), R22.1
unnamed: D17.2 (A), R23.1
unnamed: D18.2 (A), L1.2, Q1.2 (C)
unnamed: D19.2 (A), L2.2, Q2.2 (C)
unnamed: D20.2 (A), R24.1
unnamed: D21.2 (A), R25.1
unnamed: D22.2 (A), R26.1
unnamed: D23.2 (A), R29.1
unnamed: D24.2 (A), R30.1
unnamed: D25.1 (K), J12.5, J12.6
unnamed: D26.1 (K), J12.9, J12.10
unnamed: D27.1 (K), J12.13, J12.14
unnamed: D28.2 (A), F4.2
unnamed: D29.2 (A), P1.A4 (VBUS), P1.A9 (VBUS), P1.B4 (VBUS), P1.B9 (VBUS)
unnamed: D30.2 (A), L3.2, Q3.2 (C)
unnamed: F1.1, J4.2
unnamed: F2.1, J6.2
unnamed: F3.1, J7.2
unnamed: F4.1, J12.17, J12.18
unnamed: J13.5, J13.6, RV1.2
unnamed: P1.A5 (CC), R3.1
unnamed: P1.B5 (CC), R6.1
unnamed: PWR1.2 (A), R4.1
unnamed: Q1.1 (B), R27.2
unnamed: Q2.1 (B), R28.2
unnamed: Q3.1 (B), R38.2
unnamed: R9.1, TX1.2 (A)
unnamed: R10.1, RX1.2 (A)
RST: C11.1, C13.1, C16.1, J12.1, J12.2, J16.5, R1.1, SW1.1, U4.30 (~RESET)

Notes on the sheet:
Voltage Rails - 5V, 3.3V
µController Status LEDs
Digital pin breakout
Analong pin breakout
ICSP pin breakout
Power and Reset Headers
USB to Serial (UART) Header Pins
Locker Status LEDs and Breakout
Vss
Vcc
Contrast
COL1
ROW4
ROW3
ROW2
ROW1
COL3
COL2
Solenoid Control and Breakout
Locker Reed Switch and Breakout
UI Control and Breakout
µController Pinout and Crystal
Raw Voltage in 5V, 12V
USB-C Port for Programming
USB-UART Converter
Mounting Holes

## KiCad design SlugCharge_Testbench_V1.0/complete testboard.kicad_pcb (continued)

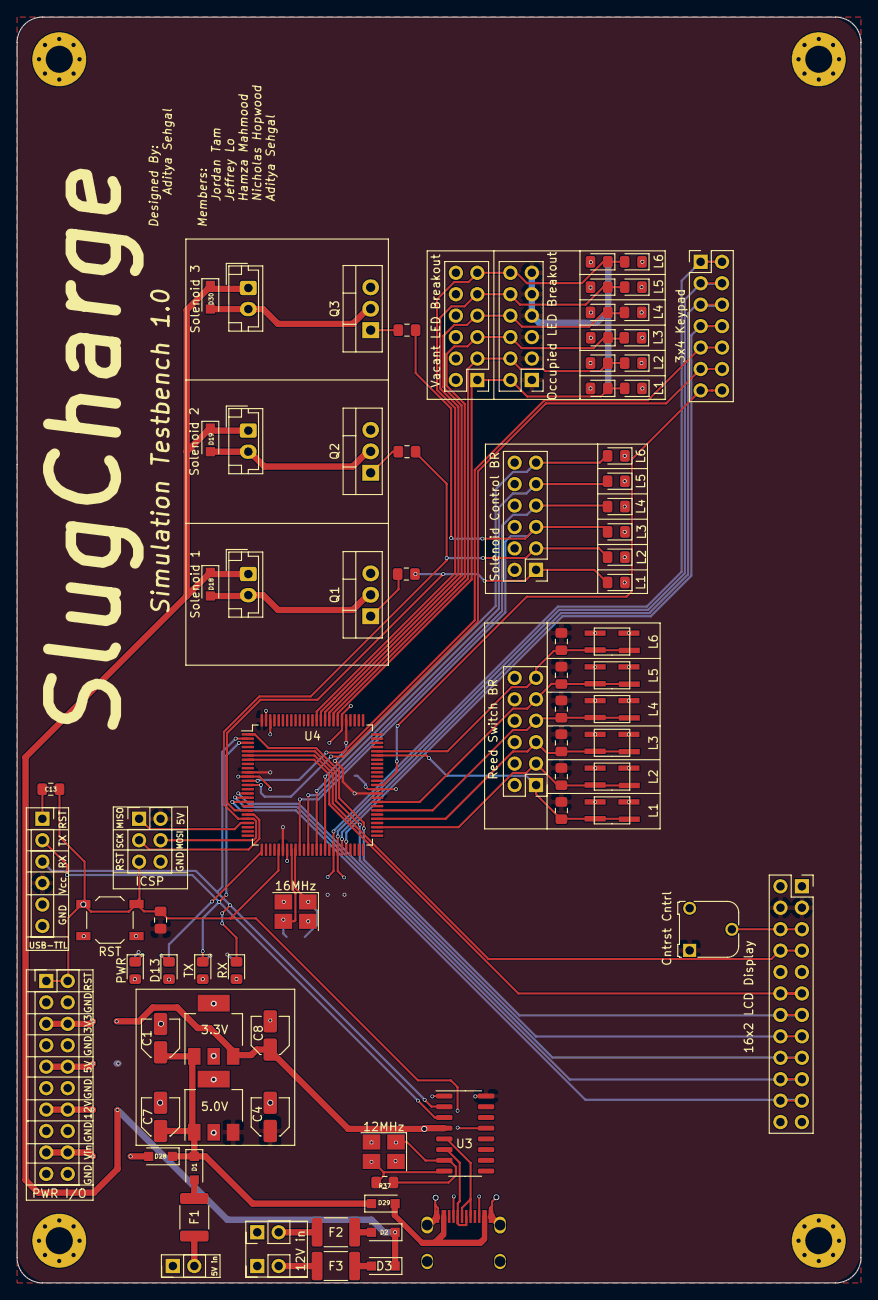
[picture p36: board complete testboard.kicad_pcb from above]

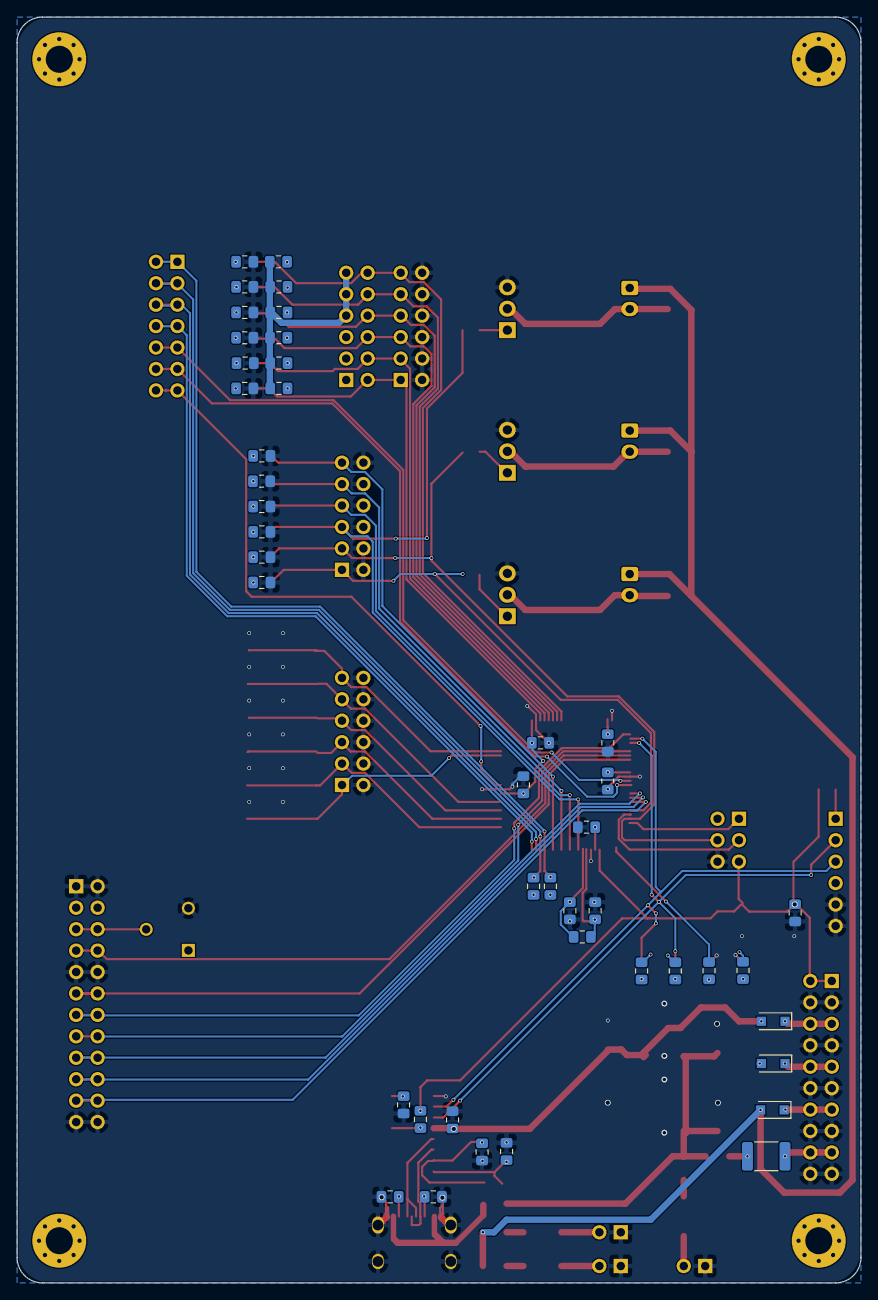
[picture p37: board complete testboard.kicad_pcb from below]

Board: 2 copper layers, 100.0 x 150.0 mm, 130 parts (44 on the bottom side), 95 nets.

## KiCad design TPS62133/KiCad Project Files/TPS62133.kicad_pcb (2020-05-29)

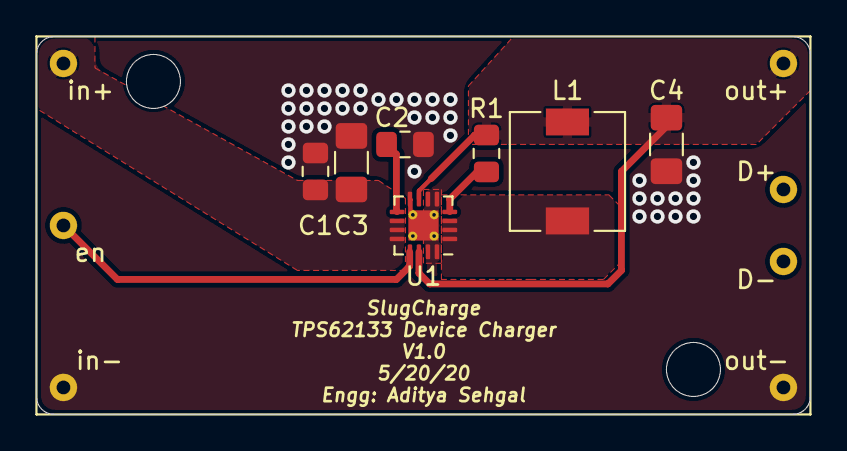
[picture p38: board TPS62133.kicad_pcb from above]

Board: 2 copper layers, 43.0 x 21.0 mm, 8 parts (0 on the bottom side), 7 nets.

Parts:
C1: 100nF; C_0805_2012Metric_Pad1.15x1.40mm_HandSolder
C2: 620pF; C_0805_2012Metric_Pad1.15x1.40mm_HandSolder
C3: 10µF; C_1206_3216Metric_Pad1.42x1.75mm_HandSolder
C4: 22µF; C_1206_3216Metric_Pad1.42x1.75mm_HandSolder
DB1: DB_42x21; DB_43x21
L1: 2.2µH; L_6.3x6.3_H3
R1: 100K; R_0805_2012Metric_Pad1.15x1.40mm_HandSolder
U1: TPS62133; VQFN-16-1EP_3x3mm_P0.5mm_EP1.68x1.68mm_ThermalVias

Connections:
/+5V: C4.1, DB1.3 (out+), L1.2, R1.2, U1.7 (FSW), U1.14 (VOS)
/EN: DB1.5 (en), U1.13 (en)
/Vin: C1.1, C3.1, DB1.1 (in+), U1.10 (AVin), U1.11 (PVin), U1.12 (PVin)
GNDREF: C1.2, C2.2, C3.2, C4.2, DB1.2 (GND), DB1.4 (GND), U1.5 (FB), U1.6 (AGND), U1.8 (DEF), U1.15 (PGND), U1.16 (PGND), U1.17 (EP)
unnamed: C2.1, U1.9 (SS_TR)
unnamed: L1.1, U1.1 (SW), U1.2 (SW), U1.3 (SW)
unnamed: R1.1, U1.4 (PG)

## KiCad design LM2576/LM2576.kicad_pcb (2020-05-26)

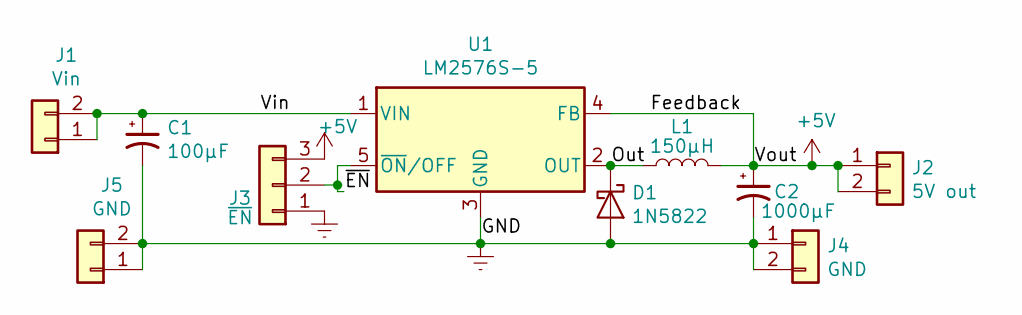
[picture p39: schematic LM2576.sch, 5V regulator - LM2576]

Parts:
C1: 100µF; C_Elec_8x10.2
C2: 1000µF; C_Elec_10x10.2
D1: 1N5822; D_DO-201AD_P15.24mm_Horizontal
J1: Vin; PinHeader_1x02_P2.54mm_Vertical
J2: 5V out; PinHeader_1x02_P2.54mm_Vertical
J3: ~EN; PinHeader_1x03_P2.54mm_Vertical
J4, J5: GND; PinHeader_1x02_P2.54mm_Vertical
L1: 150µH; L_Radial_D14.2mm_P10.00mm_Neosid_SD14
U1: LM2576S-5; TO-263-5_TabPin3

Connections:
+5V: C2.1, J2.1, J2.2, J3.3, L1.2, U1.4 (FB)
/Out: D1.1 (K), L1.1, U1.2 (OUT)
/Vin: C1.1, J1.1, J1.2, U1.1 (VIN)
/~EN: J3.2, U1.5 (~ON~/OFF)
GNDREF: C1.2, C2.2, D1.2 (A), J3.1, J4.1, J4.2, J5.1, J5.2, U1.3 (GND)

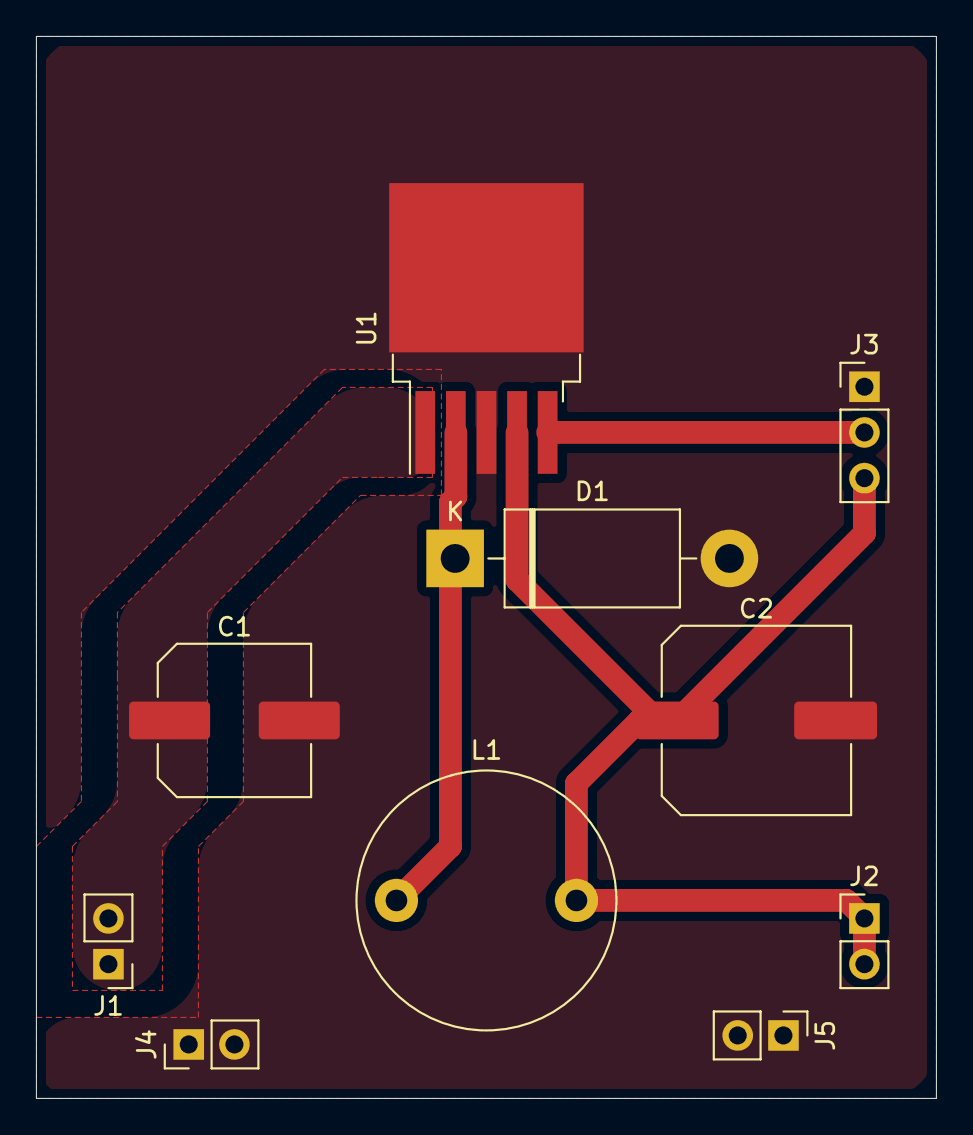
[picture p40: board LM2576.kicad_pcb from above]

Board: 2 copper layers, 50.0 x 59.0 mm, 10 parts (0 on the bottom side), 5 nets.

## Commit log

2020-05-26 Pushed all final project files
    [BOM.xlsx, DB_BOM.csv, DB_BOM.xlsx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]
2020-05-29 updated TPS62133
    [Locker1.kicad_pcb, Locker1.kicad_sch, MB_BOM.csv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]
2020-06-05 added 3d drawings
    [Locker1.kicad_sch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]
2020-08-07 ReadMe in progress
    [BOM.xlsx, KEYPAD.kicad_pcb, KEYPAD.sch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]
2020-08-07 PCB #1 complete
2020-08-07 README PCB Section Complete
    [DB_BOM.csv, DB_BOM.xlsx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]
2020-10-13 pushed regulator seletion
